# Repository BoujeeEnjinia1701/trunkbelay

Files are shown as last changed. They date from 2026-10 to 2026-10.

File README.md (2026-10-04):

# TrunkBelay

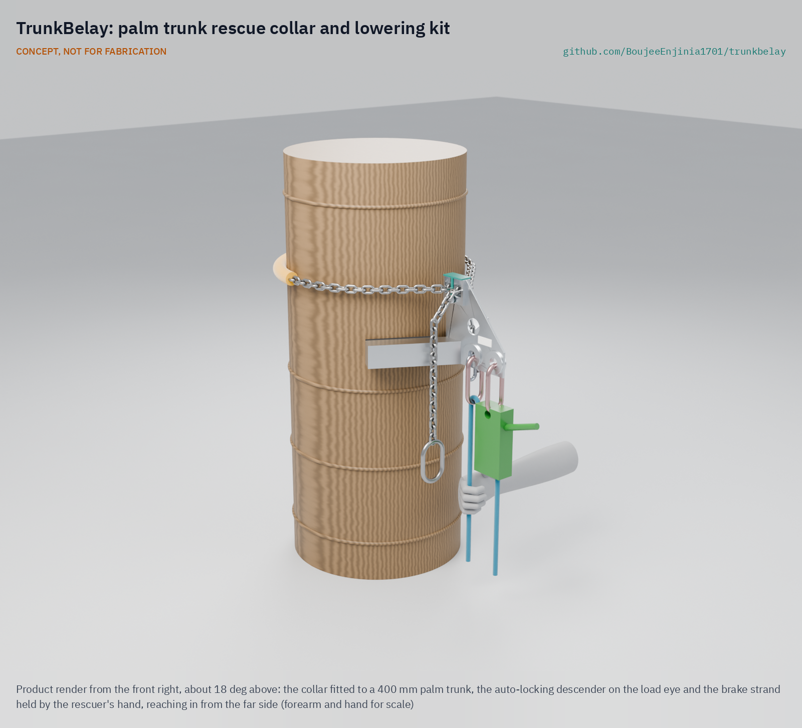
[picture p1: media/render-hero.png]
TrunkBelay: palm trunk rescue collar and lowering kit


     

**Area:** Food and water security · **TRL:** 3 of 9 (analytical proof of concept, constructable design) · **Value-engineering target:** USD 900; estimated cost of the constructable design USD 826 (USD 74 under the target) · **Difficulty:** 3 of 5

Lets a fellow climber anchor and lower a climber stranded high on a palm trunk.

## Concept rationale

TrunkBelay gives a second climber, usually a fellow plucker who is already on site, the means to act. It is a kit of a chain-and-cleat collar and a rope. The rescuer climbs the trunk, fixes the collar round the palm below the stranded climber, clips the climber to the rope, takes their weight through a friction device on the collar, frees them from their climbing device and lowers them to the ground under control.

Collars that grip a pole are familiar to utility linemen, and the industry sells dedicated pole-top rescue kits and training aids ([Buckingham](https://buckinghammfg.com/products/supersqueeze-pole-top-rescue-488p/)). Coconut climbers have neither the kit nor the training. An open, low-cost design that local workshops can build, with a simple drill that fire services and climber training programmes can teach, closes that gap. It is published as an open engineering reference, not certified rescue equipment.

## Burning platform

Climbing is dangerous work. In a study of 220 coconut tree climbers in rural Kerala and Tamil Nadu, 35.5 % had fallen at least once, the survey recorded four deaths from falls, and 18 of the 19 climbers who left the trade did so because of occupational injury ([George et al., JCDR, 2012](https://www.jcdr.net/article_fulltext.asp?id=1829)). In Tanzania, a referral hospital treated 44 men with spinal injuries after coconut tree falls over five years; 47.7 % had complete injuries at admission ([World Neurosurgery, 2023](https://www.sciencedirect.com/science/article/abs/pii/S1878875023004023)).

Falls are not the only emergency. In Kerala, climbers regularly end up suspended head down from their climbing devices. In September 2025, a plucker hung upside down for about 150 minutes on a 70 ft (21 m) palm ([Onmanorama, 2025](https://www.onmanorama.com/news/kerala/2025/10/02/coconut-plucker-hanging-upside-down-rescued-by-friend-firefighters.html)); in January 2026 another hung for about 30 minutes after his device's cables slipped on a curved palm ([Onmanorama, 2026](https://www.onmanorama.com/news/kerala/2026/01/31/coconut-tree-man-trapped-fire-rescue.html)); in February 2026 a third was caught by a fire officer when his leg came free of the device ([Onmanorama, 2026](https://www.onmanorama.com/news/kerala/2026/02/08/fire-officials-save-60-year-old-man-hanging-upside-down-coco.html)). India's Coconut Development Board runs an accident insurance scheme specifically for climbers ([PIB, 2022](https://www.pib.gov.in/PressReleasePage.aspx?PRID=1880306&reg=3&lang=2)), which shows the risk is recognised; insurance pays after the event, but it does not bring anyone down.

## Where it could be used

### By industry

| Industry | Use |
| --- | --- |
| Coconut and palm harvesting | Peer rescue of a climber stranded or unconscious on the trunk |
| Fire and rescue services | A light trunk anchor for crews reaching a stranded climber before ladders or nets arrive |
| Toddy tapping and palm sap collection | Rescue from single-stem palms climbed daily |
| Arecanut, date and other palm crops | Same collar and lowering method on other single-stem trunks |
| Climber training programmes | A standard rescue drill taught alongside machine climbing |

### By country or region

| Country or region | Why it matters there |
| --- | --- |
| India (Kerala and Tamil Nadu) | 35.5 % of 220 surveyed climbers had fallen at least once ([JCDR, 2012](https://www.jcdr.net/article_fulltext.asp?id=1829)), and suspended-climber rescues by fire crews keep recurring ([Onmanorama, 2025](https://www.onmanorama.com/news/kerala/2025/10/02/coconut-plucker-hanging-upside-down-rescued-by-friend-firefighters.html)). |
| India (southern coast) | Tree climbers made up 34.5 % of 29 coconut-related trauma cases at a southern Indian tertiary centre from 2021 to 2023 ([International Journal of Emergency Medicine, 2025](https://link.springer.com/article/10.1186/s12245-025-00816-4)). |
| Tanzania | 44 spinal injury cases after coconut tree falls at one national referral institute in five years ([World Neurosurgery, 2023](https://www.sciencedirect.com/science/article/abs/pii/S1878875023004023)). |
| Solomon Islands | Falls from trees caused 14 % of injuries at the national referral hospital from 1994 to 2011, and coconut trees were the largest share of those ([MJA, 2014](https://www.mja.com.au/journal/2014/201/11/barking-wrong-tree-injuries-due-falls-trees-solomon-islands)). |

## What sparked the idea

On 30 September 2025 in Kasaragod, Kerala, coconut plucker P Babu blacked out while cleaning a palm crown and was left hanging upside down, his feet still strapped into his metal climbing device, about 70 ft up. His friend of 30 years, M Sasi, climbed up, tied him to the trunk with towels and rope and held his head up until firefighters arrived with a ladder and rescue nets, about 150 minutes in all ([Onmanorama, 2025](https://www.onmanorama.com/news/kerala/2025/10/02/coconut-plucker-hanging-upside-down-rescued-by-friend-firefighters.html)). Sasi did everything right with what he had. TrunkBelay asks what he could have done with a collar and a rope.

## Problem

Coconut climbers who black out or slip can end up hanging upside down from their climbing device high on a palm, and the people nearby have no way to anchor and lower them. They hold on and wait, sometimes for hours, for a fire crew with ladders and nets.

Full problem statement: [docs/01-problem.md](docs/01-problem.md)

## Concept

An aluminium collar frame with two rubber-faced bars in a V is held on the palm trunk by a 6 mm grade 80 chain locked in two slots on its top. The load hangs from an eye 150 mm out from the frame, so the frame cocks on the trunk and grips harder as the load rises. A second climber fixes the collar, the helpers haul the rope bag up on a tag line, and the rescuer clips an auto-locking descender to the collar, fits the pre-rigged evacuation triangle and chest sling to the stranded climber, frees their feet and lowers them to the helpers on the ground. On paper it fits trunks from 200 to 450 mm, holds 2.5 kN with a locking factor of 1.54 or more, and needs about 80 N at the brake hand for a 100 kg person. The rescuer carries 4.55 kg up the trunk, under the 5 kg target, and the kit costs about USD 826, under the USD 850 per kit that Amish set for R9.

Full design precis: [docs/02-concept.md](docs/02-concept.md) · Requirements: [docs/03-requirements.md](docs/03-requirements.md) · Calculations: [docs/04-calcs/01-sizing.md](docs/04-calcs/01-sizing.md) · Prototype build plan: [docs/05-build-plan.md](docs/05-build-plan.md) · Design decisions: [docs/06-design-decisions.md](docs/06-design-decisions.md) · General arrangement: [cad/drawings/TKB-DWG-001.pdf](cad/drawings/TKB-DWG-001.pdf) · 3D viewer: [media/viewer.html](media/viewer.html)

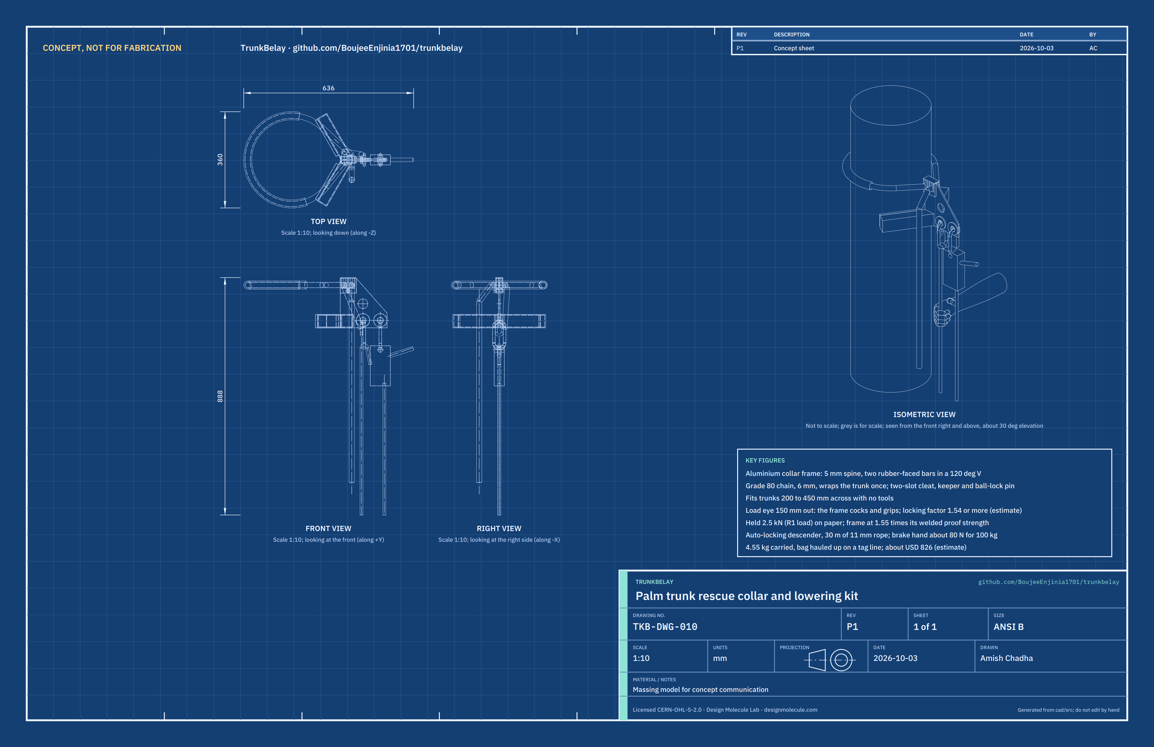
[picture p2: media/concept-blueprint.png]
Concept blueprint


## Key components

- Collar frame: 5 mm aluminium spine, two bearing bars in a 120 deg V, eye doubler rings and cleat cheeks, TIG welded 6082-T6
- Rubber bark pads
- Chain cleat keeper and ball-lock pin
- Chain, 6 mm grade 80, 110 links, with sleeve, master link and tether quick link
- Auto-locking descender with a brake carabiner
- Lowering rope, 30 m of 11 mm semi-static
- Evacuation triangle, chest sling and victim carabiner
- Rope and carry bag
- Tag line, 4 mm, with a micro pulley, so the helpers haul the bag up

## Building the prototype

The prototype is built to a plan, not yet built: [docs/05-build-plan.md](docs/05-build-plan.md) (TKB-BLD-001). The collar frame is profile cut from 5 mm aluminium plate and TIG welded to two short box-section bars, eye rings and cleat cheeks in a fabrication shop with an AC TIG welder; the pads are cut from rubber sheet and the keeper bent from sheet. The chain, rigging and rescue gear are bought to specification. Every component has a making sketch and every assembly step a picture, and nobody is lowered with the kit before a proof test on cut trunk sections and a dummy drill at low height.

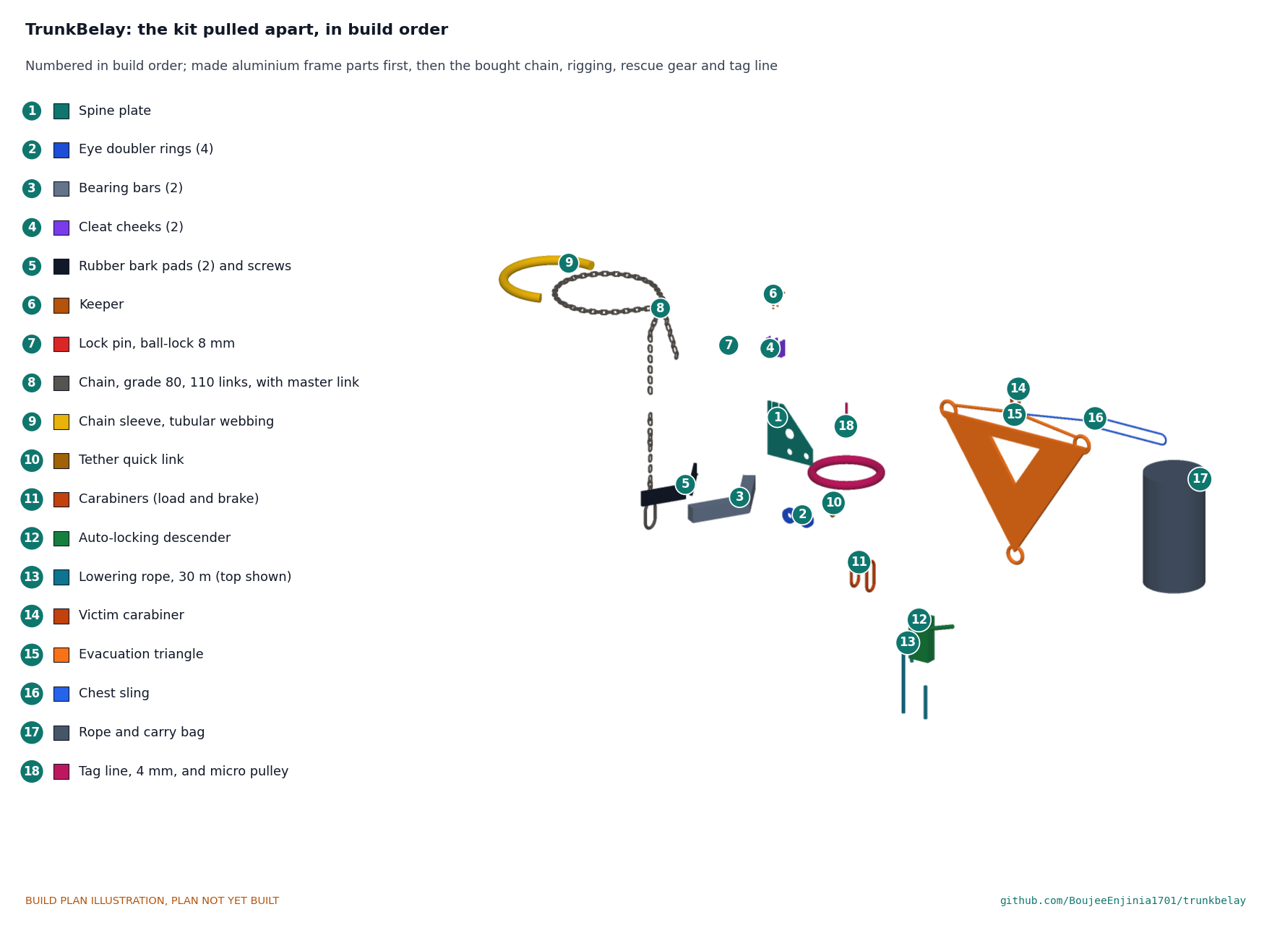
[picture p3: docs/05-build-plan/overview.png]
The kit pulled apart, in build order


## Safety

> Rope rescue and work at height: published as an open engineering reference, not certified rescue or fall-protection equipment.
>
> Only people trained in the drill should use it; practise at low height first.
>
> Always call emergency services as well; TrunkBelay is for the minutes before they arrive.
>
> The collar can slip on wet, fibrous bark under shock load; load it gently and never let the victim drop onto it.
>
> A person hanging head down for a long time needs medical assessment after rescue.
>
> The collar is not used on a person before it has been proof-tested at 2.5 kN on cut trunk sections and the drill has been run with a dummy at low height.
>
> This design is published as an open engineering reference. It is not certified equipment. CONCEPT, NOT FOR FABRICATION.

## Repository layout

| Folder | Contents |
| --- | --- |
| `docs/` | Problem, concept, requirements, calculations and design decisions |
| `cad/src/` | build123d Python source, the source of truth for all geometry |
| `cad/step/`, `cad/stl/` | Exported models for FreeCAD, other CAD tools and printing |
| `cad/drawings/` | 2D sketches and dimensioned drawings |
| `bom/` | Bill of materials |
| `electronics/` | KiCad schematics and PCB layouts |
| `firmware/` | Microcontroller code |
| `media/` | Renders, perspectives and photos |
| `build-log/` | Dated prototyping notes |

## Documentation

Controlled documents follow the portfolio [documentation standard](.kit/STANDARDS.md). Each carries a document ID (TKB-PRC-001 for the precis), a version and a revision history. Branded PDFs are built with `python .kit/render.py` and attached to GitHub Releases when a document is tagged, for example `TKB-PRC-001/v1.0`.

## Credits

Designed by Amish Chadha at Design Molecule Labs. See [CONTRIBUTORS.md](CONTRIBUTORS.md) for roles. To cite this design, use [CITATION.cff](CITATION.cff) (GitHub shows it as "Cite this repository").

AI assistance (Claude) was used to accelerate prototype documentation and first-pass research. Design direction and all decisions are Amish Chadha's, recorded in this repository's decision records (`docs/decisions/`).

## Licenses

- **Hardware** (CAD, drawings, BOM, electronics): [CERN-OHL-S v2](LICENSE)
- **Software** (firmware, scripts, notebooks): [MIT](LICENSE-SOFTWARE)

A project of the [Design Molecule](https://designmolecule.com) lab.

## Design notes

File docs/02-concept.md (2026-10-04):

---
doc_id: TKB-PRC-001
title: TrunkBelay design precis
project: TrunkBelay
doc_type: Precis
version: "0.4"
status: Draft
date: '2026-10-03'
author: Amish Chadha
license: CERN-OHL-S-2.0
revisions:
- version: "0.1"
  date: '2026-09-30'
  author: Amish Chadha
  change: Initial scaffold
- version: "0.2"
  date: '2026-10-03'
  author: Amish Chadha
  change: TRL 2 precis; how it works, components with BOM numbers, key design choices, first-order numbers, safety
- version: "0.3"
  date: '2026-10-03'
  author: Amish Chadha
  change: TRL 3; constructable design of TKB-DDR-002 and figures from TKB-CAL-001
- version: "0.4"
  date: '2026-10-03'
  author: Amish Chadha
  change: Amish's decisions carried out (TKB-DDR-003); aluminium frame, tag-line haul, pre-rigged victim set; figures from TKB-CAL-001 v0.2
---

# TrunkBelay design precis

Lets a fellow climber anchor and lower a climber stranded high on a palm trunk.

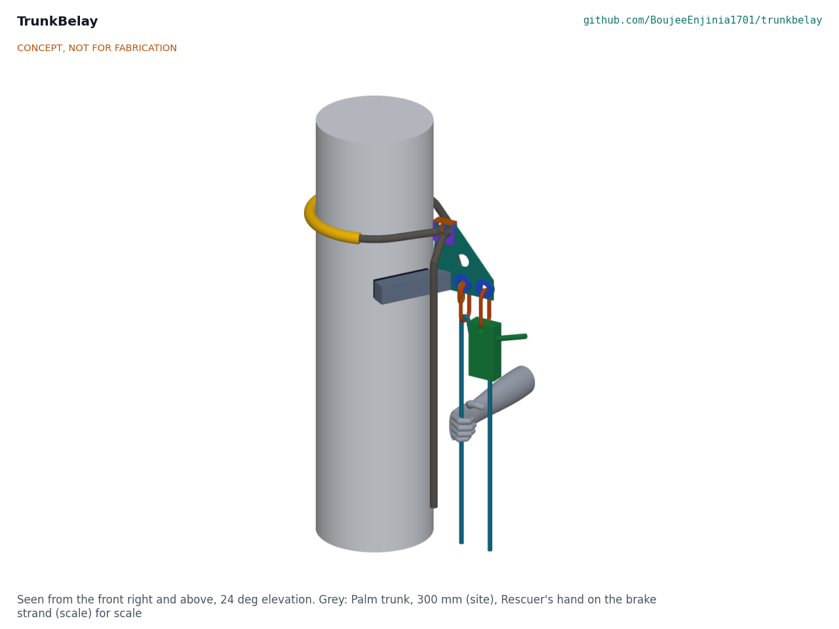
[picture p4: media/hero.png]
Figure 1. TrunkBelay collar on a 300 mm palm trunk, with the descender and rope


*Figure 1. The collar on a 300 mm trunk, seen from the front right and above. The grey hand on the brake strand gives the scale.*

## How it works

TrunkBelay is an aluminium collar that grips a palm trunk harder the more load hangs from it, with a commodity rope descender clipped to it. The rescuer climbs on their own climbing device to just below the stranded climber, carrying the collar, the chain and the descender (about 4.6 kg) and a micro pulley with a 4 mm tag line running through it to the helpers on the ground, and works in four stages.

1. **Fix the collar.** The rescuer holds the collar frame against the trunk, with its two rubber-faced bearing bars touching the bark, passes the chain round the trunk, drops a link into the open slot on top of the frame, pulls the chain snug and slips the keeper and lock pin on. The frame is set at least 300 mm above the point where the rope will meet the victim.
2. **Rig the lowering.** The helpers haul the rope bag up on the tag line. The descender is clipped to the load eye at the outer end of the frame and the rope reeved through it. The brake strand turns over a carabiner on the spare eye and runs down to the rope bag, which is lowered to the helpers on the ground.
3. **Take the weight.** The victim set comes out of the bag pre-rigged: the rope's end loop, the triangle's two waist loops and one end of the chest sling are already on the victim carabiner. The rescuer fits the triangle round the victim's hips and the sling round the chest, makes the last two clips (the crotch loop and the sling's free end) and pulls all slack through the descender, which locks.
4. **Free and lower.** The rescuer frees the victim's feet from the climbing device. The victim turns head up in the triangle and hangs from the collar. The rescuer opens the descender with its handle and lowers the victim to the helpers, holding the brake strand. The rescuer then takes the kit down and descends on their own device.

The load eye sits 150 mm out from the frame. The pull of the rope on the eye tilts the frame on the trunk: the bearing bars press the bark low on the near side and the chain presses it high on the far side. The friction at those two places rises in step with the load, so the collar is self-locking, like a drawer that jams when it is pulled from one corner (TKB-CAL-001, section B).

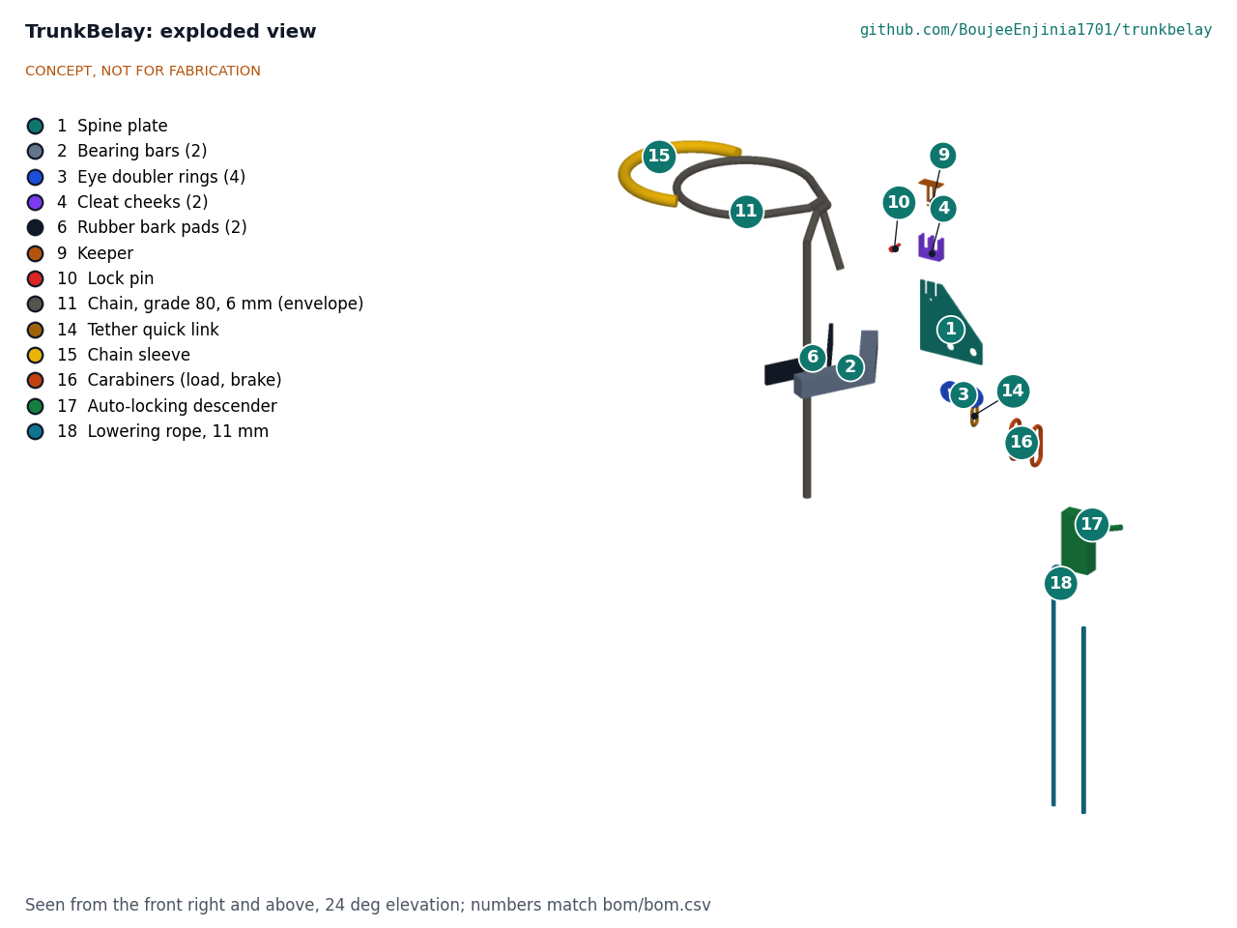
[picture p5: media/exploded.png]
Figure 2. The kit's parts pulled apart, with BOM numbers


*Figure 2. Exploded view; numbers match bom/bom.csv.*

## Components

*Table 1. Components and their BOM lines.*

| BOM | Component | Role |
| --- | --- | --- |
| 1 | Spine plate | 5 mm 6082-T6 aluminium plate in the frame's centre plane: carries the bearing bars at its foot, the chain slots at its top and the load and spare eyes at its outer end |
| 2 | Bearing bars (2) | 50 x 40 x 3 mm aluminium box section set in a 120 deg V at the foot of the spine; they bear on the bark through the pads |
| 3 | Eye doubler rings (4) | Thicken both eyes to 13 mm so a carabiner bears on a rounded, wide edge |
| 4 | Cleat cheeks (2) | 8 mm aluminium; stiffen the slotted top of the spine; notched so the chain links bear on the 5 mm web |
| 5 | TIG welding | The frame is one TIG-welded aluminium piece, left bare |
| 6, 7, 8 | Rubber bark pads (2), screws, adhesive | 10 mm rubber on each bar spreads the load on the bark and adds grip |
| 9, 10 | Keeper and lock pin | Hold both chain links down in their slots |
| 11 to 14 | Chain set | 6 mm grade 80 chain, 110 links, with a master link on the adjustable end and a quick link tethering the fixed end to the spare eye |
| 15 | Chain sleeve | 600 mm of tubular webbing on the chain where it bears on the back of the trunk |
| 16 | Carabiners (3) | Load eye to descender, brake redirect, victim connector |
| 17 | Auto-locking descender | Controls the lowering; locks if the rescuer lets go |
| 18 | Lowering rope | 30 m of 11 mm semi-static rope |
| 19, 20 | Evacuation triangle and chest sling | Hold the victim head up once the feet are freed |
| 21 | Rope and carry bag | Holds the rope and the pre-rigged victim set; hauled up on the tag line, then lowered to the ground with the spare rope |
| 22, 23 | Tag line and micro pulley | 55 m of 4 mm cord doubled through a micro pulley on the rescuer's harness; the helpers haul the bag up on it |

## Key design choices

All were made under Amish's pre-approval of 2026-10-03 and are recorded in TKB-DDR-001 and TKB-DDR-002. Amish decided the four requirement questions on 2026-10-03 (TKB-DDR-003): "i agree with all the 46 recommendations you provided. please proceed."

- **Self-locking frame, not a tightened band.** The grip comes from the load's lever on the frame, so it does not depend on how hard the rescuer pulled the chain. The chain only has to be snug.
- **A V of two bars, not a curved saddle.** A 120 deg V touches any trunk from 200 to 450 mm on two lines and centres itself; a curved saddle fits only one size.
- **A generic slotted cleat, no ratchet.** Chain links drop into two plain slots in the spine top and are held by a keeper and pin. This keeps clear of the ratcheting cinch geometry of the 3M DBI-SALA Cynch-Lok (the patent design-around) and has no moving parts to clog with bark.
- **Auto-locking descender.** The conservative choice: if the rescuer is hit, faints or lets go, the descender holds the victim.
- **Brake strand to the ground.** The spare rope goes down to the helpers, so the rescuer does not manage a rope bag at height.
- **Aluminium, TIG welded (decision 18C).** 6082-T6 plate and box section, sized on the weaker metal beside the welds; it takes about 1.9 kg off the climb compared with the same parts in steel. It needs an AC TIG welder rather than a stick welder, and nothing is galvanised.
- **The bag comes up on a tag line (decision 18C).** The rescuer carries only what fixes the collar and controls the lowering; the helpers haul the rope and the victim set.
- **Victim set packed pre-rigged (decision 17B).** Saves about 45 s at height, which offsets the time the haul takes.
- **The collar always goes above the victim's attachment (decision 16A).** The collar holds only a downward pull, so the drill keeps it at least 300 mm above the point where the rope meets the victim; a double-acting collar is the recorded fallback.
- **The safe rescue gear stays (decision 19A).** The auto-locking descender and the evacuation triangle are kept; cost is to come down through group purchase, not by cheaper gear.

## First-order numbers

From TKB-CAL-001; assumptions are stated there.

*Table 2. Key figures (estimates).*

| Quantity | Value |
| --- | --- |
| Trunk range | 200 to 450 mm across, no tools |
| Working load on the collar, 100 kg person | 0.99 kN |
| Static load the collar is sized for (R1) | 2.5 kN |
| Friction needed to lock, 200 mm trunk (worst) | 0.58, against about 0.9 assumed on wet bark; locking factor 1.54 |
| Frame settles under 2.5 kN | About 10 mm |
| Strength at 2.5 kN | Frame 1.55 times its welded proof strength or better; chain 8.1 times its breaking force; rope 5.7 times at the knot |
| Hand force on the brake strand, 100 kg | About 80 N |
| Rope | 30 m; 28 m needed for a 25 m lowering |
| Rigging time once in position | About 4.5 minutes (estimate), the haul included |
| Mass | 4.55 kg carried up the trunk; 3.7 kg bag hauled up; 8.3 kg in all |
| Cost | Value-engineering target: USD 900. Estimated cost of the constructable design: USD 826 (USD 74 under the target); R9 as restated, USD 850 |

## Patent design-arounds

From the preliminary patent, trademark and prior-art screen (not legal advice):

- Generic chain-and-cleat collar; avoid the 3M Cynch-Lok ratcheting cinch geometry and cleated-plate arrangement. The constructable design has no ratchet, no cam and no cleated gripping plate: plain slots, rubber-faced bars and a lever.
- CA2681870C (Bashlin) lapsed in 2015; WO2012131439A1 ceased; neither blocks the concept.

## Shared blocks

- CalRig proof-load (collar slip and proof tests on trunk sections)
- PalmSpan collar data (shelved sibling), for grip across palm sizes

## Safety

> **Safety:** TrunkBelay is rope rescue and work-at-height equipment. A slip of the collar, a wrongly fitted triangle or a lost brake hand can drop a person from 6 to 25 m. It is published as an open engineering reference, not certified rescue or fall-protection equipment.
>
> - Only people trained in the drill use it, and they practise at low height first.
> - Always call emergency services as well; TrunkBelay is for the minutes before they arrive.
> - The collar is not used on a person before it has been proof-tested at 2.5 kN on cut trunk sections and the drill has been run with a dummy at low height (TRL 4). The build plan's safety stops gate both.
> - The collar is loaded gently. All slack is taken in before the victim's feet are freed, so the victim never drops onto the collar (TKB-CAL-001, A2).
> - The collar is set above the point where the rope meets the victim, so it is never pulled upward.
> - A person hanging head down for a long time needs medical assessment after rescue.

This design is published as an open engineering reference. It is not certified equipment.

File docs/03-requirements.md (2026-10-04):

---
doc_id: TKB-REQ-001
title: TrunkBelay requirements
project: TrunkBelay
doc_type: Requirements
version: "0.3"
status: Draft
date: '2026-10-03'
author: Amish Chadha
license: CERN-OHL-S-2.0
revisions:
- version: "0.1"
  date: '2026-09-30'
  author: Amish Chadha
  change: Initial scaffold
- version: "0.2"
  date: '2026-10-03'
  author: Amish Chadha
  change: Status of every requirement on paper at TRL 3 (TKB-CAL-001); targets unchanged
- version: "0.3"
  date: '2026-10-03'
  author: Amish Chadha
  change: Amish's decisions 16A, 17B, 18C and 19A carried out (TKB-DDR-003); R9 target restated by Amish; status of R2, R4, R7 and R9 updated
---

# TrunkBelay requirements

Requirements with their status on paper at TRL 3. The targets are unchanged from version 0.1 except R9, which Amish restated on 2026-10-03; they are to be confirmed with the co-design partner. The status column comes from the calculation note TKB-CAL-001 v0.2.

Amish Chadha, 2026-10-03, on the recommendations put to him: "i agree with all the 46 recommendations you provided. please proceed." For TrunkBelay that is decisions 16A (R2: keep the drill rule, double-acting collar as the recorded fallback), 17B (R4: pack the victim set pre-rigged), 18C (R7: the helpers haul the rope bag on a tag line and the collar frame goes to aluminium) and 19A (R9: keep the auto-locking descender and evacuation triangle, seek group purchase, restate the cost target). The design decisions register (TKB-DEC-001) and decision record TKB-DDR-003 hold the detail.

Table 1. Requirements

| ID | Requirement | Target | Verification (TRL 3 or later) | Status on paper (TRL 3) |
| --- | --- | --- | --- | --- |
| R1 | Collar holds on a palm trunk | No slip greater than 20 mm under a 2.5 kN (562 lbf) static downward load on wet trunk sections | Proof test on CalRig with cut trunk sections at TRL 3 | Met on paper; the friction on wet bark is to be confirmed (locking factor 1.54, settles about 10 mm) |
| R2 | Collar holds when load direction changes | No slip greater than 50 mm when a 100 kg (220 lb) test mass passes the collar during lowering | Drop and transition tests on trunk sections; the upward case as a misuse test only | At risk for an upward pull: the single top chain cannot hold it. Decided by Amish (16A): the drill rule stays (collar at least 300 mm above the victim's attachment); the double-acting collar is the recorded fallback if the TRL 4 drill shows a rescuer cannot reach above the attachment |
| R3 | Fits common palms | Trunk diameters 200 to 450 mm (8 to 18 in) without tools | Fit trials on surveyed palms | Met: the V and the 110-link chain fit the whole range |
| R4 | Quick to rig | Collar fixed and victim clipped in under 5 minutes by a trained climber | Timed drills at 3 m height | At risk: about 4.5 minutes estimated, a thin margin; the pre-rigged victim set (17B) saves 45 s and the tag-line haul (18C) adds 45 s |
| R5 | Controlled lowering | Descent speed held under 0.5 m/s with hand force under 150 N (34 lbf) for a 100 kg (220 lb) load | Lowering tests with test mass | Met on paper: about 80 N at the hand with the brake carabiner |
| R6 | Rope length | Lowers from 25 m (82 ft) | Measured | Met: 30 m of rope, 28 m needed |
| R7 | Portable | Kit mass under 5 kg (11 lb); carried hands-free while climbing | Weighing and climbing trial | Met on paper: 4.55 kg carried with the aluminium frame and the rope bag hauled up on the tag line (18C); whole kit 8.3 kg |
| R8 | No damage to the palm | No bark cuts deeper than 5 mm after a full test lowering | Inspection after trials | Met on paper; to confirm by test (pads 1.9 MPa, sleeve 0.6 MPa at 2.5 kN) |
| R9 | Cost | Parts under USD 850 per kit at single-kit prices, keeping the auto-locking descender and the evacuation triangle; group purchase by the training partner sought to lower it, one kit per climber group. Restated by Amish (19A); was USD 100 | Costed bill of materials | Met on paper: USD 826 per kit (USD 24 under) |
| R10 | Teachable | Climbers new to the kit complete a supervised rescue drill after a half-day session | Training trial with partner programme | Cannot be shown on paper; training trial at TRL 4 |

## Assumptions

- A second climber is often on site or nearby when a climber is stranded, as in the reported cases.
- The rescuer can reach and work just below the victim using their own climbing device.
- Coconut bark and fibre can carry a collar load without crushing, if the load is spread.
- Victims can be fitted with a sling while hanging head down.

## Safety

> **Safety:** These requirements describe rope rescue equipment that holds a person at height. Meeting them on paper does not make the kit safe to use. Each is verified by test at TRL 4, and the kit is not used on a person until R1 has been proof-tested on cut trunk sections and the drill has been run with a dummy at low height.

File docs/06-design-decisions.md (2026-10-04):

---
doc_id: TKB-DEC-001
title: TrunkBelay design decisions register
project: TrunkBelay
doc_type: Design decisions register
version: "0.2"
status: Draft
date: '2026-10-03'
author: Amish Chadha
license: CERN-OHL-S-2.0
revisions:
- version: "0.1"
  date: '2026-10-03'
  author: Amish Chadha
  change: Register opened; design decisions made under Amish's 2026-10-03 pre-approvals; requirements not met or at risk posed for Amish
- version: "0.2"
  date: '2026-10-03'
  author: Amish Chadha
  change: Open decisions O1 to O4 decided by Amish (16A, 17B, 18C, 19A) and moved to Decisions made; items to confirm and value engineering updated
---

# TrunkBelay design decisions register

Every design decision still to be made, and every decision made, in one place. Each decision is argued in full in its decision record under `docs/decisions/` or in the review note; this register is the index Amish works from. The build plan (`docs/05-build-plan.md`) describes the design as it stands and does not list decisions.

> **Safety:** Several entries below set safety limits (the one-person rating, the proof test, the auto-locking descender, where the collar is placed). Each takes the conservative option and names the evidence that would relax it. Nobody is lowered with this kit before the collar has been proof-tested at 2.5 kN on cut trunk sections and the drill has been run with a dummy at low height.

## Open decisions

None. Amish decided the four open decisions (O1 to O4) on 2026-10-03: "i agree with all the 46 recommendations you provided. please proceed." They are recorded under Decisions made and in TKB-DDR-003. R2 and R4 remain at risk on paper and are settled by the TRL 4 drill and timed trial (items 9 and 10 below); nothing in carrying out the decisions needs a new decision from Amish.

## To confirm when parts are bought

These are facts that can only be settled with real parts, real trunks or the training partner. None changes a decision; each may change a size or a limit.

*Table 2. Items to confirm.*

| # | What to confirm | Why it matters | Source |
| --- | --- | --- | --- |
| 1 | Friction of the rubber pad and of the webbing-sleeved chain on wet coconut bark (0.5 and 0.4 assumed) | The lock needs 0.58 combined on a 200 mm trunk; this is the first test | TKB-CAL-001, B4; TKB-DDR-002, A1 |
| 2 | The chain bought: inner length at least 18 mm and wire 6.0 to 6.3 mm, so a link spans the 5 mm web and fits the 7.5 mm slot; certificate | Cleat geometry | TKB-DWG-101 and 108 |
| 3 | The descender bought: rope range, one-person rating, friction or hand force at 100 kg, and how its brake strand leaves the body | Hand force about 80 N; the brake carabiner's position | TKB-CAL-001, D1; TKB-DDR-002, A3 |
| 4 | The rope bought: breaking strength, stretch and mass per metre | Rope factor, slack-drop load and kit mass | TKB-CAL-001, A2, C6 and F1 |
| 5 | Rubber hardness and the bond of contact adhesive to bare 6082 aluminium | Pad squash and pad security | TKB-CAL-001, B5 |
| 6 | Trunk diameters and shapes in the first partner's area | The 200 to 450 mm range and the 110-link chain | TKB-REQ-001, R3; TKB-DDR-002, A6 |
| 7 | Whether the triangle can be fitted to a head-down dummy in the time estimated | Rigging time | TKB-CAL-001, E3 |
| 8 | That the brake carabiner and the 8 mm quick link sit side by side in the 22 mm spare eye | Spare eye layout | Build plan, Figure 16 |
| 9 | In the timed drill, that a rescuer can reach to set the collar at least 300 mm above the victim's attachment | If not, the recorded fallback for R2 (the double-acting collar) is built | TKB-DDR-003, 16A |
| 10 | The timed drill with the bag hauled on the doubled tag line and the victim set pre-rigged | R4 estimate of 4.5 minutes; whether the doubled line tangles while the rescuer climbs | TKB-DDR-003, 17B and 18C |
| 11 | Wear of the aluminium cleat web where the steel links bear (about 92 MPa at 2.5 kN), and no permanent set of the frame after the 2.5 kN proof test | The aluminium frame's smaller strength margins (1.55 on the welded proof strength) | TKB-CAL-001, C1 and C4 |
| 12 | Quotes for 6082-T6 plate and tube and AC TIG welding near the first partner | Cost of the aluminium frame (about USD 69 with welding) | bom/bom.csv, lines 1 to 5 |

## Value engineering

Value-engineering target: USD 900 (a hypothetical control target, not a limit). Estimated cost of the constructable design: USD 826 (USD 74 under the target). Against R9 as restated by Amish (USD 850 per kit at single-kit prices) the kit is USD 24 under. Main cost drivers and savings worth trying:

- The bought rescue gear is most of the cost: the auto-locking descender (USD 280), the evacuation triangle (USD 140), the rope (USD 105), the bag (USD 45) and three carabiners (USD 45). Amish kept the descender and triangle for safety (19A). The aluminium frame, including TIG welding, is about USD 69; the tag line and micro pulley about USD 39.
- Savings worth trying: group purchase of descenders, triangles and rope by the training partner for many kits; rope and cord bought by the reel; a plain stuff sack in place of a rope bag (about USD 30); welding frames in batches.
- One kit per climber group, rather than per climber, spreads the cost of the descender and triangle.

## Decisions made

*Table 3. Decisions made.*

| Date | Decision | Decided by | Record |
| --- | --- | --- | --- |
| 2026-10-03 | TRL 2 review items D1 to D10: self-locking frame with the load eye on a lever; two rubber-faced bars in a 120 deg V; the drill places the collar above the victim's attachment (the R2 question, O1, later decided as 16A); auto-locking descender with anti-panic and a brake carabiner; evacuation triangle with chest sling; spare rope lowered to the ground; one-person 100 kg rating sized for 2.5 kN; first co-design candidates (a climber training programme under the Coconut Development Board's Friends of Coconut Tree scheme in Kerala, a Kerala Fire and Rescue Services station in Kasaragod or Kannur, a climbers' collective in the same district; none approached yet); steel, welded and galvanised (superseded for the frame by aluminium, TKB-DDR-003); pitch, problem, design-arounds and budget unchanged | Amish, pre-approval of 2026-10-03: "start with the first 14 repos from the list of 29 projects. I pre-approve the batch runs along with any recommendations you come up with. I also accept any cost overruns or variations from the assumed scope cost." and, for this batch, "Proceed with the remaining 15 scaffolds" | TKB-DDR-001 |
| 2026-10-03 | Design for construction, changes C1 to C11: V of box bars with bonded and screwed pads, 5 mm spine plate, slotted cleat with notched cheeks, keeper and ball-lock pin, fixed end in a slot tethered to the spare eye, eyes with doubler rings, lever geometry, 110-link grade 80 chain with master link, chain sleeve, brake carabiner, galvanising (superseded by the bare aluminium frame, TKB-DDR-003) and marking | Amish, same pre-approvals | TKB-DDR-002 |
| 2026-10-03 | Assumptions A1 to A6: friction on wet bark, pad rubber, descender friction, rope stretch, bark limits, trunk range; each to be confirmed (Table 2) | Amish, same pre-approvals | TKB-DDR-002 |
| 2026-10-03 | No use on a person before a proof test of the collar at 2.5 kN on cut trunk sections and a dummy drill at low height (conservative; this is a gate, not relaxed) | Amish, same pre-approvals | TKB-BLD-001, section 6 |
| 2026-10-03 | O1 to O4 on the requirements not met or at risk. 16A (R2): keep the drill rule, collar at least 300 mm above the victim's attachment; double-acting collar recorded as the fallback. 17B (R4): pack the triangle and chest sling pre-rigged on the victim carabiner (45 s saved). 18C (R7): the helpers haul the rope bag up on a tag line and the collar frame goes to aluminium (4.55 kg carried, met). 19A (R9): keep the auto-locking descender and evacuation triangle, seek group purchase, R9 restated to USD 850 per kit (USD 826, met) | Amish, 2026-10-03: "i agree with all the 46 recommendations you provided. please proceed." | TKB-DDR-003 |
| 2026-10-03 | Appearance model departures for the renders only: a safe working load label on the spine, a 400 mm trunk with leaf-scar rings, the rope cut below the frame, and a clay forearm and hand on the brake strand | Amish, same pre-approvals | docs/REVIEW.md, TRL 3 section |

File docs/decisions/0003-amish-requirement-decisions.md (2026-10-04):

---
doc_id: TKB-DDR-003
title: TrunkBelay requirement decisions R2, R4, R7 and R9
project: TrunkBelay
doc_type: Design decision record
version: "0.1"
status: Draft
date: '2026-10-03'
author: Amish Chadha
license: CERN-OHL-S-2.0
revisions:
- version: "0.1"
  date: '2026-10-03'
  author: Amish Chadha
  change: Amish's decisions 16A, 17B, 18C and 19A on open decisions O1 to O4 recorded and carried out
---

# 0003: Requirement decisions R2, R4, R7 and R9

- **Date:** 2026-10-03
- **Status:** decided by Amish Chadha on 2026-10-03: "i agree with all the 46 recommendations you provided. please proceed." For TrunkBelay these are decisions 16A (O1, R2), 17B (O2, R4), 18C (O3, R7) and 19A (O4, R9), each the recommended option.

## Context

At TRL 3 the calculation note (TKB-CAL-001 v0.1) left four requirements not met or at risk on paper: R2 (the single top chain holds only a downward pull), R4 (about 4.5 minutes to rig, a thin margin), R7 (8.9 kg carried against 5 kg) and R9 (USD 758 a kit against USD 100). They were posed to Amish as open decisions O1 to O4 in the register (TKB-DEC-001) with options and a recommendation.

## Decisions

*Table 1. Decisions and how they were carried out.*

| # | Requirement | Decision | Carried out as | New result (TKB-CAL-001 v0.2) |
| --- | --- | --- | --- | --- |
| 16A | R2, load passing the collar | Keep the drill rule: the collar at least 300 mm above the victim's attachment. The double-acting collar (a second chain through a cheeked block at the frame foot, about 1.7 kg in steel and USD 45) is the recorded fallback | No hardware change. The rule is in the build plan's safety stop S6 and Step 10; the TRL 4 first checks test the upward case only as a misuse test and check in the timed drill that a rescuer can reach above the attachment | At risk for an upward pull, as before; avoided by the drill. If the TRL 4 drill shows a rescuer cannot reach above the attachment, the fallback is built |
| 17B | R4, rigging time | Pack the evacuation triangle and chest sling pre-rigged on the victim carabiner | The rope's figure-eight loop, the triangle's two waist loops and one end of the chest sling are packed on the victim carabiner; at height only the crotch loop and the sling's free end are clipped. Model: `victim_kit()` and three new checks that the straps, sling and rope loop meet the carabiner | Fitting 90 s (was 120 s), clipping in 15 s (was 30 s): 45 s saved, no cost, no mass |
| 18C | R7, kit mass | The helpers haul the rope bag up on a tag line, and the collar frame goes to aluminium | Frame weldment in 6082-T6, TIG welded with ER5356, not galvanised, sized on the heat-affected-zone strength (125 MPa): bars RHS 50 x 40 x 3 (were 50 x 25 x 2.5 steel); cheeks 8 mm (were 6); spine kept 5 mm (a link must span the cleat web) with its top raised 10 mm to 185 mm so the web beside each slot is 35 mm deep; doubler rings kept 4 mm (the quick link must pass round the spare eye); spare eye moved from 70 to 85 mm back, clear of the deeper bars; the adjustable chain tail runs out 75 mm before it hangs, clear of the bar; ball-lock pin grip 27 mm (was 23); pad screws into countersunk stainless rivet nuts. Tag line: 55 m of 4 mm cord doubled through a micro pulley on the rescuer's harness, both ends on the ground, so the helpers haul. Five new frame checks in the model | The rescuer carries 4.55 kg (target under 5 kg): met on paper. The helpers haul 3.7 kg. The haul adds about 45 s to rigging, offset by 17B, so R4 stays at about 4.5 minutes. Frame factors at the R1 load on the welded proof strength: bars 1.60, cleat web 1.55, cleat twist 2.0, welds 5.3 on the weld metal |
| 19A | R9, cost per kit | Keep the auto-locking descender and the evacuation triangle; seek savings by group purchase; restate the cost target | R9 restated in TKB-REQ-001 v0.3 as "parts under USD 850 per kit at single-kit prices, keeping the auto-locking descender and the evacuation triangle; group purchase by the training partner sought to lower it, one kit per climber group" (was USD 100) | USD 826 a kit, USD 24 under the restated target. Value-engineering target: USD 900. Estimated cost of the constructable design: USD 826 (USD 74 under the target) |

## Differences from the estimates put to Amish

- **Mass, 4.55 kg against about 4.4 kg.** The option assumed a 30 m tag line of 0.3 kg. To let the helpers haul from the ground (rather than the rescuer hauling at height), the line runs doubled through a micro pulley, so 55 m (0.60 kg) hangs from the rescuer at the top, plus a 0.05 kg pulley. The aluminium frame also came out lighter than the option's rough "40 % thicker" estimate, because only the parts that needed it were thickened.
- **Cost, USD 68 more against about USD 50.** The aluminium frame adds about USD 29 (6082 plate and tube, AC TIG welding and rivet nuts, less the galvanising) and the tag line and micro pulley about USD 39.
- **Frame strength.** The steel frame had factors of 2.1 to 3.8 on yield at the R1 load; the aluminium frame has 1.55 to 2.0 on the welded proof strength (2.3 or more on the welded ultimate strength). That is adequate for the 2.5 kN proof load, which is 2.5 times the working load, but the margins are smaller, and the proof test at TRL 4 must check for permanent set in the frame.

## Consequences

- The steel build plan is replaced by an aluminium one: a fabricator with an AC TIG welder is needed rather than a stick or MIG welder and a galvaniser. No weld may be added or repaired beyond the plan.
- The steel chain bears on the aluminium cleat web at about 92 MPa; wear of the slot faces is a new item to confirm at TRL 4. Stainless fixings sit in rivet nuts with barrier paste against galvanic corrosion.
- The kit gains a tag line and micro pulley (BOM lines 22 and 23); the victim carabiner travels in the bag.
- R2 and R4 remain at risk on paper and are settled by the TRL 4 drill and timed trial.

## Evidence

- `cad/src/model.py` (218 of 218 constructability checks pass), `docs/04-calcs/sizing.py` and `01-sizing.md` (TKB-CAL-001 v0.2), `bom/bom.csv`, `docs/03-requirements.md` (TKB-REQ-001 v0.3), `docs/05-build-plan.md` (TKB-BLD-001 v0.2), general arrangement TKB-DWG-001 Rev P2.

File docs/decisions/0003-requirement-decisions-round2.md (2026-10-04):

---
doc_id: TKB-DDR-003
title: TrunkBelay requirement decisions, round 2
project: TrunkBelay
doc_type: Design decision record
version: "0.1"
status: Draft
date: '2026-10-03'
author: Amish Chadha
license: CERN-OHL-S-2.0
revisions:
- version: "0.1"
  date: '2026-10-03'
  author: Amish Chadha
  change: Amish's decisions on open items O1 to O4 (portfolio decisions 41 to 44) carried into the design
---

# 0003: Requirement decisions, round 2

- **Date:** 2026-10-03
- **Status:** decided by Amish Chadha, 2026-10-03: "i approve all of the 47 recommendations provided by you. Execute them." For TrunkBelay these are portfolio decisions 41 to 44, the recommendations on open items O1 to O4 of TKB-DEC-001 v0.1, each taken exactly as recommended.

## Context

At TRL 3 (TKB-CAL-001 v0.1) four requirements were not met or at risk on paper: R2 (the collar holds only a downward pull), R4 (rigging about 4.5 minutes against 5), R7 (8.9 kg carried against 5 kg) and R9 (USD 758 a kit against USD 100). Each was posed to Amish with options and a recommendation in TKB-DEC-001. Three of the four (O1, O2 and O4) concern holding a person, so the safety notes below stay conservative.

## Options considered

*Table 1. Options.*

| # | Requirement | Options |
| --- | --- | --- |
| 41 (O1) | R2, load passing the collar | **A.** Keep the drill rule (collar 300 mm or more above the victim's attachment) and test the upward case only as a misuse test: no cost or mass, upward case stays unproven. **B.** Double-acting collar, a second chain through a slot block at the frame foot: R2 expected met on paper, about USD 45 and 1.7 kg more |
| 42 (O2) | R4, rigging time | **A.** Keep the drill and time it at TRL 4. **B.** Pack the victim set pre-rigged on the victim carabiner: about 45 s saved, no cost or mass. **C.** A quick-fit hip loop in place of the triangle: about 60 s saved and USD 100 less, but holds an unconscious person less securely |
| 43 (O3) | R7, kit mass | **A.** Helpers haul the rope bag up on a 4 mm tag line. **B.** Aluminium frame (6082-T6, 40 % thicker, TIG welded). **C.** Both A and B |
| 44 (O4) | R9, cost per kit | **A.** Keep the auto-locking descender and triangle. **B.** Two-sling hasty seat in place of the triangle. **C.** Workshop bar rack with a friction-hitch backup in place of the descender |

## Decision

*Table 2. Decisions and what changed.*

| # | Decision | What changed in the design |
| --- | --- | --- |
| 41 | **A**, with **B** as the fallback if the TRL 4 drill shows a rescuer cannot reach above the attachment | No hardware change. The drill rule stays: the collar is set 300 mm or more above the point where the rope meets the victim, so it is only ever pulled downward. The TRL 4 upward-pull test is a misuse test whose result is recorded but does not relax the rule. The timed drill at TRL 4 records whether the rescuer could reach above the attachment; if not, the double-acting collar (about USD 45 and 1.7 kg, estimate) is brought back to Amish. R2 stays at risk on paper, controlled by procedure |
| 42 | **B** | No new parts. The victim set is packed pre-rigged: the rope's figure-eight loop, the triangle's two side loops and one end of the chest sling are on the victim carabiner, and the triangle's crotch loop is the one clip made at height. Build plan step 10 and figure 28 changed. Fitting falls from about 120 s to about 75 s (estimate) |
| 43 | **C** | The frame is aluminium 6082-T6, TIG welded with ER5356 and left bare (no galvanising). The helpers keep the rope bag on the ground; the rescuer carries the collar, descender, load and brake carabiners and a 30 m, 4 mm tag line in a 10 l shoulder pouch (new BOM lines 22 and 23), and hauls the rope's loop end with the pre-rigged victim set up on the tag line. Sizes, see below |
| 44 | **A**, with savings sought through group purchase and one kit per climber group | No change to the parts. The auto-locking descender with anti-panic and the evacuation triangle stay. R9 stays not met by Amish's choice; the savings route is recorded in TKB-DEC-001 |

### How the aluminium frame was sized (decision 43)

The option was costed as each steel part 40 % thicker in aluminium. Checking that against strength showed two limits, and the parts were sized to the decision's intent (an aluminium frame that holds the R1 load) rather than to the 40 % figure:

- **Welding softens 6082-T6.** Beside a TIG weld the 0.2 % proof strength falls from 260 MPa to about 125 MPa, over about 30 mm (EN 1999-1-1). Every highly loaded section of this small frame is that close to a weld. A 40 % thicker bar (RHS 50 x 25 x 3.5) would carry 135 MPa at its weld at the R1 load of 2.5 kN, a factor of 0.92: it would yield below R1. The bars are therefore aluminium RHS **70 x 30 x 5**, 61 MPa, factor 2.0 at the R1 load (the steel bar had 2.1). The section is held to 30 mm deep to clear the spare eye's doubler ring and to 70 mm high to clear the chain's fixed-end tail; both clearances are new constructability checks.
- **The spine cannot be thickened.** The spine top is the web of the chain cleat, and a 6 mm grade 80 link (inner length 18 mm, wire up to 6.3 mm) must span it, which leaves 5.4 mm at most. The spine stays **5 mm**. The doubler rings go from 4 to **6 mm** and the cleat cheeks from 6 to **8 mm** (stock plate thicknesses at or above 40 % thicker). The keeper's bridge widens from 23 to 28 mm and the lock pin's grip from 23 to 28 mm.

*Table 3. Results (TKB-CAL-001 v0.2).*

| Item | Before | After |
| --- | --- | --- |
| R1 | Met on paper, friction to confirm | Met on paper, friction to confirm; the 5 mm aluminium cleat web has a factor of 1.1 on its heat-affected proof strength at the R1 load (2.3 on the parent metal, 2.8 at the working load), against 3.1 in steel. New open question O5 |
| R2 | At risk | At risk on paper, controlled by the drill rule (decision 41 A) |
| R4 | At risk, about 4.5 min | Met on paper (estimate), about 4.2 min: haul 45 s added, fitting 45 s saved, lowering the bag (20 s) no longer needed |
| R7 | Not met, 8.9 kg carried | Met on paper, 4.74 kg carried (257 g margin); whole kit 8.5 kg |
| R9 | Not met, USD 758 | Not met, USD 802 (accepted, decision 44 A) |
| Frame weldment | 2.22 kg steel, galvanised | 1.37 kg aluminium, bare (bars 0.92 kg) |
| Collar | 4.4 kg | 3.6 kg |
| Cost | USD 758 | USD 802: aluminium parts and TIG welding about USD 29 more than the steel parts, welding and galvanising; tag line and pouch about USD 16 (estimates) |
| Model | 210 constructability checks pass | 213 checks pass (bars to doubler rings added; chain tail to bars now the binding clearance at 6.7 mm) |
| Drawings | TKB-DWG-001 Rev P1 | TKB-DWG-001 Rev P2; making sketches TKB-DWG-101 to 107 and the build plan pictures regenerated |

## Consequences

- The frame now needs a fabricator with an AC TIG welder and a welder qualified on aluminium; "any village fabrication shop" no longer applies (TKB-DDR-001, D9, is superseded on material by this record).
- Galvanising is gone. Stainless screws in the aluminium bars are fitted with anti-seize; the zinc-plated keeper and quick link are compatible with aluminium.
- The grade 80 steel chain bears on and slides over aluminium slot edges, which will wear faster than steel. This is part of O5.
- The rescuer's carried mass meets R7 by only 257 g; any heavier descender or pouch would use it up.
- The rescuer depends on the helpers to send the rope up. If no helper is on the ground, the rescuer must carry the rope bag as well (8.5 kg, R7 not met for that case).

> **Safety:** TrunkBelay holds a person at height. These decisions keep the conservative choices: the auto-locking descender and the evacuation triangle stay (44 A), and the collar is used only with the drill rule that sets it 300 mm or more above the victim's attachment (41 A), because on paper it does not hold an upward pull. If a rescuer cannot reach above the attachment, the collar is not used that way; the double-acting collar is the fallback. The pre-rigged victim set must be checked before every use: carabiner gate screwed shut, loops not twisted, crotch loop free. The aluminium frame has less margin at the cleat than the steel one (O5). Nobody is lowered with the kit before the collar has been proof-tested at 2.5 kN on cut trunk sections and the drill has been run with a dummy at low height. It is not certified equipment.

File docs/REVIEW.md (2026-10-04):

# Review note: TrunkBelay

## Session 2026-09-30: scaffolded

### What was done

- Repository created from kit 1.6.0 at TRL 1, target TRL 2.
- `docs/01-problem.md` (TKB-PRB-001 v0.1): problem with cited evidence, users, environment, constraints, prior work, open questions.
- `docs/02-concept.md` (TKB-PRC-001 v0.1): how it works, components, patent design-arounds, shared blocks, safety.
- `docs/03-requirements.md` (TKB-REQ-001 v0.1): 10 proposed requirements.
- `README.md` with concept rationale, burning platform, where it could be used, and what sparked the idea.

### Next

- Run `/populate` to bring the repo to a strong TRL 2 with concept media.

## Session 2026-10-03: TRL 2 (populate)

Run as the first half of `/to-trl3` in Batch 2, under Amish's pre-approval of 2026-10-03: "start with the first 14 repos from the list of 29 projects. I pre-approve the batch runs along with any recommendations you come up with. I also accept any cost overruns or variations from the assumed scope cost." and his instruction of the same day: "Proceed with the remaining 15 scaffolds". Kit 1.7.0 installed.

### What was done

- `docs/01-problem.md` (TKB-PRB-001 v0.2): constraints restated with the value-engineering target, open questions answered on paper, first co-design candidates, safety section.
- `docs/02-concept.md` (TKB-PRC-001 v0.2, then v0.3 at TRL 3): how it works in four stages, components with BOM numbers, key design choices, first-order numbers, design-arounds kept, safety.
- `docs/03-requirements.md` (TKB-REQ-001 v0.2): targets unchanged; status on paper for all ten requirements.
- Concept media from `cad/src/concept_media.py`: `media/hero.png` (300 mm trunk and the rescuer's hand for scale), `media/concept-blueprint.png`, `.pdf` and `.svg` (TKB-DWG-010), `media/model.glb` (4.2 MB) and `media/viewer.html`, `media/exploded.png` with BOM callouts, `media/flow.png` (energy of a 25 m lowering, estimates). No cutaway: nothing inside matters to the concept. The chain is drawn as its envelope in the concept media.
- `bom/bom.csv`: 21 priced lines.

### Results

- The collar works on paper as a self-locking frame: the load on a lever makes the grip rise with the load.
- The open question of the load turning direction is avoided by the drill, not by the hardware; this is posed to Amish (R2, O1).

### Decisions made under the pre-approvals

TKB-DDR-001, D1 to D10: self-locking frame; V of rubber-faced bars; collar above the victim's attachment in the drill as modelled; auto-locking descender with a brake carabiner; evacuation triangle and chest sling; spare rope to the ground; one-person 100 kg rating at 2.5 kN; first co-design candidates (not approached); steel, welded and galvanised; pitch, problem, design-arounds and budget unchanged.

### Safety concerns

- A failure drops a person from up to 25 m. The kit is not certified equipment, and no one is lowered with it before a proof test and a dummy drill (TRL 4).

## Session 2026-10-03: TRL 3 (advance and build plan)

Run as the second half of `/to-trl3` under the same pre-approvals, which count as the TRL 2 approval.

### What was done

- `cad/src/model.py`: parametric build123d model of the constructable kit on 200, 300 and 450 mm trunks; 210 of 210 constructability checks pass (contacts, clearances to the trunk and between parts, chain links in the slots, pad contact point, chain length). Exports `cad/step/trunkbelay-assembly.step`, `cad/step/trunkbelay-frame-weldment.step` and two STL files in `cad/stl/`.
- `docs/04-calcs/01-sizing.md` (TKB-CAL-001 v0.1) with `docs/04-calcs/sizing.py` and `results.csv`: loads, grip and locking factor, strength, lowering, fit and rigging, mass, bark pressure, cost, and a results table against every requirement.
- `cad/src/sheets.py`: general arrangement `cad/drawings/TKB-DWG-001` (SVG, PDF, PNG) at Rev P1.
- `cad/src/build_plan_media.py`: `docs/05-build-plan/overview.png`, 9 making sketches `cad/drawings/TKB-DWG-101` to `109`, 8 joint close-ups and 10 step pictures.
- `docs/05-build-plan.md` (TKB-BLD-001 v0.1), `docs/06-design-decisions.md` (TKB-DEC-001 v0.1), `docs/decisions/0001-trl2-review-decisions.md` (TKB-DDR-001) and `docs/decisions/0002-design-for-construction.md` (TKB-DDR-002).
- `cad/src/product_model.py` (appearance model) and render scenes exported with `.kit/export_views.py` to `/home/claude/renders/trunkbelay` for hero, exploded and detail views; photoreal renders and cards are made on Amish's Mac.
- `project.yaml`: trl 3, trl_target 3, `design_state: constructable`, evidence listed; `budget_usd` unchanged. README leads with `media/render-hero.png` and has a "Building the prototype" section.

### Results

- Locking factor 1.54 on a 200 mm trunk, 1.86 on 300 mm and 2.35 on 450 mm, against an assumed combined friction of 0.9 on wet bark (0.58 needed at worst). The frame settles about 10 mm at 2.5 kN.
- At 2.5 kN: bearing bars 2.1 times yield, welds 3.5, cleat web 3.1, chain 8.1 on breaking force, rope 5.7 at the knot, carabiners 10.
- Brake hand force about 80 N for 100 kg with the brake carabiner (about 150 N without it).
- A slack drop of 30 mm when the feet are freed gives about 2.6 kN; the drill takes in all slack first.
- Rope 28 m needed of 30 m; rigging about 4.5 minutes once in position (estimate).
- Mass: collar 4.4 kg, kit 8.9 kg.
- Value-engineering target: USD 900. Estimated cost of the constructable design: USD 758 (USD 142 under the target).

### Requirements not met

- R7: 8.9 kg carried (not met).
- R9: USD 758 a kit, over the value-engineering target of R9 by USD 658 (not met).
- R2: at risk; the single top chain holds only a downward pull.
- R4: at risk; about 4.5 minutes on a rough estimate.
- R10 cannot be shown on paper (training trial at TRL 4). R1, R5 and R8 are met on paper subject to the items to confirm.

### Decisions for Amish

Proposed, awaiting Amish (also in TKB-DEC-001, Open decisions).

**O1, R2 (load passing the collar).** State: on paper the collar holds only a downward pull; with one chain at its top, an upward pull on the load eye has no second contact below to hold against. The drill as modelled avoids the case by setting the collar 300 mm or more above the victim's attachment.
- A. Keep the drill rule; test the upward case only as a misuse test and check in the timed drill that a rescuer can reach above the attachment. No cost or mass; the upward case stays unproven.
- B. Double-acting collar: a second chain through a cheeked slot block at the frame foot, so it locks either way. R2 expected met on paper; about USD 45 and 1.7 kg more (worsens R7).
- **Recommendation: A**, with B as the fallback if the TRL 4 drill shows a rescuer cannot reach above the attachment.

**O2, R4 (rigging time).** State: about 4.5 minutes once in position, a thin margin on a rough estimate; fitting the triangle and chest sling (about 2 minutes) is the largest part.
- A. Keep the drill and time it at TRL 4. No cost or mass.
- B. Pack the victim set pre-rigged (triangle loops and chest sling already on the victim carabiner with the rope's loop): about 45 s saved, about 3.8 minutes; no cost or mass.
- C. A quick-fit hip loop in place of the triangle: about 60 s saved, about USD 100 less; holds an unconscious person less securely.
- **Recommendation: B**; it also absorbs the 45 s that O3's tag line adds.

**O3, R7 (kit mass).** State: 8.9 kg carried; steel frame 2.6 kg, chain set 1.9 kg and rope 2.3 kg are the bulk.
- A. Helpers haul the rope bag (rope, triangle, sling) up on a 4 mm tag line: 5.5 kg carried, about USD 10, about 45 s more rigging.
- B. Aluminium frame (6082-T6, 40 % thicker, TIG welded): 7.7 kg carried, about USD 40 more.
- C. Both: 4.4 kg carried, about USD 50 more, about 45 s more rigging.
- **Recommendation: C**, the only option that meets the target.

**O4, R9 (cost per kit).** State: USD 758 a kit, over the value-engineering target of R9 by USD 658; descender USD 280, triangle USD 140 and rope USD 105 dominate.
- A. Keep the auto-locking descender and triangle: USD 758; the conservative safety choice.
- B. Two-sling hasty seat in place of the triangle: about USD 642 and 0.5 kg lighter; less secure for an unconscious person.
- C. Workshop bar rack with a friction-hitch backup in place of the descender: about USD 520; loses the hands-free lock.
- **Recommendation: A**, with savings sought through group purchase and one kit per climber group.

### Decisions made under the pre-approvals

- TKB-DDR-002: design for construction, changes C1 to C11 and assumptions A1 to A6.
- No use on a person before a proof test of the collar at 2.5 kN on cut trunk sections and a dummy drill at low height.
- Appearance model departures (renders only): a safe working load label on the spine, a 400 mm trunk with leaf-scar rings (inside the 200 to 450 mm range), the rope cut 450 mm below the frame, and a clay forearm and hand holding the brake strand from the far side for scale.

### Build plan findings

- Design changes for construction (2026-10-03), all in TKB-DDR-002: V of box-section bearing bars with bonded and screwed rubber pads; one 5 mm spine plate; the cleat as two slots in the spine top with notched 6 mm cheeks (the web must be 6 mm or thinner for a 6 mm link to span it, and the cheeks carry the twist); a bent sheet keeper and ball-lock pin; the fixed chain end in a slot and tethered to the spare eye with a quick link; eyes thickened with doubler rings; the lever geometry; a 110-link chain with a master link and painted slot links; the chain sleeve; the brake carabiner; galvanising and marking.
- The pad screws' nuts sit inside the box bars; the plan offers rivet nuts if they cannot be reached.
- The concept media draw the chain as its envelope to keep the hidden-line views quick; the build plan pictures and the product model show the links.
- Items to confirm with real parts (friction on wet bark, chain dimensions, descender data, rope, rubber bond, trunk survey, triangle fitting time, spare eye layout) are in TKB-DEC-001.

### Safety concerns

- Rope rescue at height: a slipping collar, a lost brake hand or a badly fitted triangle can drop a person up to 25 m. The kit is not certified equipment. Safety stops S1 to S6 in TKB-BLD-001 gate galvanising, first load, the proof test, work at height and every use.
- The lock rests on an assumed friction on wet bark; measuring it on cut trunk sections is the first TRL 4 task.
- The victim must never drop onto the collar: all slack is taken in before the feet are freed.
- A person who has hung head down needs medical assessment after the rescue; emergency services are always called.

### Recommended next step

Amish decides O1 to O4. The design then looks ready for TRL 4 once Amish chooses to start it: build one collar, measure friction and run the 2.5 kN hold on wet cut trunk sections with CalRig, then a timed dummy drill at 3 m with the first co-design candidate.

## 2026-10-03: photoreal renders

Rendered with Blender Cycles on Amish's Mac from `cad/src/product_model.py`; captioned with `.kit/photo_caption.py`; `media/card.png` and `media/social-preview.png` made with `.kit/cards.py`. Views: hero, exploded, detail. image_qc passes and `render.py --check` has no FAIL.

## 2026-10-03: Amish's requirement decisions carried out

Amish Chadha, 2026-10-03: "i agree with all the 46 recommendations you provided. please proceed." For TrunkBelay these are decisions 16A (R2), 17B (R4), 18C (R7) and 19A (R9), each the recommended option, recorded in TKB-DDR-003. Not committed or pushed (batch run).

### Changes

- 16A, R2: no hardware change. The drill rule (collar at least 300 mm above the victim's attachment) stays in safety stop S6 and Step 10 of the build plan; the double-acting collar is recorded as the fallback. The TRL 4 first check now treats the upward pull as a misuse test and checks that a rescuer can reach above the attachment.
- 17B, R4: the victim set is packed pre-rigged: the rope's figure-eight loop, the triangle's two waist loops and one end of the chest sling on the victim carabiner, so two clips are left at height. `victim_kit()` in `cad/src/model.py` draws it, with three new checks.
- 18C, R7: the collar frame is 6082-T6 aluminium, TIG welded with ER5356, not galvanised, sized on the welded (heat-affected) strength: bars RHS 50 x 40 x 3; cheeks 8 mm; spine 5 mm with its top raised to 185 mm so the cleat web is 35 mm deep; doubler rings kept 4 mm so the quick link still passes; spare eye moved to 85 mm back, clear of the deeper bars; the adjustable chain tail runs out 75 mm before it hangs, clear of the bar; ball-lock pin grip 27 mm; pad screws into countersunk stainless rivet nuts. The helpers haul the rope bag up on 55 m of 4 mm tag line doubled through a micro pulley on the rescuer's harness. Five new frame checks; 218 of 218 constructability checks pass. STEP and STL regenerated.
- 19A, R9: the auto-locking descender and evacuation triangle stay; R9 restated in `docs/03-requirements.md` (TKB-REQ-001 v0.3, Amish quoted) as parts under USD 850 per kit at single-kit prices, with group purchase sought.
- `bom/bom.csv`: lines 1 to 5, 7 and 10 changed for aluminium, rivet nuts and the 27 mm pin; lines 22 (tag line) and 23 (micro pulley) added; each with a price basis.
- `docs/04-calcs/sizing.py`, `01-sizing.md` (TKB-CAL-001 v0.2) and `results.csv` re-run; `docs/01-problem.md` v0.3 (cost and carry constraints), `docs/02-concept.md` v0.4, README, `project.yaml` (evidence; `budget_usd` unchanged).
- `docs/05-build-plan.md` v0.2: aluminium making and welding text, new section 3.14 (tag line and micro pulley), Step 10 (pre-rigged set and the order at height), first checks, safety stops S1 and S6, tools and skills.
- Pictures: general arrangement TKB-DWG-001 Rev P2; making sketches TKB-DWG-101 to 109; overview (now 18 groups, with the tag line); joints 1 to 8; steps 1 to 10; concept media (hero, exploded, blueprint key figures, `model.glb`, viewer).
- Register `docs/06-design-decisions.md` v0.2: O1 to O4 moved to Decisions made; Open decisions now "None"; four items added to confirm. Decision record `docs/decisions/0003-amish-requirement-decisions.md` (TKB-DDR-003).
- Appearance model `cad/src/product_model.py`: bare aluminium frame colour and names, label moved clear of the moved spare eye; scenes re-exported to `/home/claude/renders/trunkbelay`.

### New results

- R2: at risk for an upward pull, as before; avoided by the drill rule (16A).
- R4: about 4.5 minutes once in position (target under 5): the pre-rigged set saves 45 s and the tag-line haul adds 45 s. Still at risk on a rough estimate; timed at TRL 4.
- R7: 4.55 kg carried up the trunk (target under 5 kg): met on paper. The helpers haul 3.7 kg; the whole kit is 8.3 kg. The decision estimate was about 4.4 kg; the difference is the doubled tag line (0.60 kg) that lets the helpers haul from the ground.
- R9: USD 826 a kit against the restated USD 850 (USD 24 under). Value-engineering target: USD 900. Estimated cost of the constructable design: USD 826 (USD 74 under the target). The changes cost USD 68 against the decision estimate of about USD 50 (aluminium frame about USD 29 net of galvanising, tag line and pulley USD 39).
- Frame strength at the R1 load of 2.5 kN, on the welded proof strength of 6082-T6 (125 MPa): bars 1.60, cleat web 1.55, cleat twist 2.0; welds 5.3 on the weld metal; the steel frame had 2.1 to 3.8 on yield. R1 (locking factor 1.54), R3, R5, R6 and R8 are unchanged.

### For Amish

- Nothing new to decide. Open decisions are "None"; R2 and R4 are settled by the TRL 4 drill and timed trial.
- The photoreal renders (`media/render-*.png`), card and social preview still show the galvanised steel frame; re-render on the Mac from the re-exported scenes.

### Safety

- The aluminium frame has smaller strength margins than the steel one, and aluminium beside a weld is about half as strong as the plate: no added or repair welds, every weld inspected (S1), and the TRL 4 proof test must look for permanent set in the frame.
- The collar holds only a downward pull: the 300 mm drill rule is a safety rule, not a preference (S6). Nobody stands under the bag while it is hauled up.
- The kit is not certified equipment, and nobody is lowered with it before the proof test and a dummy drill at low height.

## 2026-10-04: photoreal renders redone after the round-2 and round-3 decisions

Views: hero, exploded, detail; cards regenerated; image_qc passes and `render.py --check` has no FAIL.

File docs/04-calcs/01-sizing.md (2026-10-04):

---
doc_id: TKB-CAL-001
title: TrunkBelay sizing calculations
project: TrunkBelay
doc_type: Calculation note
version: "0.2"
status: Draft
date: '2026-10-03'
author: Amish Chadha
license: CERN-OHL-S-2.0
revisions:
- version: "0.1"
  date: '2026-10-03'
  author: Amish Chadha
  change: First issue at TRL 3, on the constructable design of TKB-DDR-002
- version: "0.2"
  date: '2026-10-03'
  author: Amish Chadha
  change: Re-run for Amish's decisions 16A, 17B, 18C and 19A (TKB-DDR-003); aluminium frame, tag-line haul, pre-rigged victim set, restated R9
---

# TrunkBelay sizing calculations

On paper, the constructable TrunkBelay collar locks on every trunk from 200 to 450 mm with a locking factor of 1.54 or more, holds the 2.5 kN load of R1 with every aluminium frame part at 1.55 times its welded (heat-affected) proof strength or better, and lets one rescuer lower a 100 kg person 25 m with about 80 N at the brake hand. Version 0.2 carries out Amish's decisions of 2026-10-03 (TKB-DDR-003): the frame is TIG-welded 6082-T6 aluminium, the helpers haul the rope bag up on a tag line, and the victim set is packed pre-rigged, so the rescuer carries 4.55 kg against the 5 kg target; the kit costs USD 826 against the restated R9 target of USD 850. Its weak points are friction and the drill: the lock rests on an assumed friction on wet bark that must be measured first, and the upward pull of R2 is avoided by the drill rule, not by the hardware. Every figure below comes from `docs/04-calcs/sizing.py`, which imports the parametric model (`cad/src/model.py`), so the sizes here are the sizes in the STEP file, the drawings and the build plan. Tags in square brackets ([A1], [B4] ...) match the script output and `results.csv`.

These are first-principles screening estimates for a paper proof of concept. They do not replace a proof test of the collar on cut palm trunk sections or a timed drill, which are TRL 4 work.

> **Safety:** TrunkBelay holds and lowers a person at height. These numbers are for a design review only. The kit is not certified rescue or fall-protection equipment, and nobody is lowered with it before the collar has been proof-tested at 2.5 kN on cut trunk sections and the drill has been run with a dummy at low height.

## 1. Assumptions

*Table 1. Assumptions.*

| # | Assumption | Value | Basis |
| --- | --- | --- | --- |
| 1 | Design person | 100 kg, plus 0.96 kg of triangle, sling and carabiner | TKB-REQ-001, R2 and R5 |
| 2 | Static load the collar is sized for | 2.5 kN (R1) | TKB-REQ-001, R1 |
| 3 | Friction on wet coconut bark | Rubber pad 0.5; webbing-sleeved chain 0.4 | Judgement for rubber and nylon on wet fibrous wood; first item to measure (TKB-DDR-002, A1) |
| 4 | Lever height | The chain line above the bottom edge of the bars, 160 mm (conservative: the bars bear at their bottom edge as the frame cocks) | Model |
| 5 | Pad rubber | 60 to 70 Shore A, compression modulus 6 MPa, contact patch 40 mm wide on a round trunk | Rubber class |
| 6 | Frame metal | 6082-T6 aluminium, TIG welded with ER5356 filler. Every frame check uses the heat-affected-zone strength (0.2 % proof 125 MPa, ultimate 185 MPa); weld metal 210 MPa. Keeper and fixings stay steel | EN 1999-1-1 values; BOM lines 1 to 5 (TKB-DDR-003) |
| 7 | Chain | 6 mm grade 80: working load limit 11.2 kN, minimum breaking force 45 kN, 0.80 kg/m | Catalogue class |
| 8 | Rope | 11 mm EN 1891 type A: at least 22 kN, 65 % at a figure-eight loop, 4 % stretch from 50 to 150 kg, 78 g/m | Standard minimum and catalogue class |
| 9 | Descender | Rope friction 0.2 over 540 deg of contact (ratio 6.6) | Conservative; confirm with the maker's data |
| 10 | Carabiners | Aluminium, class B, 25 kN on the long axis, 85 g | EN 362 class |
| 11 | Bark | No cut below 2 MPa under rubber; the outer coconut stem is far stronger in crushing | Judgement; inspected at TRL 4 (R8) |

## 2. Loads [A]

- [A1] Holding a 100 kg person, the collar carries 0.99 kN. The R1 load of 2.5 kN is 2.5 times that.
- [A2] If slack is left when the feet are freed, the person drops onto the rope. On 1 m of rope a 30 mm drop gives about 2.6 kN, 50 mm 2.9 kN and 100 mm 3.4 kN. The drill takes all slack through the descender first, so the drop stays under 30 mm; the strength factors in section 4 cover the small excess over 2.5 kN.

## 3. Grip on the trunk [B]

The collar is self-locking. The load hangs from the load eye at a distance e from the trunk axis; the chain holds the frame at a height h above the bottom of the bars. Taking moments, the bars press the bark with a force N = W e / h and the chain presses the far side with the same force. Friction at both places holds the frame if (friction at the pads + friction at the chain) x N is at least W, that is if the combined friction is at least h / e. The ratio of the friction available to the friction needed is the locking factor. It does not depend on the load: the grip rises in step with it.

*Table 2. Grip at the R1 load of 2.5 kN.*

| Trunk | Load line from the axis | Friction needed | Locking factor | Bars press (each pad) | Chain tension |
| --- | --- | --- | --- | --- | --- |
| 200 mm [B1] | 273 mm | 0.58 | 1.54 | 4.3 kN (2.5 kN) | 3.3 kN |
| 300 mm [B2] | 331 mm | 0.48 | 1.86 | 5.2 kN (3.0 kN) | 4.2 kN |
| 450 mm [B3] | 418 mm | 0.38 | 2.35 | 6.5 kN (3.8 kN) | 5.5 kN |

- [B4] The smallest locking factor is 1.54, on the smallest trunk. The friction of the chain's full wrap round the trunk is extra and is not counted.
- [B5] Under 2.5 kN the pads squash about 3.1 mm (1.9 MPa) and the chain seats up to 2.9 mm; the frame drops about 10 mm as it cocks, inside the 20 mm of R1.

The lock depends on assumption 3. If the combined friction on a wet 200 mm trunk were below 0.58, the collar would slide. Measuring it is the first TRL 4 task.

## 4. Strength at the R1 load [C]

- [C1] Bearing bars, aluminium RHS 50 x 40 x 3: 0.48 kN m at the spine on the 450 mm trunk, 78 MPa, factor 1.60 on the welded proof strength (4.0 at the working load) and 2.4 on the welded ultimate strength. The bars are 15 mm deeper than the steel ones; that is why the spare eye moved 15 mm back (to 85 mm) and the adjustable chain tail now runs out 75 mm before it hangs.
- [C2] Bar-to-spine fillet welds, 5 mm all round: 40 MPa, factor 5.3 on the weld metal.
- [C3] Spine arm: 7 MPa beside the lightening hole. The load eye is 13 mm thick with its doubler rings (kept at 4 mm so the 8 mm quick link still passes round the spare eye); bearing under the carabiner bar is 19 MPa and the tear-out strength 39 kN, 16 times the R1 load.
- [C4] Chain cleat at 5.5 kN of chain tension: the 5 mm web beside a slot, loaded by the next link, now 35 mm deep (the spine top was raised 10 mm to 185 mm), 81 MPa, factor 1.55 on the welded proof strength; the twist between the two slots, 0.16 kN m, gives 35 MPa in the top with 8 mm cheeks (factor 2.0 in shear). The web stays 5 mm because a chain link must span it. The steel links bear on the aluminium web at about 92 MPa; wear of the slot faces is to be confirmed.
- [C5] Chain: 5.5 kN at most, factor 8.1 on its breaking force and under half its working load limit; 2.2 kN at the working load.
- [C6] Rope: about 14 kN at the figure-eight loop, factor 5.7 at the R1 load and 14 at the working load. Carabiners: factor 10 and 25.

## 5. Lowering [D]

- [D1] The descender's friction ratio of 6.6 and the 180 deg turn over the brake carabiner (1.87) leave about 80 N at the brake hand for a 100 kg person, inside the 150 N of R5. Without the brake carabiner the hand would hold about 150 N, at the limit, which is why the brake carabiner is part of the design.
- [D2] A 25 m lowering at 0.3 m/s takes 83 s and turns 24.8 kJ into heat: 85 % in the descender, 7 % in the brake carabiner and 8 % at the hand. If the descender kept it all it would warm by at most 44 K.

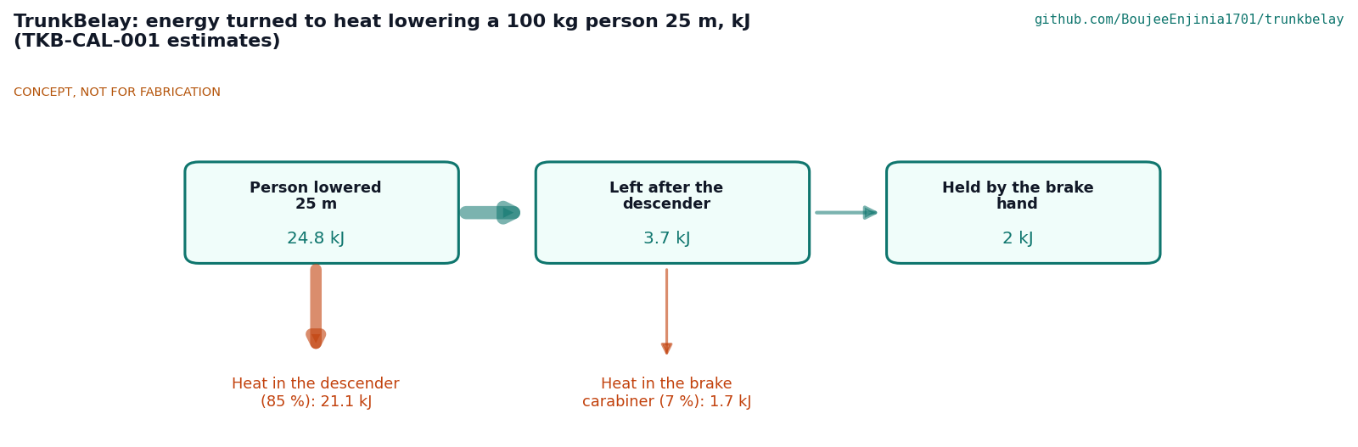
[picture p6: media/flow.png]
Figure 1. Where the energy of a 25 m lowering goes


*Figure 1. Energy turned to heat lowering a 100 kg person 25 m (estimates).*

## 6. Fit, reach and rigging [E]

- [E1] Rope: 25 m of lowering, 1 m from the descender to the person at the start, 1.5 m for the knots and 0.5 m round the brake carabiner: 28 m of the 30 m.
- [E2] Fit: on a 200 mm trunk the chain loop is 769 mm, the pads touch 58 mm along their faces and the spine is 23 mm clear of the bark; on 300 mm, 1,086 mm, 87 mm and 31 mm; on 450 mm, 1,563 mm, 130 mm and 43 mm. The 110-link chain leaves at least 10 links of tail on a 450 mm trunk.
- [E3] Rigging time once the rescuer is in position (estimate): collar 60 s; the helpers haul the bag up on the tag line 45 s; descender and rope 40 s; bag to the ground 20 s; the pre-rigged triangle and chest sling 90 s (was 120 s); clip the crotch loop and the sling's free end and take in slack 15 s (was 30 s): 4.5 minutes. The pre-rigged set saves the 45 s the haul adds, so the estimate is unchanged.

## 7. Mass [F]

- [F1] Collar frame 1.31 kg (the aluminium weldment 0.97 kg), chain set 1.88 kg, descender 0.53 kg, carabiners 0.26 kg, rope 2.34 kg, triangle and sling 0.87 kg, bag 0.45 kg, tag line 0.60 kg (55 m of 4 mm cord) and micro pulley 0.05 kg: 8.3 kg in all.
- [F2] The helpers haul 3.7 kg up in the bag (the rope, the pre-rigged victim set with its carabiner, and the bag). The rescuer carries 4.55 kg: the collar, chain set, descender, load and brake carabiners, the micro pulley and the tag line hanging from it. R7 asks for under 5 kg: met on paper with 0.45 kg to spare. The decision estimate was about 4.4 kg; the difference is the tag line, which runs doubled from the ground (both legs hang from the rescuer at the top) so the helpers can haul.
- [F3] The aluminium weldment saves about 1.9 kg against the same parts in steel.

## 8. Bark [G]

- [G1] At 2.5 kN the pads press 1.9 MPa (0.7 MPa at the working load) and the sleeved chain 0.6 MPa: no cut is expected. Bare links outside the sleeve press about 8 MPa on a 3 mm line and may mark the bark; R8 is confirmed by inspection after the TRL 4 tests.

## 9. Cost [H]

- [H1] Value-engineering target: USD 900. Estimated cost of the constructable design: USD 826 (USD 74 under the target). The aluminium frame adds about USD 29 (material, TIG welding and rivet nuts, less the galvanising) and the tag line and micro pulley USD 39, USD 68 in all against the decision estimate of about USD 50.
- [H2] Against R9 as restated by Amish's decision 19A (USD 850 per kit at single-kit prices), the kit is USD 24 under. The largest lines are the auto-locking descender (USD 280), the evacuation triangle (USD 140), the rope (USD 105) and the TIG welding (USD 45). Group purchase by the training partner and one kit per climber group are savings to seek and are not counted.

## 10. Results against the requirements

*Table 3. Requirements on paper.*

| ID | Status on paper | Basis |
| --- | --- | --- |
| R1 | Met on paper; friction to confirm | Locking factor 1.54 at the smallest trunk; settles about 10 mm [B4, B5] |
| R2 | **At risk** for an upward pull; drill rule kept (decision 16A) | The single top chain cannot hold an upward pull on paper; the drill keeps the collar at least 300 mm above the person's attachment so the case does not arise; the double-acting collar is the recorded fallback |
| R3 | Met | 200 to 450 mm, no tools [E2] |
| R4 | **At risk** (estimate) | About 4.5 minutes: the pre-rigged set saves 45 s and the tag-line haul adds 45 s [E3]; timed at TRL 4 |
| R5 | Met on paper (estimate) | About 80 N at the hand [D1] |
| R6 | Met | 28 m needed of 30 m [E1] |
| R7 | Met on paper | 4.55 kg carried, 0.45 kg under the target; the 3.7 kg bag is hauled up [F2] |
| R8 | Met on paper; to confirm | Pads 1.9 MPa, sleeve 0.6 MPa [G1] |
| R9 | Met on paper (restated target) | USD 826 a kit against USD 850 [H2] |
| R10 | Cannot be shown on paper | Needs the training trial at TRL 4 |

Amish decided R2, R4, R7 and R9 on 2026-10-03: "i agree with all the 46 recommendations you provided. please proceed." (decisions 16A, 17B, 18C and 19A, TKB-DDR-003). R2 and R4 stay at risk on paper and are settled by the TRL 4 drill and timed trial.

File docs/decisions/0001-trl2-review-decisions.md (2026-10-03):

---
doc_id: TKB-DDR-001
title: TrunkBelay TRL 2 review decisions
project: TrunkBelay
doc_type: Design decision record
version: "0.1"
status: Draft
date: '2026-10-03'
author: Amish Chadha
license: CERN-OHL-S-2.0
revisions:
- version: "0.1"
  date: '2026-10-03'
  author: Amish Chadha
  change: TRL 2 review items decided under Amish's 2026-10-03 pre-approvals
---

# 0001: TRL 2 review decisions

- **Date:** 2026-10-03
- **Status:** decided, except where noted. Decided by Amish under his pre-approval of 2026-10-03: "start with the first 14 repos from the list of 29 projects. I pre-approve the batch runs along with any recommendations you come up with. I also accept any cost overruns or variations from the assumed scope cost." and his instruction of the same day for this batch: "Proceed with the remaining 15 scaffolds". Requirements that are not met or at risk are not decided here; they are open in the design decisions register (TKB-DEC-001), as Amish asked on 2026-10-03: "A simple statement doesn't add value - ensure you are identifying a state and posing it as a clear recommendation for me to decide on."

## Context

The scaffold (TKB-PRB-001, TKB-PRC-001 and TKB-REQ-001, all v0.1) described a chain collar with a slotted cleat, a padded bearing plate, a commodity friction device, a rope, a victim sling and a bag. It left five open questions: the load turning from upward to downward as the victim passes the collar, grip on wet and curved trunks, which friction device to use, how to fit a sling to an unconscious person hanging head down, and whether fire services would adopt the kit. Populating the concept to TRL 2 meant settling these on paper. Items that touch safety take the conservative option and say what evidence would relax it. Partners are the first candidates to approach, not agreements.

## Options considered

*Table 1. Options.*

| # | Item | Options |
| --- | --- | --- |
| D1 | How the collar grips | (a) a band tightened hard round the trunk (grip set by the rescuer's pull); (b) a self-locking frame, the load hung on a lever so the grip rises with the load |
| D2 | Bearing on the bark | (a) a curved padded plate; (b) two rubber-faced bars in a V |
| D3 | Where the collar goes | (a) level with the rescuer, below the victim, and loaded upward at first; (b) at least 300 mm above the point where the rope meets the victim, always loaded downward |
| D4 | Friction device | (a) a figure-eight descender; (b) a bar rack; (c) a Munter hitch on a carabiner; (d) an auto-locking descender with anti-panic, plus a brake carabiner |
| D5 | Victim attachment | (a) one sewn sling as a hasty seat; (b) an evacuation triangle with a chest sling |
| D6 | Rope and spare rope | (a) all rope in a bag hung on the collar; (b) the bag lowered to the helpers and the brake strand run to the ground |
| D7 | Rating | (a) a two-person load for fire crews; (b) one person, 100 kg design mass, sized for a 2.5 kN static load (R1) |
| D8 | First co-design candidates | Climber training programme, fire station, climbers' collective |
| D9 | Material | (a) steel, welded and hot-dip galvanised; (b) aluminium |

## Decision

*Table 2. Decisions.*

| # | Decision | Why |
| --- | --- | --- |
| D1 | (b) Self-locking frame. The load eye sits 150 mm out from the frame and the chain line 160 mm above its foot, so the frame cocks on the trunk | Grip does not depend on how hard a tired rescuer pulls; it rises with the load (TKB-CAL-001, B1 to B4) |
| D2 | (b) Two rubber-faced bearing bars in a 120 deg V | Touches every trunk from 200 to 450 mm on two lines and centres the frame; a curved plate fits one size |
| D3 | (b) for the drill as modelled. Whether this answers R2 or the collar is made to hold both ways is open: TKB-DEC-001, O1 | The single top chain cannot hold an upward pull on paper |
| D4 | (d) Auto-locking descender with anti-panic, brake strand over a carabiner on the spare eye | Conservative: it holds the victim if the rescuer lets go or pulls too hard. Relaxed only by a training trial showing that rescuers control a manual device reliably |
| D5 | (b) Evacuation triangle round the hips and a chest sling on the same victim carabiner | Turns the victim head up once the feet are freed and holds an unconscious person |
| D6 | (b) Bag lowered, brake strand to the ground | The rescuer handles one strand at height; the helpers manage the spare rope |
| D7 | (b) One person, 100 kg, 2.5 kN static. No use on a person before a proof test at 2.5 kN on cut trunk sections and a dummy drill at low height | Conservative gate; the rating is raised only by a test programme with a fire service partner |
| D8 | First candidates to approach (none approached yet): a coconut climber training programme under the Coconut Development Board's Friends of Coconut Tree scheme in Kerala; a Kerala Fire and Rescue Services station in Kasaragod or Kannur; a climbers' collective or labour bank in the same district | They teach, rescue and climb |
| D9 | (a) Steel, welded and galvanised, for the prototype. An aluminium frame is one of the options for R7 in TKB-DEC-001, O3 | Any village fabrication shop can make it |
| D10 | Pitch, problem, patent design-arounds and `budget_usd` unchanged | Scope rule |

## Consequences

- The cleat is a pair of plain slots with a keeper and pin, not a ratchet, which keeps the design-around of the 3M Cynch-Lok.
- The kit carries more than its 5 kg target and costs more than its USD 100 target; both are open decisions for Amish (TKB-DEC-001, O3 and O4).
- The drill's placement rule (D3) and rigging time are open decisions for Amish (TKB-DEC-001, O1 and O2).

> **Safety:** D3, D4 and D7 set safety limits. Each takes the conservative option and names the evidence that would relax it. Nobody is lowered with this kit until the collar has been proof-tested at 2.5 kN on cut trunk sections and the drill has been run with a dummy at low height.

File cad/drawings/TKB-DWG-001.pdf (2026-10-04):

CONCEPT, NOT FOR FABRICATION | TrunkBelay · github.com/BoujeeEnjinia1701/trunkbelay

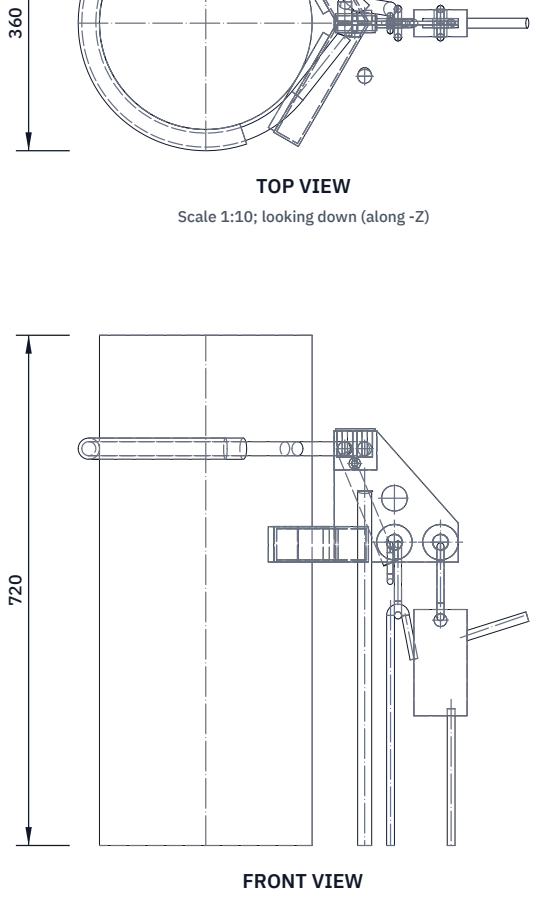
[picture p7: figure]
FRONT VIEW; TOP VIEW; Scale 1:10; looking down (along -Z)

Scale 1:10; looking at the front (along +Y)

RIGHT VIEW
Scale 1:10; looking at the right side (along -X)

636

ISOMETRIC VIEW
Seen from the front right, above; 300 mm trunk section for reference

KEY DIMENSIONS (MM) AND DATA
Fits trunks 200 to 450 across; drawn on a 300 trunk Spine 5 aluminium plate, 175 long x 185 high Bearing bars RHS 50 x 40 x 3 in a 120 deg V
Rubber pads 155 x 50 x 10
Load eye 150 out from the spine front edge, 28 up
Chain line 160 above the frame foot; slots 7.5 wide
Chain 6 mm grade 80, 110 links; sleeve 600 tubular webbing Cheeks 8; keeper 3 steel; ball-lock pin 8, grip 27
Locking factor 1.54 or more (TKB-CAL-001, B4)
Sized for 2.5 kN static (R1); one person, 100 kg
Carried 4.55 kg; bag hauled on the tag line PRELIMINARY, NOT FOR FABRICATION
REV | DESCRIPTION | DATE | BY
P1 | Preliminary GA from the constructable TRL 3 model (TKB-DDR-002) | 2026-10-03 | AC
P2 | Aluminium frame and tag line (TKB-DDR-003) | 2026-10-03 | AC
TRUNKBELAY | github.com/BoujeeEnjinia1701/trunkbelay

## Palm trunk rescue collar and lowering kit: general arrangement

DRAWING NO.
TKB-DWG-001

REV
P2

SHEET
1 of 1

SIZE

## ANSI B

SCALE
1:10

UNITS
mm
PROJECTION | DATE
2026-10-03

DRAWN
Amish Chadha

MATERIAL / NOTES
6082-T6 aluminium plate and RHS, TIG welded; rubber pads; grade 80 chain. See bom/bom.csv
Licensed CERN-OHL-S-2.0 · Design Molecule Lab · designmolecule.com | Generated from cad/src; do not edit by hand

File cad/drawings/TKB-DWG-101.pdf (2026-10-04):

BUILD PLAN SKETCH, PLAN NOT YET BUILT TrunkBelay · github.com/BoujeeEnjinia1701/trunkbelay

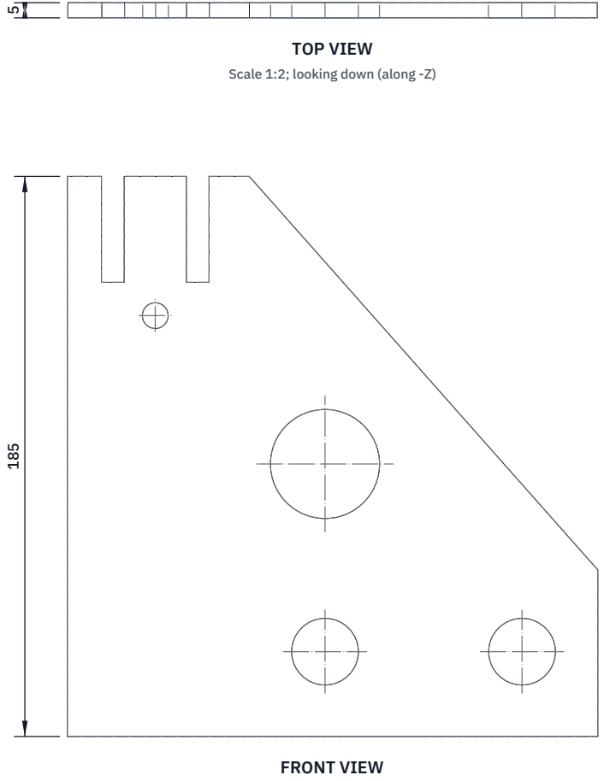
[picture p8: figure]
FRONT VIEW; TOP VIEW; Scale 1:2; looking down (along -Z)

Scale 1:2; looking at the front (along +Y)

RIGHT VIEW
Scale 1:2; looking at the right side (along -X)

175

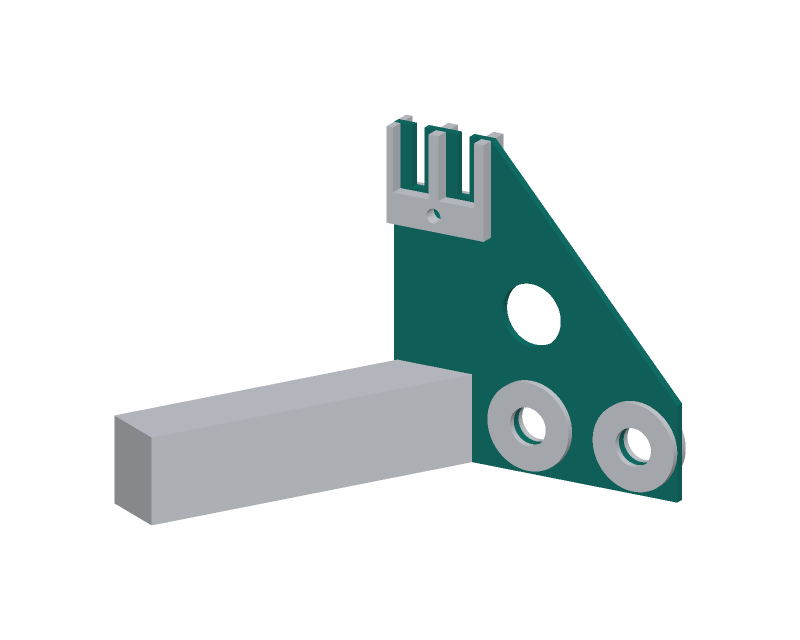
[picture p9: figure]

WHERE IT GOES
This part in colour, its neighbours in grey

HOW TO MAKE IT AND HOW IT FITS
One piece of 5 mm 6082-T6 aluminium plate, profile cut. Outline from the front edge (the edge toward the trunk): 175 long at the bottom, 185 high at the front; 55 high at the back end; the top runs 60 back, then slopes down.
Holes: load eye 22 at 150 back, 28 up; spare eye 22 at 85
back, 28 up; lightening hole 36 at 85 back, 90 up.
Chain slots: two, 7.5 wide, 35 deep from the top edge, centred 15 and 43 back from the front edge. Cut them square and file every edge smooth; no burr may touch chain.
Lock pin hole 8.5 at 29 back, 139 up (drill after the cheeks
are welded on, through all three plates).
Do not thicken the plate: a link must span it (6 mm at most). Round the eye edges to 2 mm radius after the rings go on.
REV | DESCRIPTION | DATE | BY
P1 | Making sketch for the prototype build plan | 2026-10-03 | AC
TRUNKBELAY | github.com/BoujeeEnjinia1701/trunkbelay

## TrunkBelay: spine plate (make 1)

DRAWING NO.
TKB-DWG-101

REV
P1

SHEET
1 of 1

SIZE

## ANSI B

SCALE
1:2

UNITS
mm
PROJECTION | DATE
2026-10-03

DRAWN
Amish Chadha

MATERIAL / NOTES
6082-T6 aluminium plate 5 mm
Licensed CERN-OHL-S-2.0 · Design Molecule Lab · designmolecule.com | Generated from cad/src; do not edit by hand

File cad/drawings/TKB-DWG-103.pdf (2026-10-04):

BUILD PLAN SKETCH, PLAN NOT YET BUILT TrunkBelay · github.com/BoujeeEnjinia1701/trunkbelay

FRONT VIEW
Scale 1:2; looking at the front (along +Y)

TOP VIEW
Scale 1:2; looking down (along -Z)

RIGHT VIEW
Scale 1:2; looking at the right side (along -X)

198

40 50

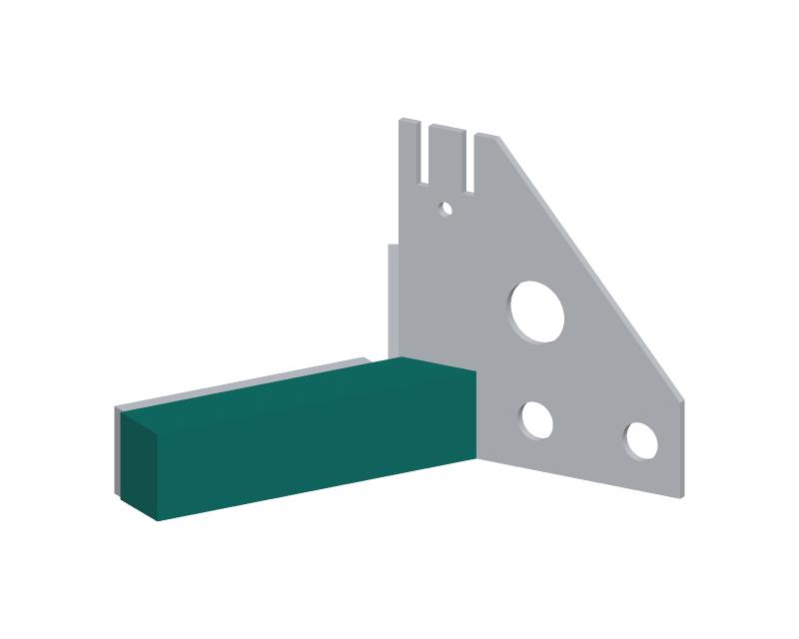
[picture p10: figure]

WHERE IT GOES
This part in colour, its neighbours in grey

HOW TO MAKE IT AND HOW IT FITS
Make two, one a mirror image of the other. Aluminium RHS 50 x 40 x 3, the 50 face vertical; the 40 depth runs away from the trunk. Length 175 along the trunk-side face; the inner end is cut at 30 deg so it lies flat on the spine.
TIG weld a 3 mm aluminium cap on the outer end (ER5356). No vent hole: the frame is not galvanised.
Drill two 9.0 holes through the trunk-side face only, 53 and 138 from the inner end on the centre line; after welding set M6 countersunk-head stainless rivet nuts in them, flush. The two bars meet the spine at its foot and form a V with 120 deg between their trunk-side faces.
REV | DESCRIPTION | DATE | BY
P1 | Making sketch for the prototype build plan | 2026-10-03 | AC
TRUNKBELAY | github.com/BoujeeEnjinia1701/trunkbelay

## TrunkBelay: bearing bar (make 2, opposite hands)

DRAWING NO.
TKB-DWG-103

REV
P1

SHEET
1 of 1

SIZE

## ANSI B

SCALE
1:2

UNITS
mm
PROJECTION | DATE
2026-10-03

DRAWN
Amish Chadha

MATERIAL / NOTES
6082-T6 aluminium rectangular hollow section 50 x 40 x 3 mm
Licensed CERN-OHL-S-2.0 · Design Molecule Lab · designmolecule.com | Generated from cad/src; do not edit by hand

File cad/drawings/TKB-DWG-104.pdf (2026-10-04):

BUILD PLAN SKETCH, PLAN NOT YET BUILT TrunkBelay · github.com/BoujeeEnjinia1701/trunkbelay

FRONT VIEW
Scale 2:1; looking at the front (along +Y)

TOP VIEW
Scale 2:1; looking down (along -Z)

RIGHT VIEW
Scale 2:1; looking at the right side (along -X)

60

8 55

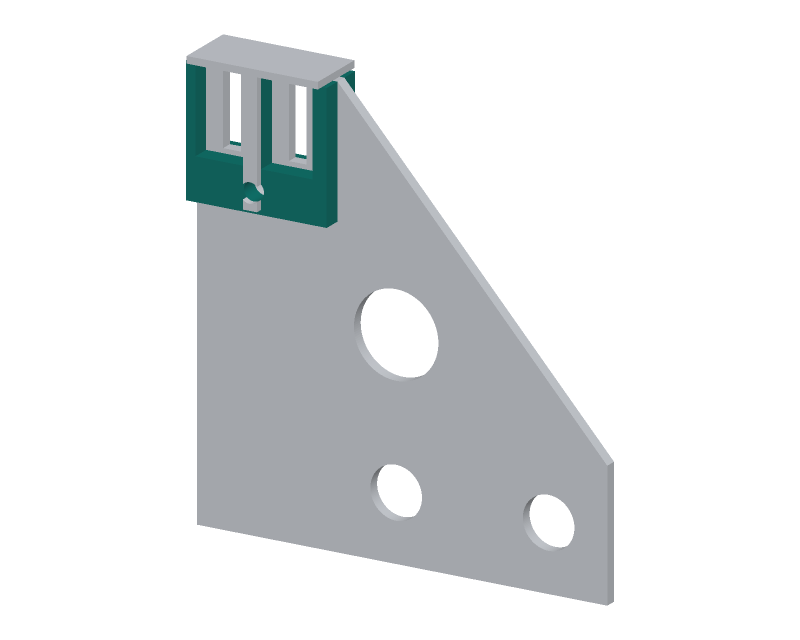
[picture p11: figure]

WHERE IT GOES
This part in colour, its neighbours in grey

HOW TO MAKE IT AND HOW IT FITS
Make two. 8 mm 6082-T6 aluminium plate, 60 long x 55 high. Two notches from the top edge, 22 wide and 37 deep, centred 15 and 43 from the front end, so they sit round the two
chain slots in the spine with 7.25 of web showing each side. Weld one on each face of the spine, top edges flush with the spine top, front ends flush with its front edge: 5 mm TIG fillets along the bottom and back end only (keep the notches and the top clean).
Then drill the 8.5 lock pin hole through cheek, spine and cheek together, 29 from the front, 139 up from the frame foot.
REV | DESCRIPTION | DATE | BY
P1 | Making sketch for the prototype build plan | 2026-10-03 | AC
TRUNKBELAY | github.com/BoujeeEnjinia1701/trunkbelay

## TrunkBelay: cleat cheek (make 2)

DRAWING NO.
TKB-DWG-104

REV
P1

SHEET
1 of 1

SIZE

## ANSI B

SCALE
2:1

UNITS
mm
PROJECTION | DATE
2026-10-03

DRAWN
Amish Chadha

MATERIAL / NOTES
6082-T6 aluminium plate 8 mm
Licensed CERN-OHL-S-2.0 · Design Molecule Lab · designmolecule.com | Generated from cad/src; do not edit by hand

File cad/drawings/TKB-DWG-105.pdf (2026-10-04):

BUILD PLAN SKETCH, PLAN NOT YET BUILT TrunkBelay · github.com/BoujeeEnjinia1701/trunkbelay

FRONT VIEW
Scale 1:5; looking at the front (along +Y)

TOP VIEW
Scale 1:5; looking down (along -Z)

RIGHT VIEW
Scale 1:5; looking at the right side (along -X)

260

348 185

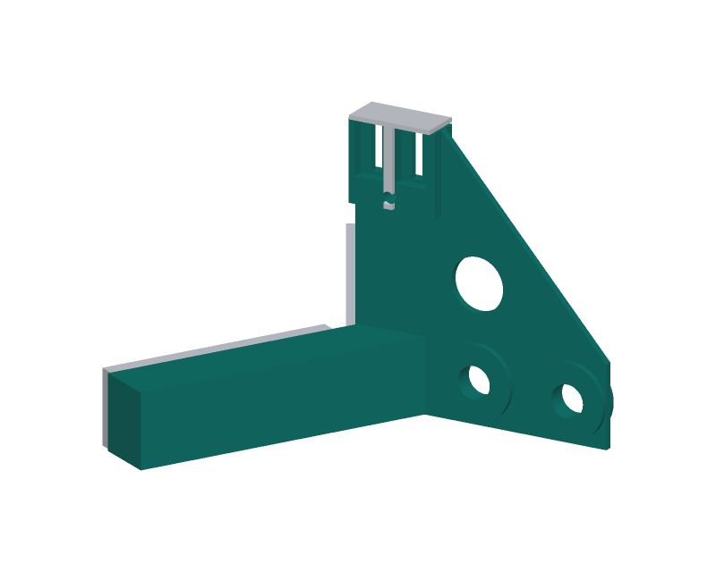
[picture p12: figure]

WHERE IT GOES
This part in colour, its neighbours in grey

HOW TO MAKE IT AND HOW IT FITS
TIG weld the bars to the spine foot first (AC, ER5356), in a
jig that holds their trunk-side faces at 120 deg, bottoms
level. 5 mm fillets all round each bar end; the bar ends must not stand proud of the spine's front edge.
Then the four eye rings, then the two cheeks.
Check: the V faces meet (if extended) 8 in front of the spine front edge; both bar faces flat within 1 mm.
Clean the bar faces, slots and eyes with a stainless brush;
run a 7 mm bar through both slots and the 8 pin through
its hole. Inspect every weld; no repair welding of a crack.
Stamp SWL 100 kg ONE PERSON and the frame number on the spine.
REV | DESCRIPTION | DATE | BY
P1 | Making sketch for the prototype build plan | 2026-10-03 | AC
TRUNKBELAY | github.com/BoujeeEnjinia1701/trunkbelay

## TrunkBelay: collar frame weldment (make 1)

DRAWING NO.
TKB-DWG-105

REV
P1

SHEET
1 of 1

SIZE

## ANSI B

SCALE
1:5

UNITS
mm
PROJECTION | DATE
2026-10-03

DRAWN
Amish Chadha

MATERIAL / NOTES
6082-T6 aluminium parts above, TIG welded (ER5356), not galvanised
Licensed CERN-OHL-S-2.0 · Design Molecule Lab · designmolecule.com | Generated from cad/src; do not edit by hand

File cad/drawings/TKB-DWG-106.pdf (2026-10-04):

BUILD PLAN SKETCH, PLAN NOT YET BUILT TrunkBelay · github.com/BoujeeEnjinia1701/trunkbelay

FRONT VIEW
Scale 1:1; looking at the front (along +Y)

TOP VIEW
Scale 1:1; looking down (along -Z)

RIGHT VIEW
Scale 1:1; looking at the right side (along -X)

155

10 50

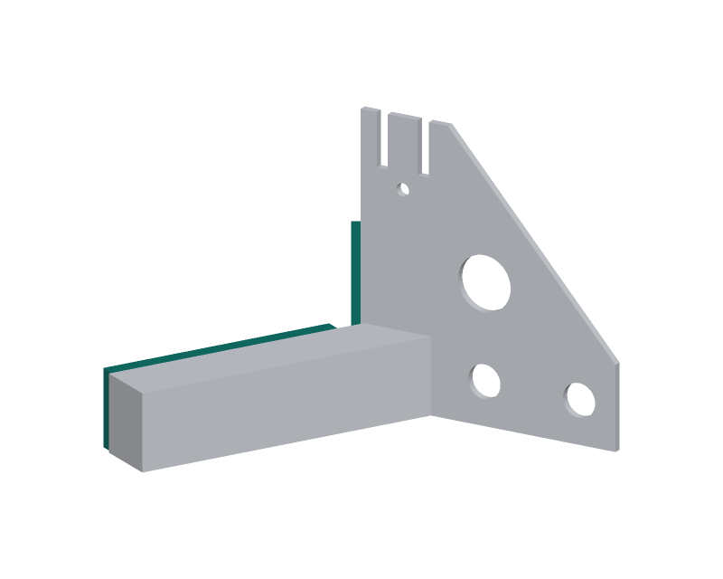
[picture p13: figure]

WHERE IT GOES
This part in colour, its neighbours in grey

HOW TO MAKE IT AND HOW IT FITS
Make two. Cut 155 x 50 from 10 mm fabric-ply rubber sheet. Drill two 6.5 holes on the centre line, 35 from each end, and counterbore them 13 diameter, 4 deep from the trunk side, so the screw heads sit 3 below the rubber face.
Bond to the bar's trunk-side face with contact adhesive, the inner end 15 from where the two pad faces would meet.
Fit M6 x 30 countersunk stainless screws through the pad into the rivet nuts in the bar face, with threadlocker. Replace a pad that is torn, glazed or soaked in oil.
REV | DESCRIPTION | DATE | BY
P1 | Making sketch for the prototype build plan | 2026-10-03 | AC
TRUNKBELAY | github.com/BoujeeEnjinia1701/trunkbelay

## TrunkBelay: rubber bark pad (make 2)

DRAWING NO.
TKB-DWG-106

REV
P1

SHEET
1 of 1

SIZE

## ANSI B

SCALE
1:1

UNITS
mm
PROJECTION | DATE
2026-10-03

DRAWN
Amish Chadha

MATERIAL / NOTES
Natural rubber sheet with one fabric ply, 10 mm, 60 to 70 Shore A
Licensed CERN-OHL-S-2.0 · Design Molecule Lab · designmolecule.com | Generated from cad/src; do not edit by hand

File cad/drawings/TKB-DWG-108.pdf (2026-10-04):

BUILD PLAN SKETCH, PLAN NOT YET BUILT TrunkBelay · github.com/BoujeeEnjinia1701/trunkbelay

FRONT VIEW
Scale 1:2; looking at the front (along +Y)

TOP VIEW
Scale 1:2; looking down (along -Z)

RIGHT VIEW
Scale 1:2; looking at the right side (along -X)

249

23 65

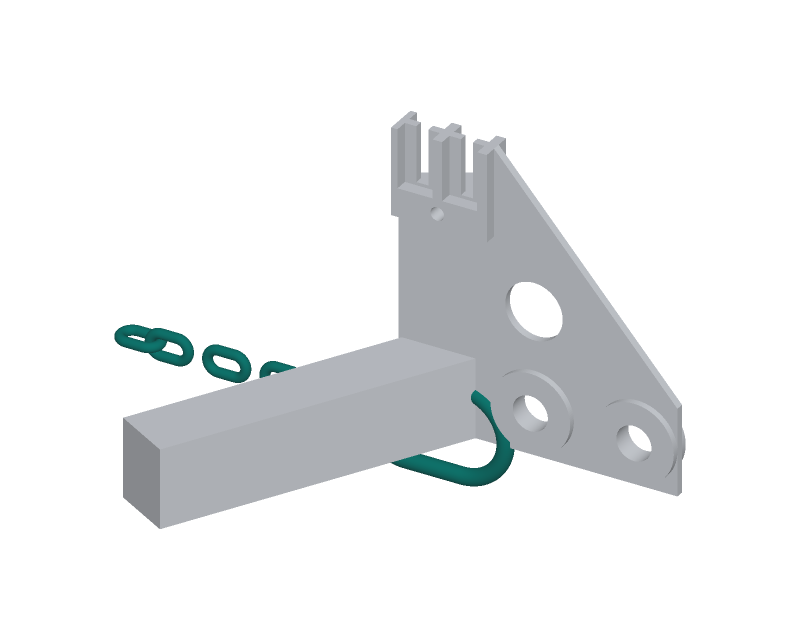
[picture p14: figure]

WHERE IT GOES
This part in colour, its neighbours in grey

HOW TO MAKE IT AND HOW IT FITS
Buy 110 links of 6 mm grade 80 chain (about 1.98 m) with its certificate, cut to length by the supplier. Count the links. Never weld, heat, grind or bend the chain.
One end (the adjustable end): fit the master link with a
6 mm grade 80 connecting link and peen its pin.
Other end (the fixed end): leave plain; it goes into the front slot and a quick link ties its tail to the spare eye.
Paint the 56th, 72nd and 100th links from the fixed end: the link that drops into the rear slot on 200, 300 and 450 trunks. Drawn: eight links, the connecting link and the master link.
REV | DESCRIPTION | DATE | BY
P1 | Making sketch for the prototype build plan | 2026-10-03 | AC
TRUNKBELAY | github.com/BoujeeEnjinia1701/trunkbelay

## TrunkBelay: chain set (assemble 1)

DRAWING NO.
TKB-DWG-108

REV
P1

SHEET
1 of 1

SIZE

## ANSI B

SCALE
1:2

UNITS
mm
PROJECTION | DATE
2026-10-03

DRAWN
Amish Chadha

MATERIAL / NOTES
Bought: grade 80 alloy chain 6 mm, master link, connecting link
Licensed CERN-OHL-S-2.0 · Design Molecule Lab · designmolecule.com | Generated from cad/src; do not edit by hand

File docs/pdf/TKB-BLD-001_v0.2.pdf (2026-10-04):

T R U N K B E L AY · B U I L D P L A N

# TrunkBelay prototype build plan

Design Molecule Lab · designmolecule.com

D O C U M E N T CO N T RO L

Document ID | TKB-BLD-001 | Version | 0.2
Status | Draft | Date | 2026-10-03
Author | Amish Chadha | License | CERN-OHL-S-2.0
Project TRL | TRL 3 | Proof of concept
Repository | github.com/BoujeeEnjinia1701/trunkbelay
Source | docs/05-build-plan.md @ uncommitted

R EV I S I O N H I STO RY

Version | Date | Author | Change
0.2 | 2026-10-03 | Amish Chadha | Amish's decisions carried out (TKB- DDR-003); aluminium frame, tag line and micro pulley, pre-rigged victim set, drill rule
0.1 | 2026-10-03 | Amish Chadha | First build plan; design made constructable (TKB-DDR-002)

D R A F T · N O T F O R F A B R I C A T I O N

## TrunkBelay prototype build plan

Plan, not yet built. How to build the first proof-of-concept prototype, component by component. Building and testing to it is TRL 4 work. Decisions and items to confirm are kept in the design decisions register (docs/06-design-decisions.md), not here.

### 1. What you are building

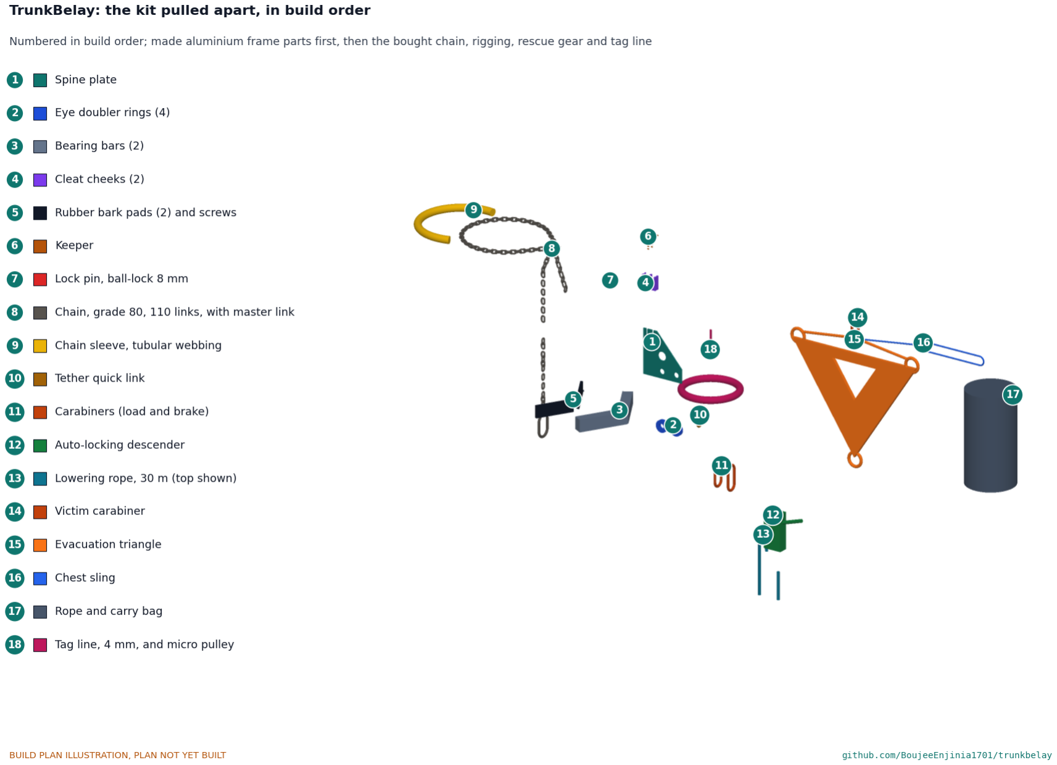
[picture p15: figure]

Figure 1. Every component pulled apart and numbered in build order.
The prototype is a rescue kit that lets one climber anchor and lower another who is stranded on a coconut palm. Figure 1 shows its 18 groups of parts in the order you make or fit them. The collar frame is one TIG-welded aluminium piece (6082-T6): a 5 mm spine plate with two rubber-faced bearing bars in a V at its foot, two chain slots in its top stiffened by a cheek plate on each face, and a load eye and a spare eye at its outer end. A 6 mm grade 80 chain wraps the trunk once and is held in the slots by a sheet-steel keeper and a ball-lock pin. An auto-locking descender, three carabiners, 30 m of rope, an evacuation triangle, a chest sling, a rope bag and a 4 mm tag line with a micro pulley complete the kit. The rescuer climbs with the collar, the chain, the descender and two carabiners, about 4.6 kg; the helpers on the ground haul the bag with the rope and the pre-rigged victim set up on the tag line.

The frame parts are profile cut, drilled and TIG welded from aluminium plate and box section and are not galvanised; the pads are cut from rubber sheet; the keeper is cut and bent from steel sheet; everything else is bought. The parts cost about USD 826 from the bill of materials.

Safety: TrunkBelay holds a person at height. The build involves profile cutting, drilling, TIG welding of aluminium (strong ultraviolet light and fumes; the weld zone is weaker than the parent metal) and grinding. Nothing in this plan puts a person on the kit. The first assembly is done on a 300 mm wooden test post at the bench. Nobody is lowered with it, and it is not taken up a palm, until the collar has been proof-tested at 2.5 kN on cut trunk sections and the drill has been run with a dummy at low height (the safety stops in section 6); that is TRL 4 work.

### 2. What changed to make it buildable

The concept showed what the kit does; its parts had no thicknesses, joints or fixings. Each change keeps what the kit does and is recorded in decision record TKB-DDR-002, decided by Amish under his pre-approvals of 2026-10-03. The last four rows carry out Amish's decisions on the requirements (TKB-DDR-003).
Table 1. Changes from the concept.

Component | The concept had | The buildable design has | Why
Bark bearing | A padded curved plate | Two aluminium box bars, 50 x 40 x 3 mm, in a 120 deg V, each with a 10 mm rubber pad (Figures 6 and 10) | Fits every trunk from 200 to 450 mm on two lines
Frame | Not defined | One 5 mm spine plate carrying the bars, the chain slots and both eyes (Figure 2) | One plate ties every load together
Cleat | A slotted cleat | Two 7.5 mm slots, 35 mm deep, in the spine top with a notched 8 mm cheek on each face (Figure 12) | The chain pulls across the plate; the cheeks stop it twisting
Lock | Not defined | A bent sheet keeper over both slots, held by a ball- lock pin (Figure 12) | A link cannot lift out of its slot
Fixed chain end | Not defined | In the front slot, its tail tied to the spare eye with a quick link (Figure 16) | The chain cannot be dropped at height
Eyes | "On the collar" | 22 mm holes with a 4 mm ring welded each side, edges rounded (Figure 4) | A carabiner never bears on a thin plate edge
Lever | Not defined | Load eye 150 mm out from the frame's front edge; chain 160 mm above its foot | Makes the collar grip harder as the load rises
Chain padding | The plate | 600 mm of tubular webbing on the chain at the back of the trunk (Figure 15) | Spreads the chain's pressure on the bark
Brake | A friction device | Auto-locking descender, brake strand turned over a second carabiner (Figure 17) | Halves the hand force; holds if the rescuer lets go
Frame metal | Welded steel, galvanised | 6082-T6 aluminium, TIG welded, not galvanised; bars 50 x 40 x 3, cheeks 8 mm, spine top 10 mm higher, spare eye 15 mm further back | The rescuer carries under 5 kg (R7); sized on the weaker metal beside the welds
Getting the kit up | Everything carried up the trunk | The helpers haul the rope bag up on a 4 mm tag line through a micro pulley on the rescuer's harness (Figure 28) | Takes 3.7 kg off the climb (R7)
Victim set | Packed loose | Packed pre-rigged: rope loop, triangle waist loops and one end of the chest sling already on the victim carabiner (Figure 28)

Saves about 45 s at height (R4)

Collar
position

Drill as modelled Drill rule kept: the collar at least 300 mm above the point where the rope meets the victim (S6)

The collar holds only a downward pull (R2)

### 3. Making the components

Make and check each component before the assembly step that needs it. Sizes are in millimetres. "Front" means toward the trunk; "back" means away from it, toward the load eye. Workshop tolerance is 0.5 mm unless a step says otherwise. TIG weld (AC) with ER5356 filler; fillets are 5 mm unless stated. Clean every joint with a stainless brush and solvent just before welding. Aluminium beside a weld is about half as strong as the plate, and the sizes allow for that: never add a weld the plan does not show, and never repair a cracked weld; make a new part. Grind every weld that a chain link, rope or carabiner could touch smooth and round. Mark every piece with paint marker.

### 3.1 Spine plate

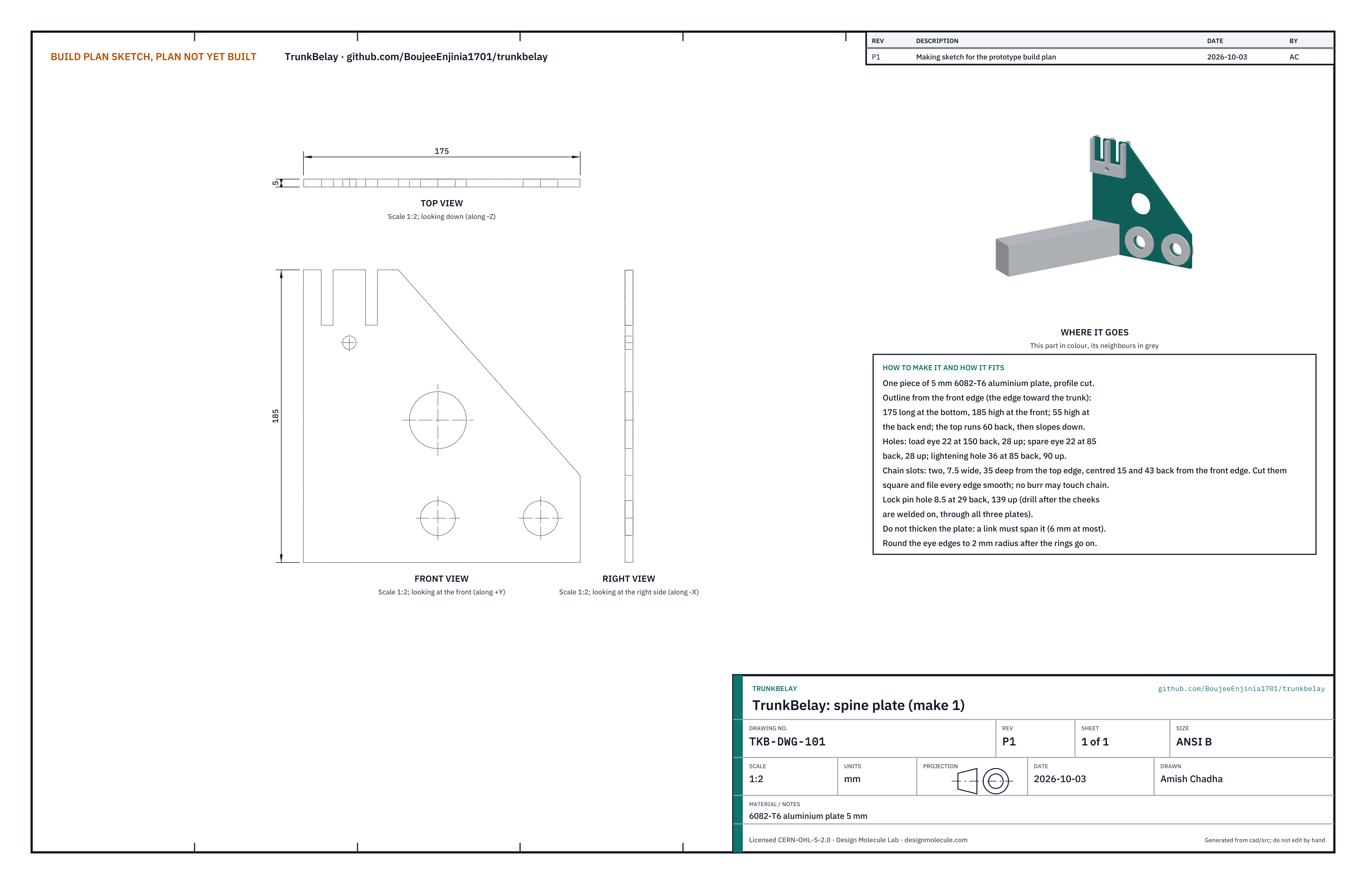
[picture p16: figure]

Figure 2. Spine plate making sketch (TKB-DWG-101).
What it is and what it is made from. The backbone of the collar frame. One piece of 5 mm 6082-T6 aluminium plate.
How to make it.
Have the outline profile cut (waterjet, or plasma with the edges filed back 1 mm): 175 long along the bottom, 185 high at the front edge, 55 high at the back end, the top level for 60 back from the front edge and then sloping down to the back end.
Have these holes cut with it: the load eye, 22, centred 150 back from the front edge and 28 up from the bottom; the spare eye, 22, at 85 back and 28 up; a 36 lightening hole at 85 back and 90 up.
Have the two chain slots cut down from the top edge: each 7.5 wide and 35 deep, centred 15 and 43 back from the front edge. They must be square and clean; file off every burr.
Do not drill the pin hole yet; it is drilled through the cheeks and the plate together (section 3.4).

How it fits the parts next to it. The bearing bars are welded to both faces of its foot, the eye rings round its eyes and the cheeks on both faces of its top (Figure 8). The plate must stay 5 mm: a chain link has to reach right through a slot so that the next link bears on the far face.
Check. A 7 mm bar slides down each slot to the bottom; a 22 mm bar passes each eye.

1.

2.

3.

4.

### 3.2 Eye doubler rings

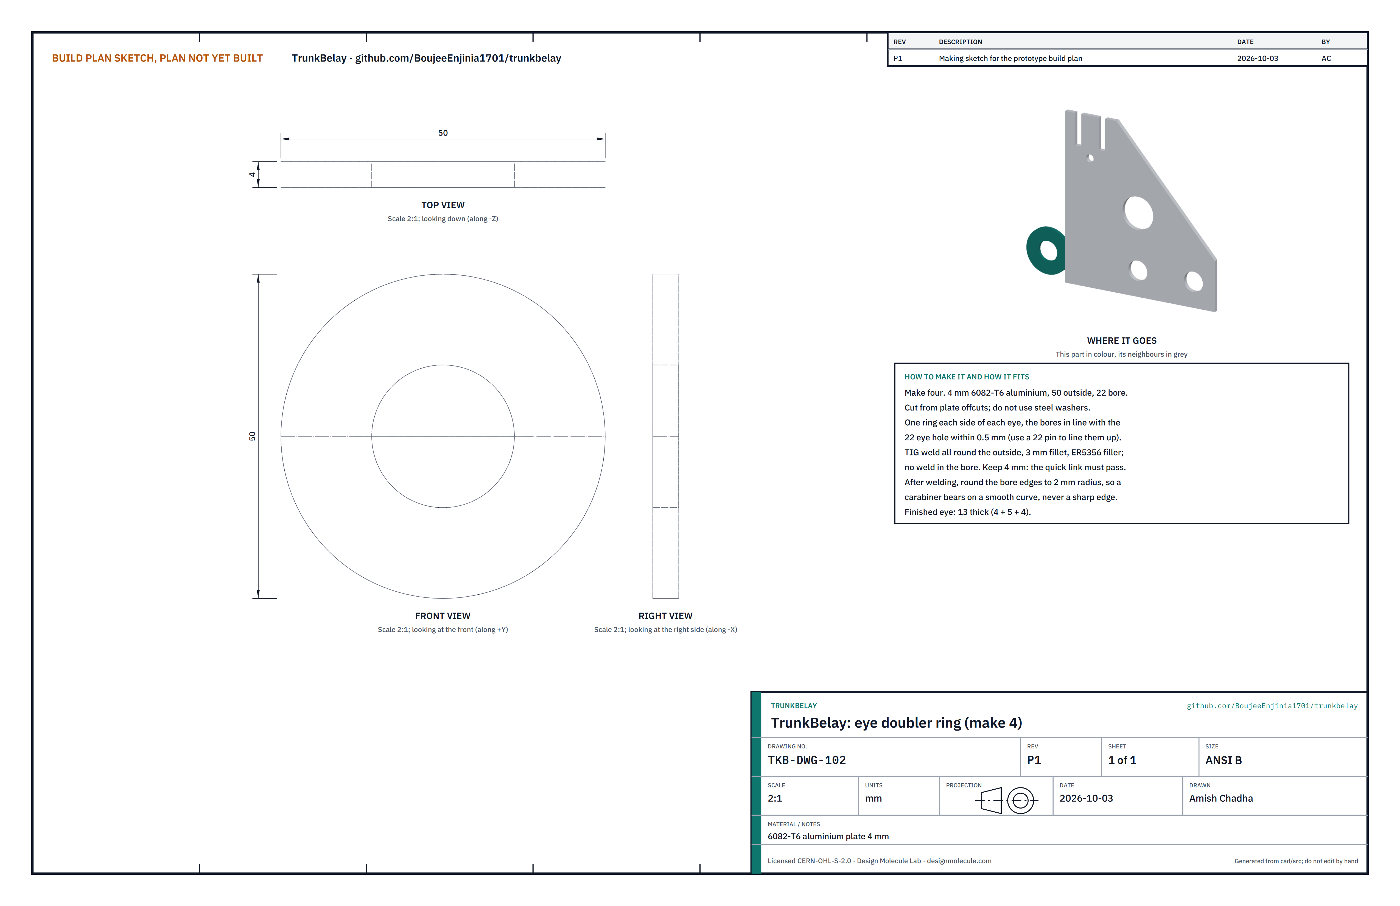
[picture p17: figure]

Figure 3. Eye doubler ring making sketch (TKB-DWG-102).
What it is and what it is made from. Four rings that thicken both eyes so a carabiner bears on a wide, rounded edge. 4 mm 6082-T6 aluminium, 50 outside, 22 bore. Keep them 4 mm: the 8 mm quick link has to pass round the spare eye.
How to make it.
Cut four rings from 4 mm aluminium plate. Do not use steel washers.
Push a 22 mm pin through an eye, slide a ring on each side and clamp them flat to the plate.
TIG weld round the outside of each ring with a 3 mm fillet. Keep weld out of the bore.
After welding, round both bore edges of each eye to a 2 mm radius with a file or rotary burr.

How it fits the parts next to it. Ring, plate and ring make an eye 13 thick with one smooth bore. The load carabiner (Figure 4) and the brake carabiner and quick link (Figure 16) bear on the bottom of these bores.

1.
2.
3.
4.

Figure 4. The load eye cut open: ring, spine and ring under the carabiner bar.
Check. The 22 mm pin turns freely in both eyes; no sharp edge can be felt in either bore.

### 3.3 Bearing bars

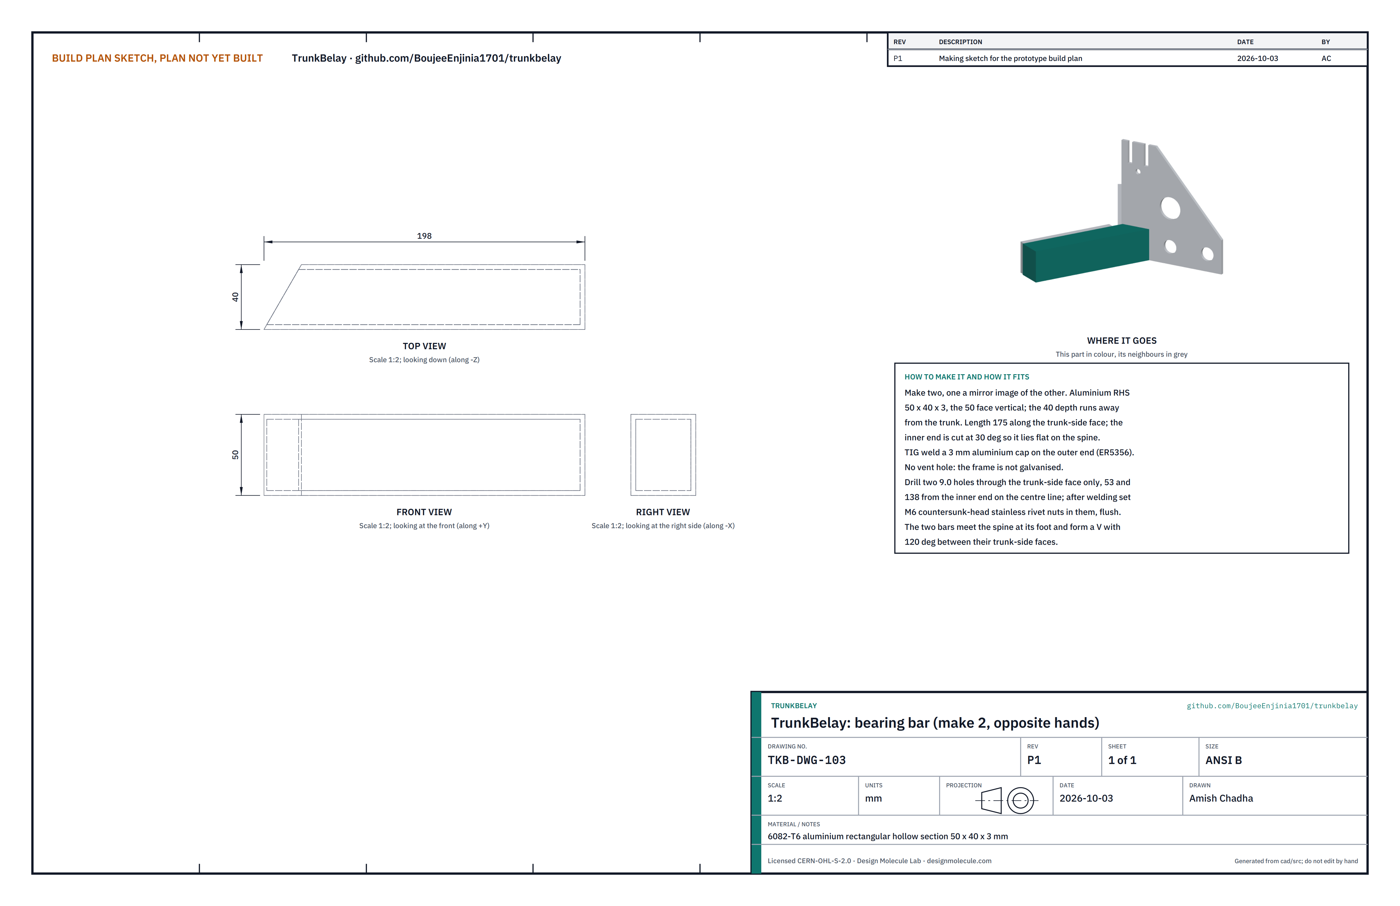
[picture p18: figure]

Figure 5. Bearing bar making sketch (TKB-DWG-103).
What it is and what it is made from. The two short bars that press on the bark, one a mirror image of the other. Aluminium box section, 6082-T6, 50 x 40 x 3 mm.
How to make it.
Cut two lengths so that the 50 mm face that will carry the pad (the front face) is 175 long. Cut the inner end at 30 deg from square, so it lies flat against the spine when the bar points 60 deg away from it; make the second bar the mirror image.
Drill two 9.0 holes through the front face only, on its centre line, 53 and 138 from the inner end, and countersink them lightly for the rivet nuts' heads.
TIG weld a 3 mm aluminium cap plate on the outer end, all round. No vent hole is needed: the frame is not galvanised.
After the frame is welded (section 3.5), set an M6 countersunk-head stainless rivet nut in each hole, flush with the face, with barrier paste on its body.

How it fits the parts next to it. The bars stand with their 50 mm faces upright and their bottoms level with the bottom of the spine. Their inner ends lie flat on the two faces of the spine at its foot, front faces toward the trunk, so the two front faces make a 120 deg V; if extended, they would meet 8 in front of the spine's front edge. A 5 mm fillet runs all round each bar end on the spine face (Figure 6). The back of each bar ends about 12 short of the spare eye's rings, which leaves room for both welds.

1.

2.

3.

4.

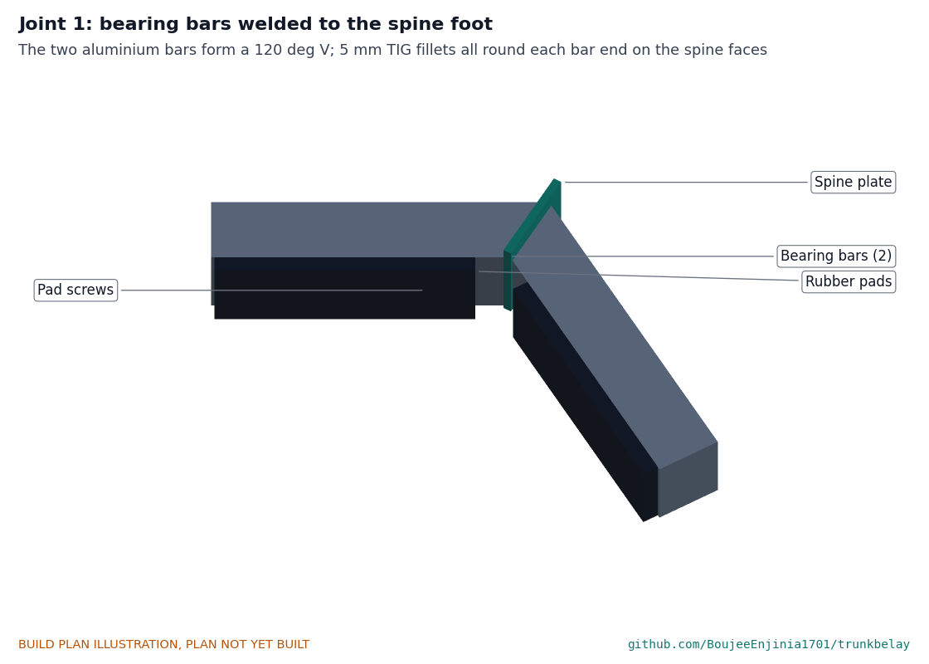
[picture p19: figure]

Figure 6. Joint 1: the two bearing bars welded to the spine foot, seen from above and behind.
Check. The front faces are flat within 1 mm and make 120 deg within 1 deg (use a cut card template).

### 3.4 Cleat cheeks

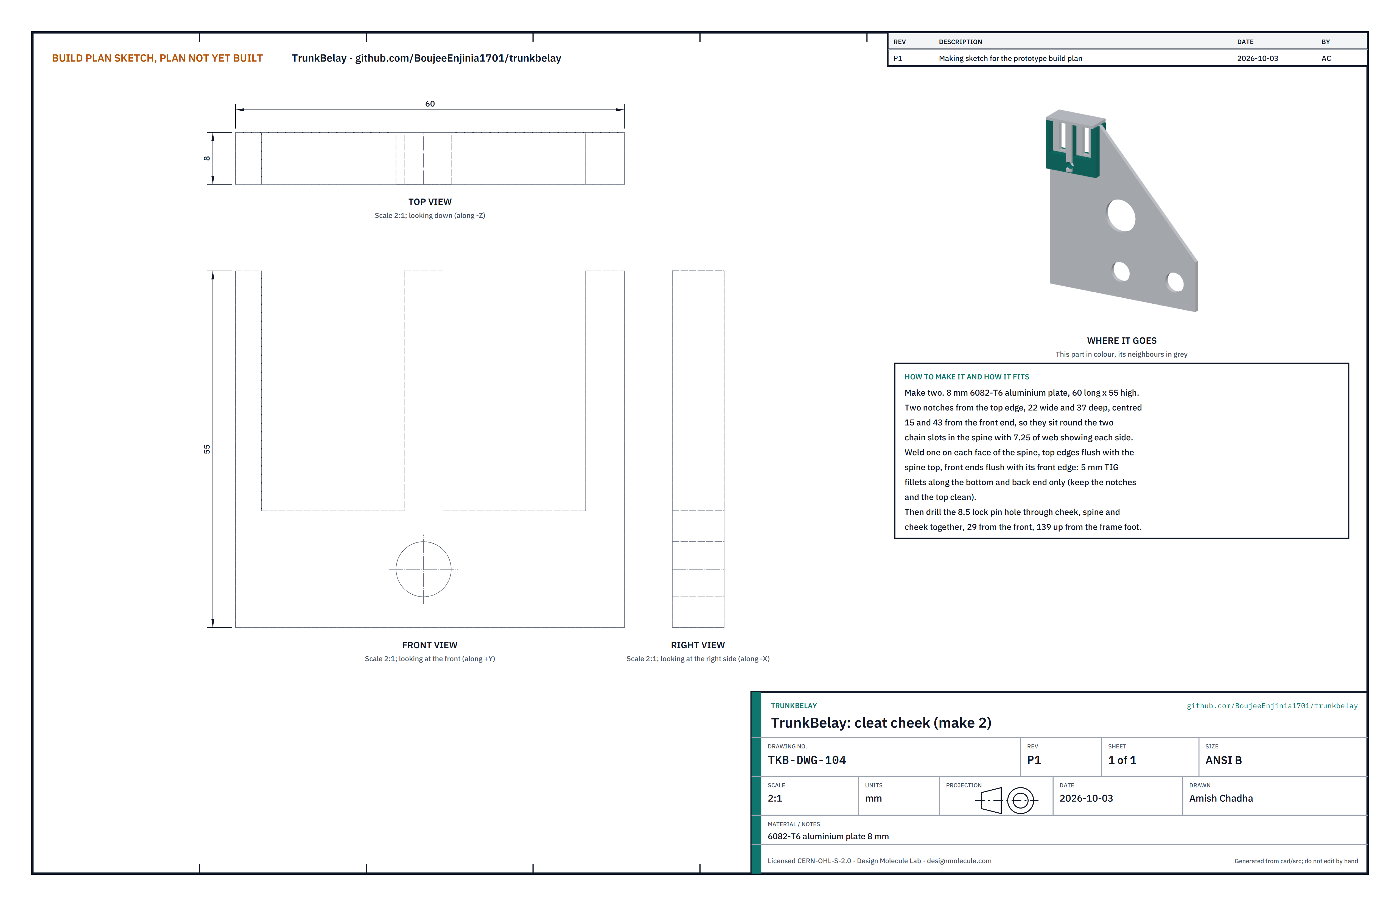
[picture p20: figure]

Figure 7. Cleat cheek making sketch (TKB-DWG-104).
What it is and what it is made from. Two small plates that stiffen the slotted top of the spine. 8 mm 6082-T6 aluminium plate, 60 long and 55 high.
How to make it.
Cut two plates 60 x 55.
Cut two notches in each from the top edge, 22 wide and 37 deep, centred 15 and 43 from the front end. Clamp one on each face of the spine top, top edges flush with the spine top and front ends flush with its front edge, notches round the slots.
Weld along the bottom edge and the back end of each cheek only. Keep the notches and the top edge clean. Drill an 8.5 hole through cheek, spine and cheek together, 29 back from the front edge and 139 up from the bottom of the frame.

How it fits the parts next to it. Inside each notch, 7.25 of the 5 mm spine shows on each side of the slot. That is where the chain links bear (Figure 12). The keeper's legs slide over the cheeks between the notches and the lock pin goes through the hole.
Check. The 8 mm pin slides through all three plates; a chain link laid flat sits inside each notch against the spine.

1.
2.
3.

4.
5.

### 3.5 Frame weldment

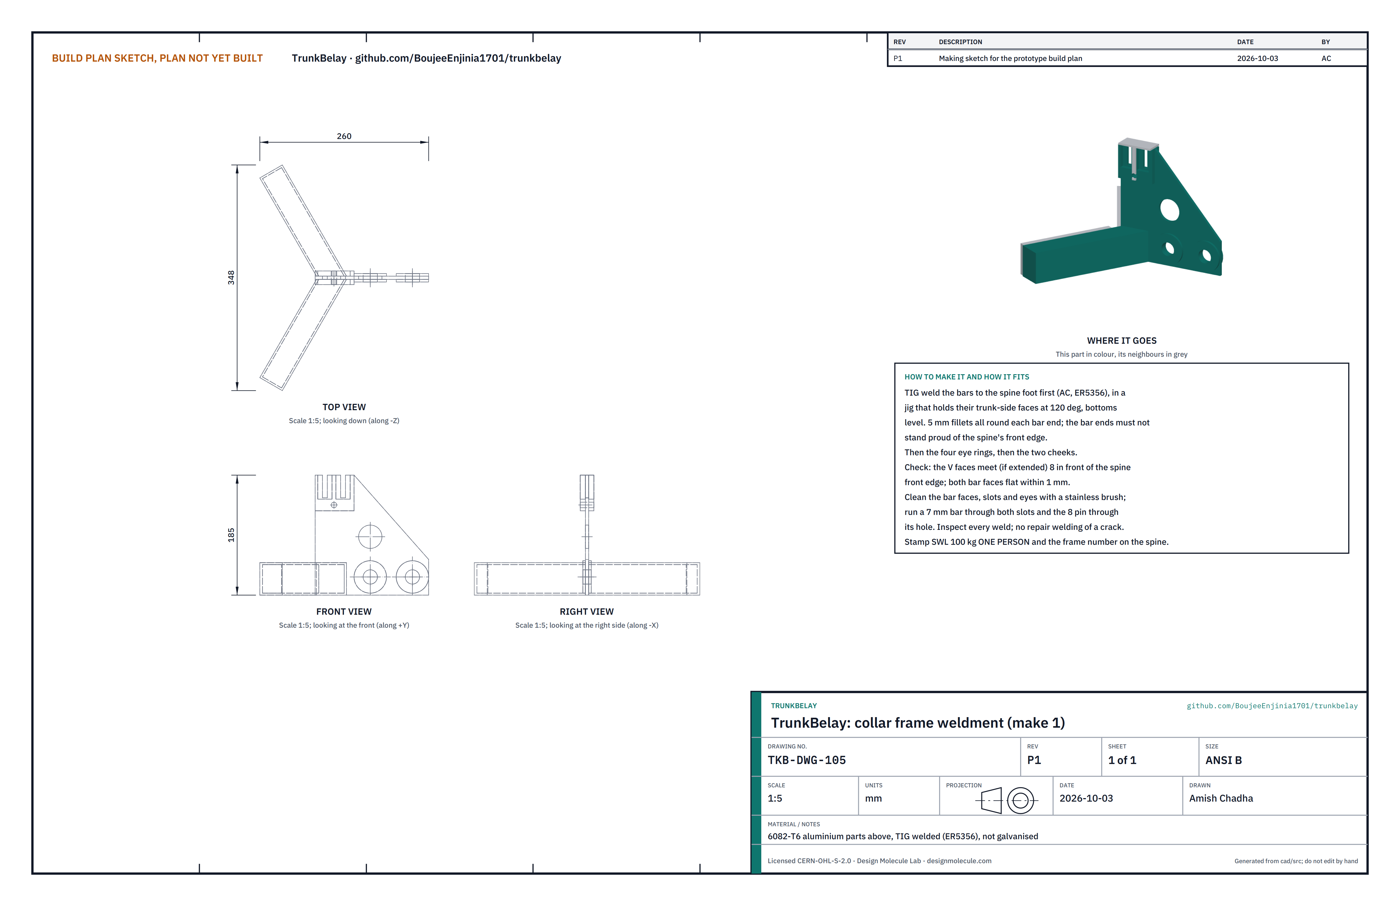
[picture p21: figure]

Figure 8. Collar frame weldment making sketch (TKB-DWG-105).
What it is and what it is made from. The spine, bars, eye rings and cheeks TIG welded into one aluminium piece. It is left bare: 6082 does not rust.
How to make it.
TIG weld the bars to the spine foot in a jig that holds their front faces at 120 deg and their bottoms level with the spine's bottom edge (section 3.3).
Weld the eye rings (section 3.2), then the cheeks, and drill the pin hole (section 3.4).
Clean the bar faces, the slots and the eyes with a stainless wire brush; file any weld bead that a chain link, rope or carabiner could touch smooth and round.
Run a 7 mm bar down both slots and an 8 mm pin through the pin hole by hand.
Stamp "SWL 100 kg ONE PERSON", the frame number and the year on the spine.

How it fits the parts next to it. It carries everything else: the pads on its bars, the chain in its slots, the keeper and pin on its top, the quick link and brake carabiner in its spare eye and the load carabiner in its load eye.
Check. No crack, undercut, porosity or missing weld (a dye penetrant check on the bar welds is worth the small cost); slots and pin hole clear; the frame weighs about 1.0 kg.

1.

2.
3.

4.
5.

### 3.6 Rubber bark pads

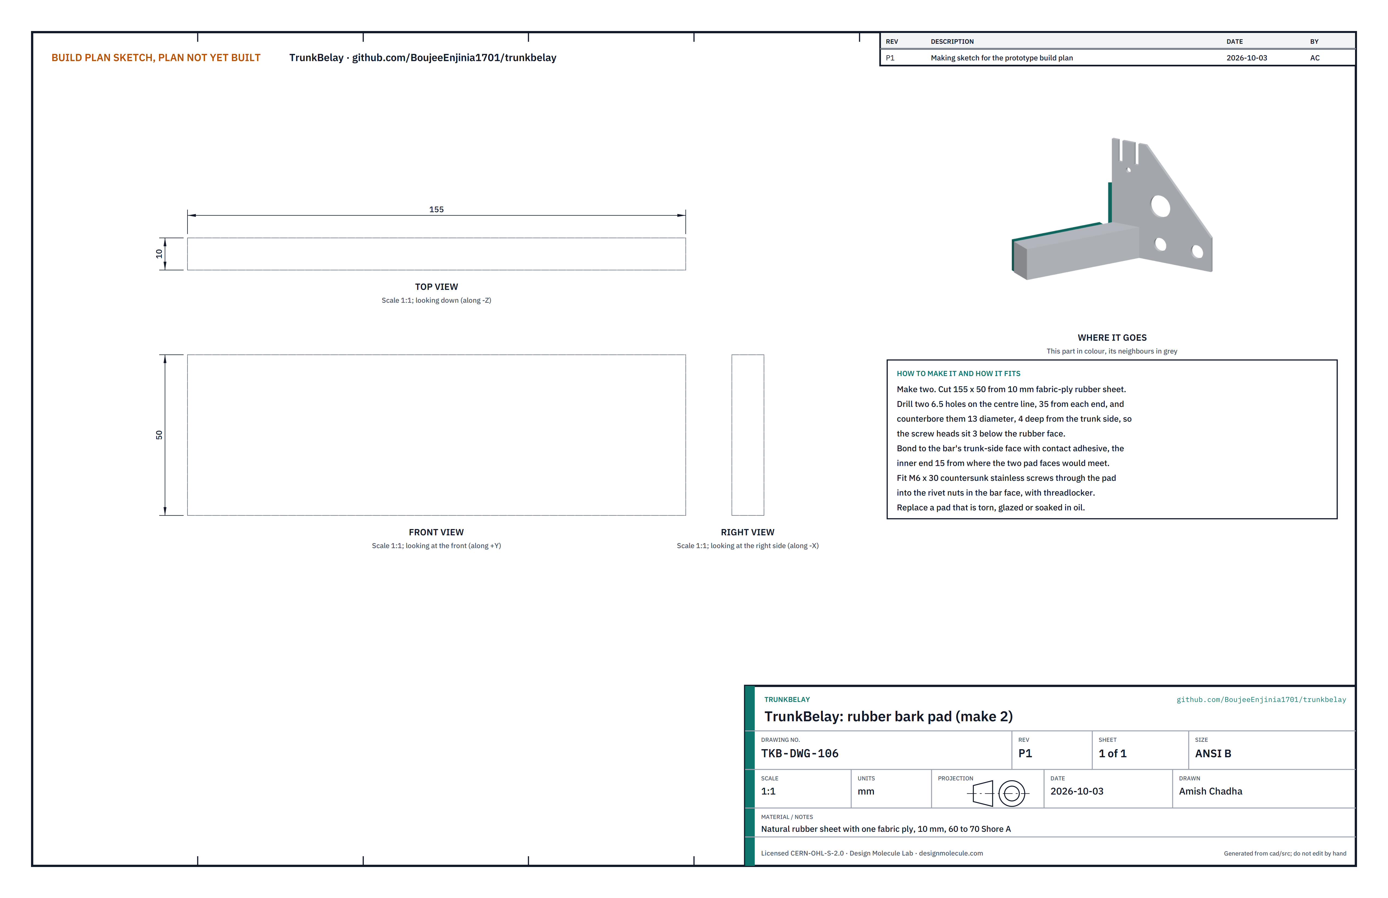
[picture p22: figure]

Figure 9. Rubber bark pad making sketch (TKB-DWG-106).
What it is and what it is made from. The rubber that touches the bark, one on each bar. Natural rubber sheet with one fabric ply, 10 mm thick, 60 to 70 Shore A.
How to make it.
Cut two pads 155 x 50.
Drill two 6.5 holes on each pad's centre line, 35 from each end, and counterbore them 13 across and 4 deep from the face that will touch the bark.
Spread contact adhesive on the pad and on the bar's front face, let it go tacky and press the pad on, its inner end 15 from where the two front faces would meet, its holes over the bar's holes.
Fit an M6 x 30 countersunk stainless screw through each hole into the rivet nut in the bar face, with threadlocker on the thread.

How it fits the parts next to it. The screw heads sit 3 below the rubber face, so only rubber touches the bark (Figure 10).

1.
2.

3.

4.

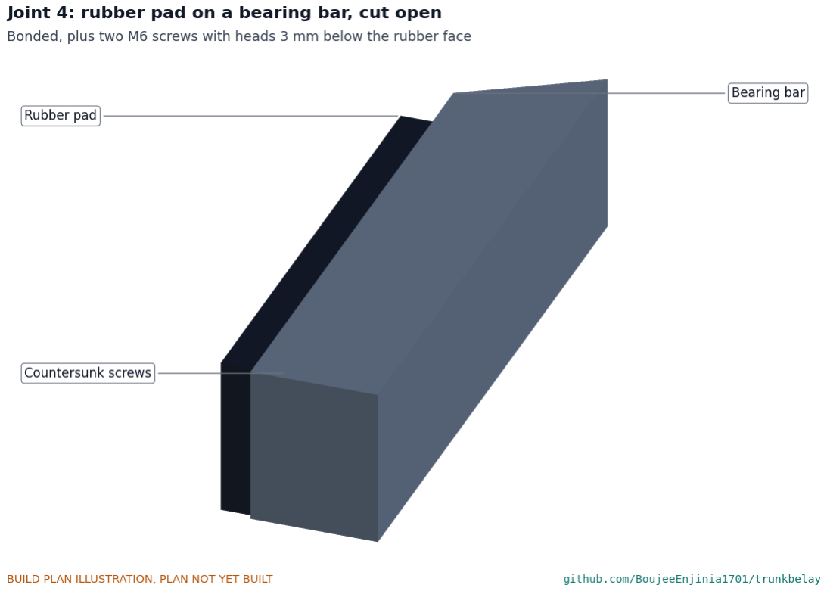
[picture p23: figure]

Figure 10. Joint 4: pad bonded and screwed to the bar's front face, cut open through a screw.
Check. The pad cannot be peeled at any corner; no screw head stands above the bottom of its counterbore.

### 3.7 Keeper

Figure 11. Keeper making sketch (TKB-DWG-107).
What it is and what it is made from. The bent sheet cover that stops a chain link lifting out of its slot. 3 mm steel sheet, zinc plated.
How to make it.
Cut a cross from 3 mm steel sheet: a bridge 56 long and 27 wide, with a leg 6 wide and 53 long from the middle of each long side.
Bend both legs down 90 deg in a vice so they stand 21 apart inside.
Drill an 8.5 hole through both legs, 49 below the top face of the bridge.
Have it zinc plated. Tie the lock pin's lanyard to one leg.

How it fits the parts next to it. The legs slide down over the two cheeks between the notches; the bridge lies on the cleat top across both slot mouths; the lock pin passes through the legs, the cheeks and the spine (Figure 12).

1.

2.
3.
4.

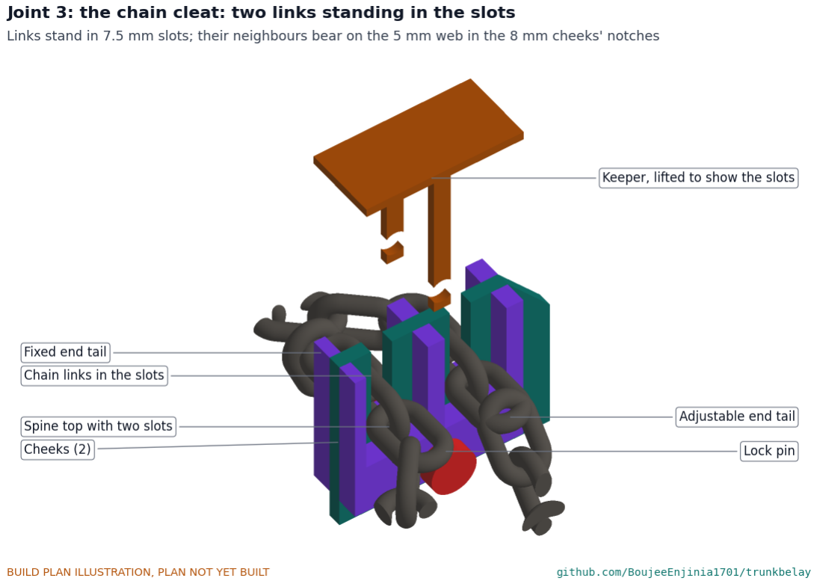
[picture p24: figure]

Figure 12. Joint 3: the chain cleat. Each standing link fills a 7.5 mm slot; the flat links on either side bear on the 5 mm spine inside the notches of the 8 mm cheeks; the keeper and pin hold both links down.
Check. The keeper drops on and off by hand; with it on, the pin goes through and clicks.

### 3.8 Lock pin (bought)

Buy an 8 mm stainless ball-lock pin with a 27 mm grip, a button head and a 300 mm stainless lanyard. Check that it locks through the keeper, cheeks and spine and cannot be pulled out without pressing the button. Tie the lanyard to the keeper.

### 3.9 Chain set

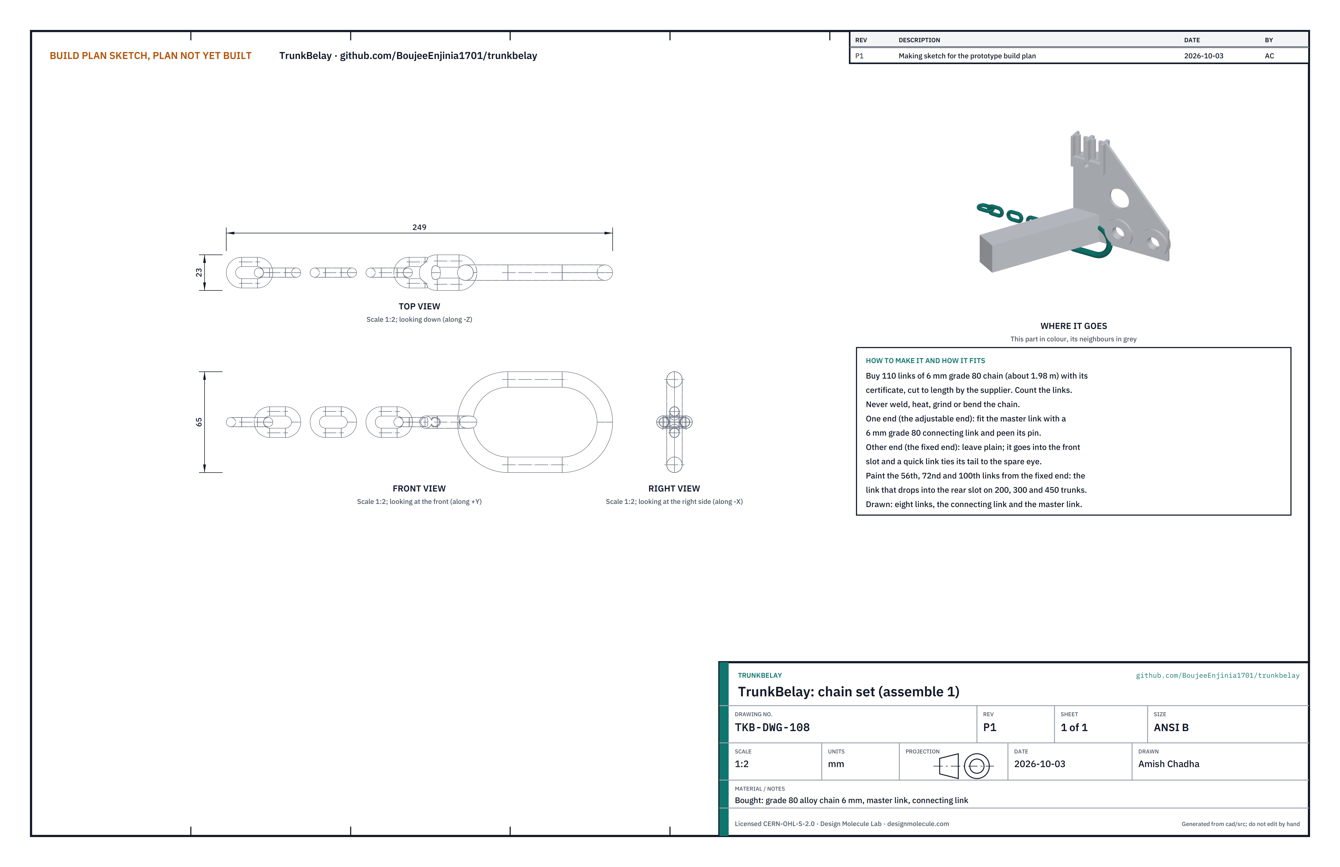
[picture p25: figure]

Figure 13. Chain set making sketch (TKB-DWG-108). Eight of the 110 links are drawn.
What it is and what it is made from. The chain that wraps the trunk. 6 mm grade 80 alloy chain, 110 links (about 1.98 m), with its certificate; a grade 80 master link and a 6 mm grade 80 connecting link.
How to make it.
Have the supplier cut 110 links. Count them. Never weld, heat, grind or bend grade 80 chain.
Feed the chain sleeve on (section 3.10) before you fit the master link.
Fit the master link to one end (the adjustable end) with the connecting link, and close the connecting link as its maker says.
Paint the 56th, 72nd and 100th links counted from the plain end (the fixed end): these are the links that drop into the rear slot on trunks of about 200, 300 and 450 mm.

How it fits the parts next to it. The fixed end goes into the front slot; its tail runs down to the spare eye and is tied there with the quick link (Figure 16). The chain wraps the trunk once and the adjustable end goes into the rear slot (Figure 12).
Check. 110 links, no damaged link, certificate kept with the kit.

1.
2.
3.

4.
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

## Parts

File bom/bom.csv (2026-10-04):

item | qty | spec | supplier | unit_cost_usd | make_buy | notes
1 | 1 | Spine plate: 6082-T6 aluminium plate 5 mm, profile cut 175 x 185 mm with two chain slots, two eyes, pin hole and lightening hole | Local fabricator (waterjet or plasma cutting) | 8.00 | make | Drawing TKB-DWG-101; also the web of the chain cleat. Price basis: 0.3 kg of 6082 plate at about USD 8/kg plus a cutting charge (TKB-DDR-003)
2 | 2 | Bearing bars: 6082-T6 aluminium rectangular hollow section 50 x 40 x 3 mm, 175 long, mitred at one end, 3 mm end cap at the other | Aluminium stockist | 4.00 | make | Drawing TKB-DWG-103; no vent hole needed (not galvanised). Price basis: 0.27 kg of 6082 tube at about USD 9/kg plus cutting (TKB-DDR-003)
3 | 4 | Eye doubler rings: 6082-T6 aluminium, 50 mm outside, 22 mm bore, 4 mm thick | Local steel fabricator | 1.00 | make | Drawing TKB-DWG-102; two each side of each eye. Price basis: cut from 4 mm plate offcut, mostly cutting (TKB-DDR-003)
4 | 2 | Cleat cheeks: 6082-T6 aluminium plate 8 mm, 60 x 55 mm, two 22 mm notches and an 8.5 mm pin hole | Local steel fabricator | 2.00 | make | Drawing TKB-DWG-104. Price basis: 8 mm plate offcut plus cutting (TKB-DDR-003)
5 | 1 | TIG welding (AC, ER5356 filler) and abrasive cleaning of the aluminium frame weldment, about 1.0 kg; no galvanising | Local fabricator with an AC TIG welder | 45.00 | make | Drawing TKB-DWG-105; service cost. Price basis: about 1.5 h of skilled TIG welding at local shop rates, filler and gas (TKB-DDR-003)
6 | 2 | Rubber bark pads: natural rubber sheet with one fabric ply, 10 mm, 60 to 70 Shore A, cut 155 x 50 mm | Industrial rubber dealer | 3.00 | make | Drawing TKB-DWG-106
7 | 4 | Pad screws: M6 x 30 countersunk stainless A2, each in an M6 countersunk-head stainless rivet nut set in the bar face | Fastener dealer | 0.90 | buy | Heads sunk 3 mm below the rubber face; rivet nuts set with barrier paste against galvanic corrosion. Price basis: screw about USD 0.40 plus rivet nut about USD 0.50 (TKB-DDR-003)
8 | 1 | Contact adhesive for rubber to aluminium (polychloroprene), 250 ml | Hardware store | 4.00 | buy | For the pads
9 | 1 | Keeper: S275 steel sheet 3 mm, cut cross-shaped and bent, zinc plated | Local steel fabricator | 3.00 | make | Drawing TKB-DWG-107; legs 21 mm apart inside
10 | 1 | Lock pin: ball-lock pin 8 mm, stainless, 27 mm grip, button head, with a 300 mm stainless lanyard | Industrial fastener supplier | 18.00 | buy | Lanyard to the keeper; grip matches the 27 mm stack of keeper, cheeks and web (TKB-DDR-003)
11 | 1 | Chain: grade 80 alloy chain 6 mm, 110 links (about 1.98 m), working load limit 1.12 t, minimum breaking force 45 kN, with certificate | Lifting and rigging supplier | 36.00 | buy | Drawing TKB-DWG-108 (cut to length by the supplier; never weld or heat it)
12 | 1 | Master link, grade 80, for 6 mm chain | Lifting and rigging supplier | 8.00 | buy | On the end of the adjustable tail (handle)
13 | 1 | Connecting link, grade 80, 6 mm | Lifting and rigging supplier | 5.00 | buy | Joins the master link to the chain
14 | 1 | Tether quick link: 8 mm steel screw-gate quick link (maillon), zinc plated | Lifting and rigging supplier | 3.00 | buy | Fixed chain end to the spare eye
15 | 1 | Chain sleeve: 50 mm (2 in) tubular nylon webbing, 600 mm, ends heat-sealed | Climbing or rescue supplier | 4.00 | make | Drawing TKB-DWG-109
16 | 3 | Carabiners: aluminium alloy, screw-gate locking, EN 362 class B or equal, 25 kN major axis | Rope rescue equipment supplier | 15.00 | buy | Load eye, brake redirect, victim connector (packed pre-rigged with the victim set)
17 | 1 | Auto-locking rope descender with anti-panic function, for 10.5 to 11.5 mm rope, rated for a one-person rescue load (EN 341 class A or EN 12841 type C, or equal) | Rope rescue equipment supplier | 280.00 | buy | Specification not brand; follow the maker's instructions
18 | 30 | Lowering rope: 11 mm semi-static kernmantle, EN 1891 type A or equal, sold per metre | Rope rescue equipment supplier | 3.50 | buy | 30 m; figure-eight loop at the victim end and a stopper knot at the other
19 | 1 | Evacuation triangle, EN 1498 class B or equal | Rope rescue equipment supplier | 140.00 | buy | Fitted round the victim's hips; packed pre-rigged with its two waist loops on the victim carabiner (TKB-DDR-003)
20 | 1 | Chest sling: 120 cm sewn sling, 22 kN | Climbing or rescue supplier | 12.00 | buy | Keeps the victim's head up once the feet are freed; packed with one end on the victim carabiner
21 | 1 | Rope and carry bag: 35 l rope bag with shoulder straps and a clip loop | Climbing or rescue supplier | 45.00 | buy | Holds the rope and the pre-rigged victim set; hauled up on the tag line, then lowered to the ground before the lowering
22 | 55 | Tag line: 4 mm polyester accessory cord, about 11 g/m, sold per metre | Climbing or rescue supplier | 0.35 | buy | 55 m runs doubled from the ground through the micro pulley (2 x 25 m plus 5 m); ends heat-sealed. Price basis: retail 4 mm cord at about USD 0.35/m (TKB-DDR-003)
23 | 1 | Micro pulley for 4 to 8 mm cord, with a small screw-gate carabiner | Climbing or rescue supplier | 20.00 | buy | On the rescuer's harness; the helpers haul the bag through it. Price basis: retail micro pulley class about USD 15 plus a light carabiner (TKB-DDR-003)

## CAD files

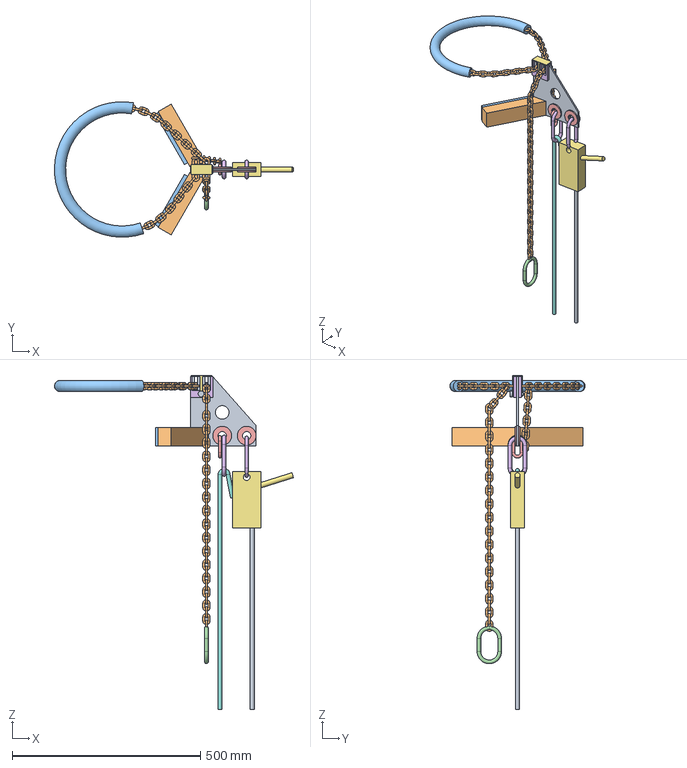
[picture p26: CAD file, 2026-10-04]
cad/step/trunkbelay-assembly.step
635.6 x 359.7 x 888.0 mm

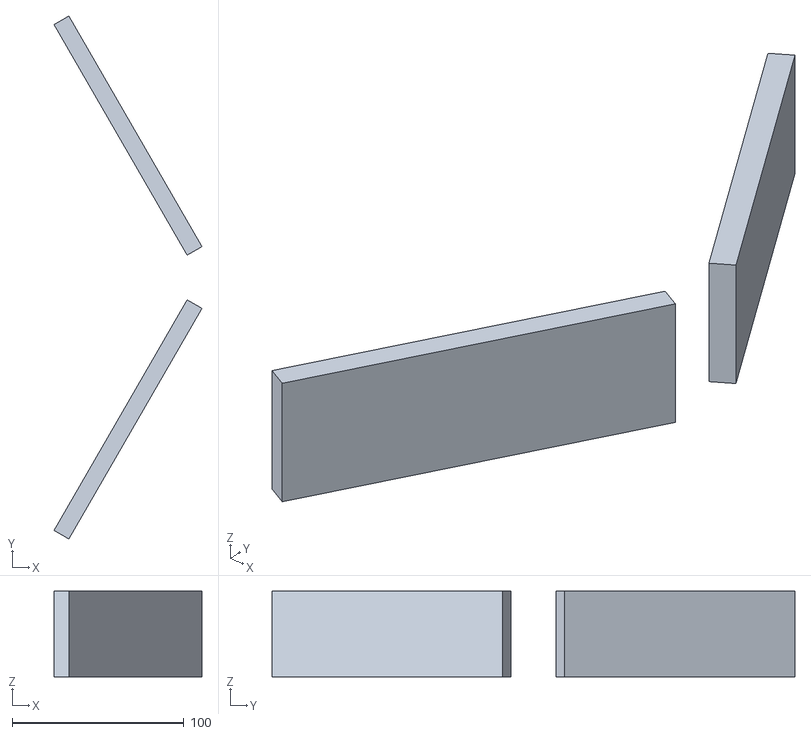
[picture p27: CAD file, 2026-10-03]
cad/stl/trunkbelay-pads.stl
86.2 x 304.4 x 50.0

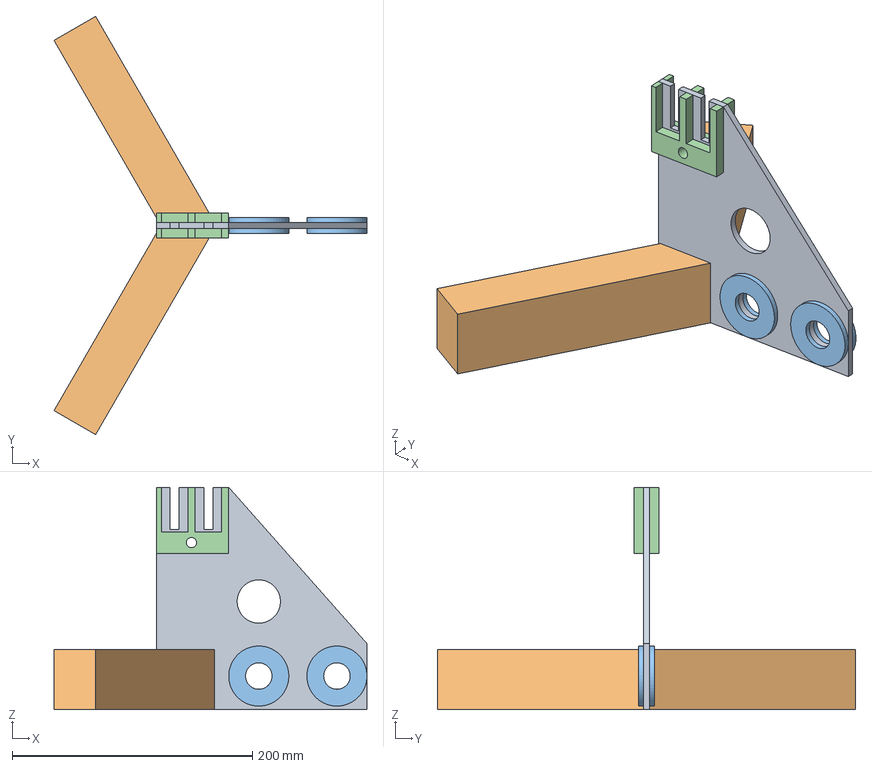
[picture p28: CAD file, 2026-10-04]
cad/step/trunkbelay-frame-weldment.step
260.3 x 347.9 x 185.0 mm

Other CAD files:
cad/stl/trunkbelay-frame-weldment.stl

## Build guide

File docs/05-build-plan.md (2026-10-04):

---
doc_id: TKB-BLD-001
title: TrunkBelay prototype build plan
project: TrunkBelay
doc_type: Build plan
version: "0.2"
status: Draft
date: '2026-10-03'
author: Amish Chadha
license: CERN-OHL-S-2.0
revisions:
- version: "0.1"
  date: '2026-10-03'
  author: Amish Chadha
  change: First build plan; design made constructable (TKB-DDR-002)
- version: "0.2"
  date: '2026-10-03'
  author: Amish Chadha
  change: Amish's decisions carried out (TKB-DDR-003); aluminium frame, tag line and micro pulley, pre-rigged victim set, drill rule
---

# TrunkBelay prototype build plan

**Plan, not yet built.** How to build the first proof-of-concept prototype, component by component. Building and testing to it is TRL 4 work. Decisions and items to confirm are kept in the design decisions register ([docs/06-design-decisions.md](06-design-decisions.md)), not here.

## 1. What you are building

Figure 1. Every component, pulled apart and numbered in build order

*Figure 1. Every component pulled apart and numbered in build order.*

The prototype is a rescue kit that lets one climber anchor and lower another who is stranded on a coconut palm. Figure 1 shows its 18 groups of parts in the order you make or fit them. The collar frame is one TIG-welded aluminium piece (6082-T6): a 5 mm spine plate with two rubber-faced bearing bars in a V at its foot, two chain slots in its top stiffened by a cheek plate on each face, and a load eye and a spare eye at its outer end. A 6 mm grade 80 chain wraps the trunk once and is held in the slots by a sheet-steel keeper and a ball-lock pin. An auto-locking descender, three carabiners, 30 m of rope, an evacuation triangle, a chest sling, a rope bag and a 4 mm tag line with a micro pulley complete the kit. The rescuer climbs with the collar, the chain, the descender and two carabiners, about 4.6 kg; the helpers on the ground haul the bag with the rope and the pre-rigged victim set up on the tag line. The frame parts are profile cut, drilled and TIG welded from aluminium plate and box section and are not galvanised; the pads are cut from rubber sheet; the keeper is cut and bent from steel sheet; everything else is bought. The parts cost about USD 826 from the bill of materials.

> **Safety:** TrunkBelay holds a person at height. The build involves profile cutting, drilling, TIG welding of aluminium (strong ultraviolet light and fumes; the weld zone is weaker than the parent metal) and grinding. Nothing in this plan puts a person on the kit. The first assembly is done on a 300 mm wooden test post at the bench. Nobody is lowered with it, and it is not taken up a palm, until the collar has been proof-tested at 2.5 kN on cut trunk sections and the drill has been run with a dummy at low height (the safety stops in section 6); that is TRL 4 work.

## 2. What changed to make it buildable

The concept showed what the kit does; its parts had no thicknesses, joints or fixings. Each change keeps what the kit does and is recorded in decision record TKB-DDR-002, decided by Amish under his pre-approvals of 2026-10-03. The last four rows carry out Amish's decisions on the requirements (TKB-DDR-003).

*Table 1. Changes from the concept.*

| Component | The concept had | The buildable design has | Why |
| --- | --- | --- | --- |
| Bark bearing | A padded curved plate | Two aluminium box bars, 50 x 40 x 3 mm, in a 120 deg V, each with a 10 mm rubber pad (Figures 6 and 10) | Fits every trunk from 200 to 450 mm on two lines |
| Frame | Not defined | One 5 mm spine plate carrying the bars, the chain slots and both eyes (Figure 2) | One plate ties every load together |
| Cleat | A slotted cleat | Two 7.5 mm slots, 35 mm deep, in the spine top with a notched 8 mm cheek on each face (Figure 12) | The chain pulls across the plate; the cheeks stop it twisting |
| Lock | Not defined | A bent sheet keeper over both slots, held by a ball-lock pin (Figure 12) | A link cannot lift out of its slot |
| Fixed chain end | Not defined | In the front slot, its tail tied to the spare eye with a quick link (Figure 16) | The chain cannot be dropped at height |
| Eyes | "On the collar" | 22 mm holes with a 4 mm ring welded each side, edges rounded (Figure 4) | A carabiner never bears on a thin plate edge |
| Lever | Not defined | Load eye 150 mm out from the frame's front edge; chain 160 mm above its foot | Makes the collar grip harder as the load rises |
| Chain padding | The plate | 600 mm of tubular webbing on the chain at the back of the trunk (Figure 15) | Spreads the chain's pressure on the bark |
| Brake | A friction device | Auto-locking descender, brake strand turned over a second carabiner (Figure 17) | Halves the hand force; holds if the rescuer lets go |
| Frame metal | Welded steel, galvanised | 6082-T6 aluminium, TIG welded, not galvanised; bars 50 x 40 x 3, cheeks 8 mm, spine top 10 mm higher, spare eye 15 mm further back | The rescuer carries under 5 kg (R7); sized on the weaker metal beside the welds |
| Getting the kit up | Everything carried up the trunk | The helpers haul the rope bag up on a 4 mm tag line through a micro pulley on the rescuer's harness (Figure 28) | Takes 3.7 kg off the climb (R7) |
| Victim set | Packed loose | Packed pre-rigged: rope loop, triangle waist loops and one end of the chest sling already on the victim carabiner (Figure 28) | Saves about 45 s at height (R4) |
| Collar position | Drill as modelled | Drill rule kept: the collar at least 300 mm above the point where the rope meets the victim (S6) | The collar holds only a downward pull (R2) |

## 3. Making the components

Make and check each component before the assembly step that needs it. Sizes are in millimetres. "Front" means toward the trunk; "back" means away from it, toward the load eye. Workshop tolerance is 0.5 mm unless a step says otherwise. TIG weld (AC) with ER5356 filler; fillets are 5 mm unless stated. Clean every joint with a stainless brush and solvent just before welding. Aluminium beside a weld is about half as strong as the plate, and the sizes allow for that: never add a weld the plan does not show, and never repair a cracked weld; make a new part. Grind every weld that a chain link, rope or carabiner could touch smooth and round. Mark every piece with paint marker.

### 3.1 Spine plate

Figure 2. Making sketch of the spine plate

*Figure 2. Spine plate making sketch (TKB-DWG-101).*

**What it is and what it is made from.** The backbone of the collar frame. One piece of 5 mm 6082-T6 aluminium plate.

**How to make it.**

1. Have the outline profile cut (waterjet, or plasma with the edges filed back 1 mm): 175 long along the bottom, 185 high at the front edge, 55 high at the back end, the top level for 60 back from the front edge and then sloping down to the back end.
2. Have these holes cut with it: the load eye, 22, centred 150 back from the front edge and 28 up from the bottom; the spare eye, 22, at 85 back and 28 up; a 36 lightening hole at 85 back and 90 up.
3. Have the two chain slots cut down from the top edge: each 7.5 wide and 35 deep, centred 15 and 43 back from the front edge. They must be square and clean; file off every burr.
4. Do not drill the pin hole yet; it is drilled through the cheeks and the plate together (section 3.4).

**How it fits the parts next to it.** The bearing bars are welded to both faces of its foot, the eye rings round its eyes and the cheeks on both faces of its top (Figure 8). The plate must stay 5 mm: a chain link has to reach right through a slot so that the next link bears on the far face.

**Check.** A 7 mm bar slides down each slot to the bottom; a 22 mm bar passes each eye.

### 3.2 Eye doubler rings

Figure 3. Making sketch of the eye doubler ring

*Figure 3. Eye doubler ring making sketch (TKB-DWG-102).*

**What it is and what it is made from.** Four rings that thicken both eyes so a carabiner bears on a wide, rounded edge. 4 mm 6082-T6 aluminium, 50 outside, 22 bore. Keep them 4 mm: the 8 mm quick link has to pass round the spare eye.

**How to make it.**

1. Cut four rings from 4 mm aluminium plate. Do not use steel washers.
2. Push a 22 mm pin through an eye, slide a ring on each side and clamp them flat to the plate.
3. TIG weld round the outside of each ring with a 3 mm fillet. Keep weld out of the bore.
4. After welding, round both bore edges of each eye to a 2 mm radius with a file or rotary burr.

**How it fits the parts next to it.** Ring, plate and ring make an eye 13 thick with one smooth bore. The load carabiner (Figure 4) and the brake carabiner and quick link (Figure 16) bear on the bottom of these bores.

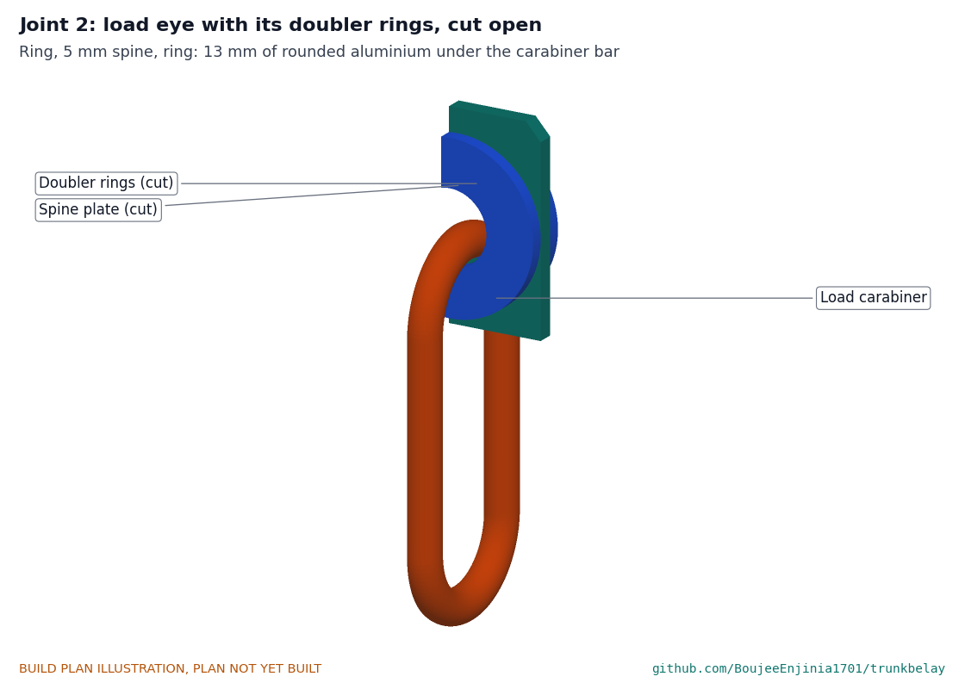
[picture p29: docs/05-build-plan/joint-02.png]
Figure 4. The load eye, cut open, with its carabiner


*Figure 4. The load eye cut open: ring, spine and ring under the carabiner bar.*

**Check.** The 22 mm pin turns freely in both eyes; no sharp edge can be felt in either bore.

### 3.3 Bearing bars

Figure 5. Making sketch of the bearing bar

*Figure 5. Bearing bar making sketch (TKB-DWG-103).*

**What it is and what it is made from.** The two short bars that press on the bark, one a mirror image of the other. Aluminium box section, 6082-T6, 50 x 40 x 3 mm.

**How to make it.**

1. Cut two lengths so that the 50 mm face that will carry the pad (the front face) is 175 long. Cut the inner end at 30 deg from square, so it lies flat against the spine when the bar points 60 deg away from it; make the second bar the mirror image.
2. Drill two 9.0 holes through the front face only, on its centre line, 53 and 138 from the inner end, and countersink them lightly for the rivet nuts' heads.
3. TIG weld a 3 mm aluminium cap plate on the outer end, all round. No vent hole is needed: the frame is not galvanised.
4. After the frame is welded (section 3.5), set an M6 countersunk-head stainless rivet nut in each hole, flush with the face, with barrier paste on its body.

**How it fits the parts next to it.** The bars stand with their 50 mm faces upright and their bottoms level with the bottom of the spine. Their inner ends lie flat on the two faces of the spine at its foot, front faces toward the trunk, so the two front faces make a 120 deg V; if extended, they would meet 8 in front of the spine's front edge. A 5 mm fillet runs all round each bar end on the spine face (Figure 6). The back of each bar ends about 12 short of the spare eye's rings, which leaves room for both welds.

Figure 6. The bearing bars on the spine foot, with the pads

*Figure 6. Joint 1: the two bearing bars welded to the spine foot, seen from above and behind.*

**Check.** The front faces are flat within 1 mm and make 120 deg within 1 deg (use a cut card template).

### 3.4 Cleat cheeks

Figure 7. Making sketch of the cleat cheek

*Figure 7. Cleat cheek making sketch (TKB-DWG-104).*

**What it is and what it is made from.** Two small plates that stiffen the slotted top of the spine. 8 mm 6082-T6 aluminium plate, 60 long and 55 high.

**How to make it.**

1. Cut two plates 60 x 55.
2. Cut two notches in each from the top edge, 22 wide and 37 deep, centred 15 and 43 from the front end.
3. Clamp one on each face of the spine top, top edges flush with the spine top and front ends flush with its front edge, notches round the slots.
4. Weld along the bottom edge and the back end of each cheek only. Keep the notches and the top edge clean.
5. Drill an 8.5 hole through cheek, spine and cheek together, 29 back from the front edge and 139 up from the bottom of the frame.

**How it fits the parts next to it.** Inside each notch, 7.25 of the 5 mm spine shows on each side of the slot. That is where the chain links bear (Figure 12). The keeper's legs slide over the cheeks between the notches and the lock pin goes through the hole.

**Check.** The 8 mm pin slides through all three plates; a chain link laid flat sits inside each notch against the spine.

### 3.5 Frame weldment

Figure 8. Making sketch of the frame weldment

*Figure 8. Collar frame weldment making sketch (TKB-DWG-105).*

**What it is and what it is made from.** The spine, bars, eye rings and cheeks TIG welded into one aluminium piece. It is left bare: 6082 does not rust.

**How to make it.**

1. TIG weld the bars to the spine foot in a jig that holds their front faces at 120 deg and their bottoms level with the spine's bottom edge (section 3.3).
2. Weld the eye rings (section 3.2), then the cheeks, and drill the pin hole (section 3.4).
3. Clean the bar faces, the slots and the eyes with a stainless wire brush; file any weld bead that a chain link, rope or carabiner could touch smooth and round.
4. Run a 7 mm bar down both slots and an 8 mm pin through the pin hole by hand.
5. Stamp "SWL 100 kg ONE PERSON", the frame number and the year on the spine.

**How it fits the parts next to it.** It carries everything else: the pads on its bars, the chain in its slots, the keeper and pin on its top, the quick link and brake carabiner in its spare eye and the load carabiner in its load eye.

**Check.** No crack, undercut, porosity or missing weld (a dye penetrant check on the bar welds is worth the small cost); slots and pin hole clear; the frame weighs about 1.0 kg.

### 3.6 Rubber bark pads

Figure 9. Making sketch of the rubber bark pad

*Figure 9. Rubber bark pad making sketch (TKB-DWG-106).*

**What it is and what it is made from.** The rubber that touches the bark, one on each bar. Natural rubber sheet with one fabric ply, 10 mm thick, 60 to 70 Shore A.

**How to make it.**

1. Cut two pads 155 x 50.
2. Drill two 6.5 holes on each pad's centre line, 35 from each end, and counterbore them 13 across and 4 deep from the face that will touch the bark.
3. Spread contact adhesive on the pad and on the bar's front face, let it go tacky and press the pad on, its inner end 15 from where the two front faces would meet, its holes over the bar's holes.
4. Fit an M6 x 30 countersunk stainless screw through each hole into the rivet nut in the bar face, with threadlocker on the thread.

**How it fits the parts next to it.** The screw heads sit 3 below the rubber face, so only rubber touches the bark (Figure 10).

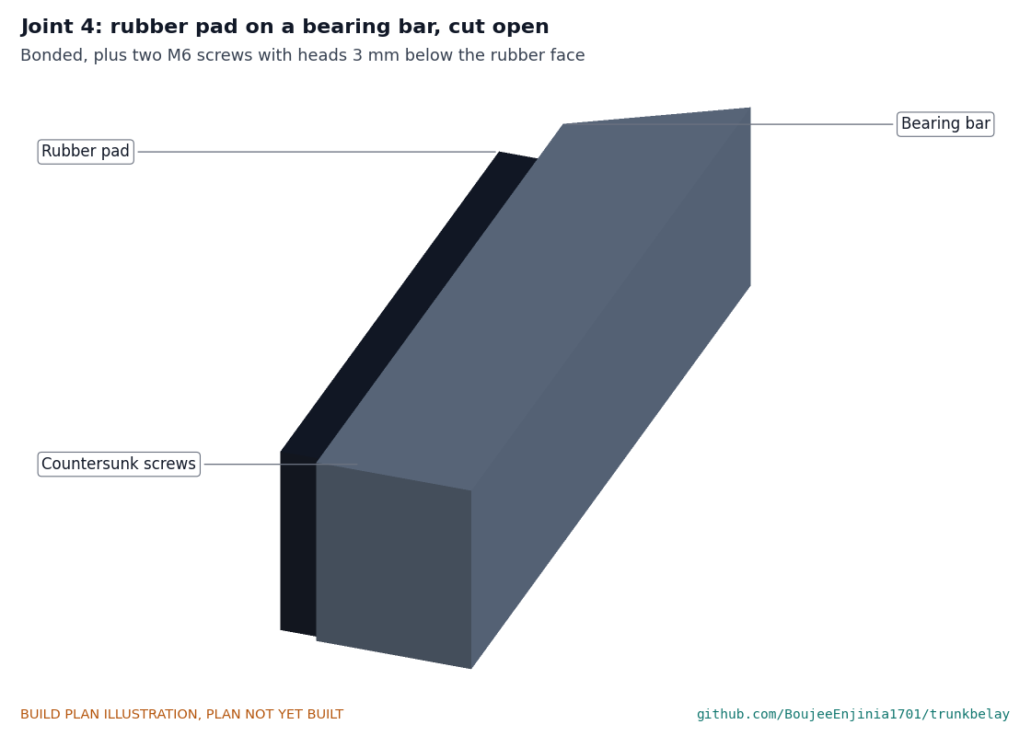
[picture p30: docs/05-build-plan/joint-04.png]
Figure 10. Rubber pad on a bearing bar, cut open


*Figure 10. Joint 4: pad bonded and screwed to the bar's front face, cut open through a screw.*

**Check.** The pad cannot be peeled at any corner; no screw head stands above the bottom of its counterbore.

### 3.7 Keeper

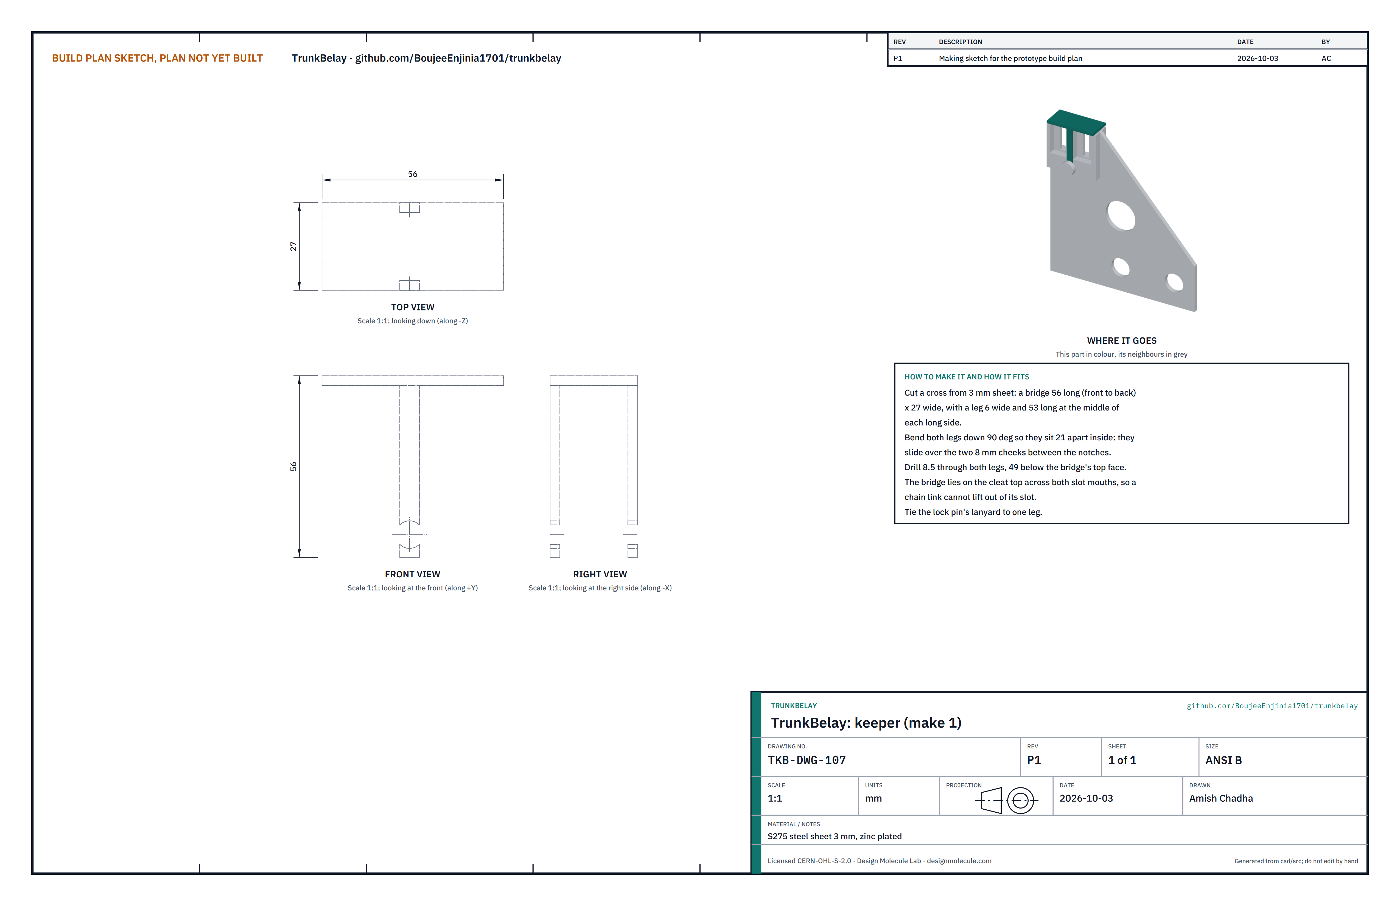
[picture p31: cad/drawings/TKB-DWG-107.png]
Figure 11. Making sketch of the keeper


*Figure 11. Keeper making sketch (TKB-DWG-107).*

**What it is and what it is made from.** The bent sheet cover that stops a chain link lifting out of its slot. 3 mm steel sheet, zinc plated.

**How to make it.**

1. Cut a cross from 3 mm steel sheet: a bridge 56 long and 27 wide, with a leg 6 wide and 53 long from the middle of each long side.
2. Bend both legs down 90 deg in a vice so they stand 21 apart inside.
3. Drill an 8.5 hole through both legs, 49 below the top face of the bridge.
4. Have it zinc plated. Tie the lock pin's lanyard to one leg.

**How it fits the parts next to it.** The legs slide down over the two cheeks between the notches; the bridge lies on the cleat top across both slot mouths; the lock pin passes through the legs, the cheeks and the spine (Figure 12).

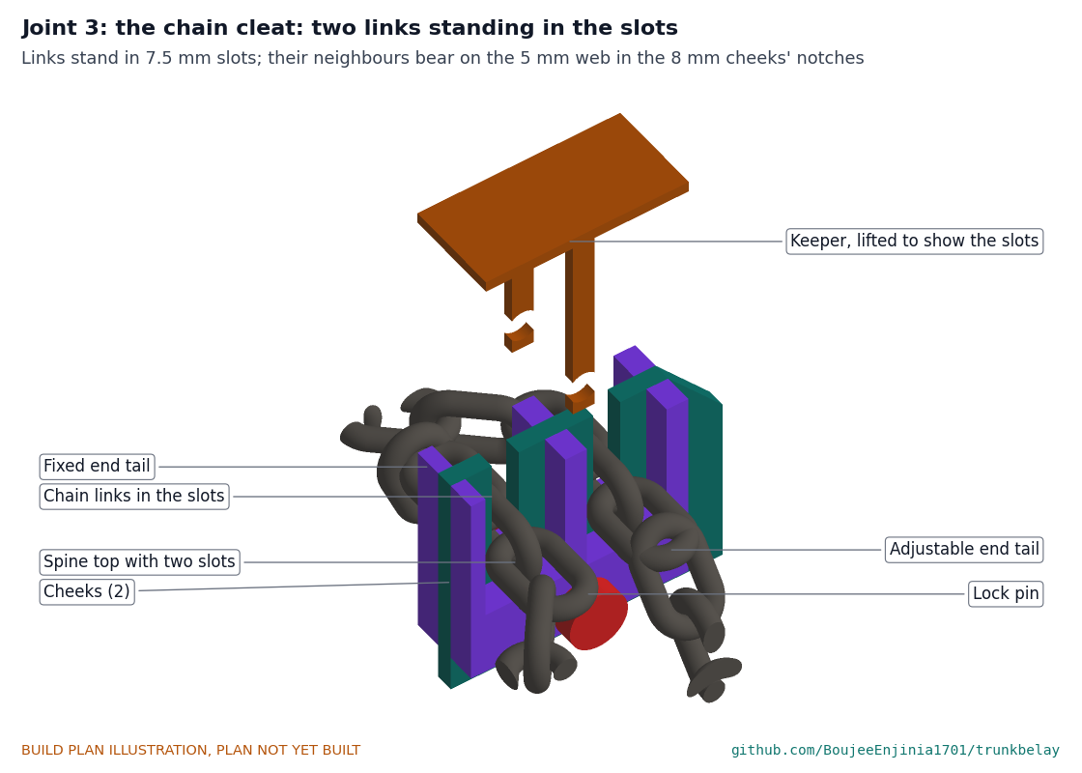
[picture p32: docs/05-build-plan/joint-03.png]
Figure 12. The chain cleat with both chain links, keeper and pin


*Figure 12. Joint 3: the chain cleat. Each standing link fills a 7.5 mm slot; the flat links on either side bear on the 5 mm spine inside the notches of the 8 mm cheeks; the keeper and pin hold both links down.*

**Check.** The keeper drops on and off by hand; with it on, the pin goes through and clicks.

### 3.8 Lock pin (bought)

Buy an 8 mm stainless ball-lock pin with a 27 mm grip, a button head and a 300 mm stainless lanyard. Check that it locks through the keeper, cheeks and spine and cannot be pulled out without pressing the button. Tie the lanyard to the keeper.

### 3.9 Chain set

Figure 13. Making sketch of the chain set

*Figure 13. Chain set making sketch (TKB-DWG-108). Eight of the 110 links are drawn.*

**What it is and what it is made from.** The chain that wraps the trunk. 6 mm grade 80 alloy chain, 110 links (about 1.98 m), with its certificate; a grade 80 master link and a 6 mm grade 80 connecting link.

**How to make it.**

1. Have the supplier cut 110 links. Count them. Never weld, heat, grind or bend grade 80 chain.
2. Feed the chain sleeve on (section 3.10) before you fit the master link.
3. Fit the master link to one end (the adjustable end) with the connecting link, and close the connecting link as its maker says.
4. Paint the 56th, 72nd and 100th links counted from the plain end (the fixed end): these are the links that drop into the rear slot on trunks of about 200, 300 and 450 mm.

**How it fits the parts next to it.** The fixed end goes into the front slot; its tail runs down to the spare eye and is tied there with the quick link (Figure 16). The chain wraps the trunk once and the adjustable end goes into the rear slot (Figure 12).

**Check.** 110 links, no damaged link, certificate kept with the kit.

### 3.10 Chain sleeve

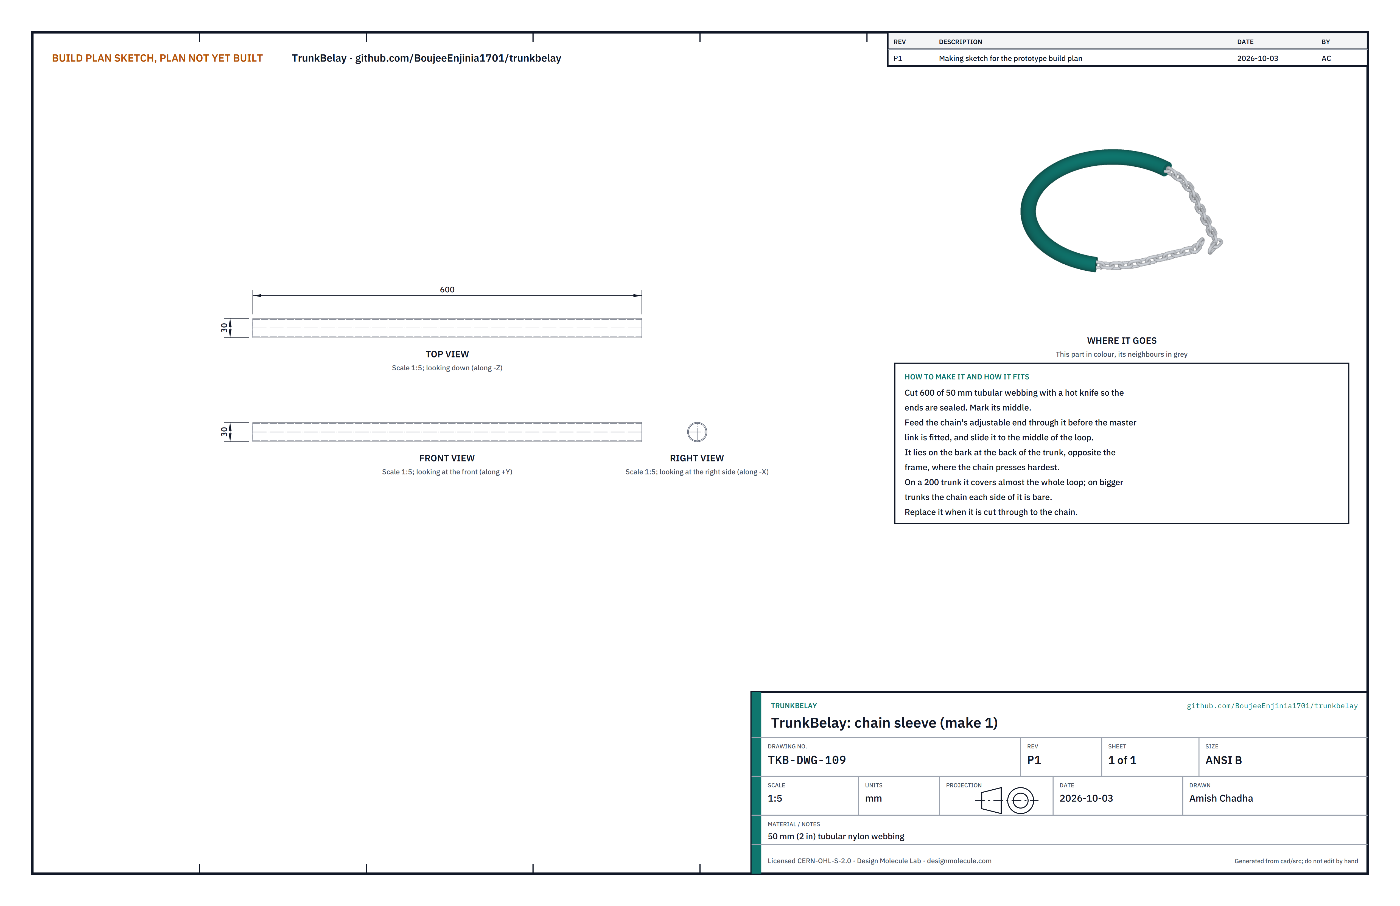
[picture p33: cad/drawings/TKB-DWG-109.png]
Figure 14. Making sketch of the chain sleeve


*Figure 14. Chain sleeve making sketch (TKB-DWG-109).*

**What it is and what it is made from.** A padded sleeve for the part of the chain that presses hardest on the bark. 600 of 50 mm tubular nylon webbing.

**How to make it.**

1. Cut 600 with a hot knife so both ends are sealed.
2. Mark its middle with a marker.
3. Thread the chain through it from the adjustable end before the master link goes on.

**How it fits the parts next to it.** It slides on the chain to the back of the trunk, opposite the frame (Figure 15).

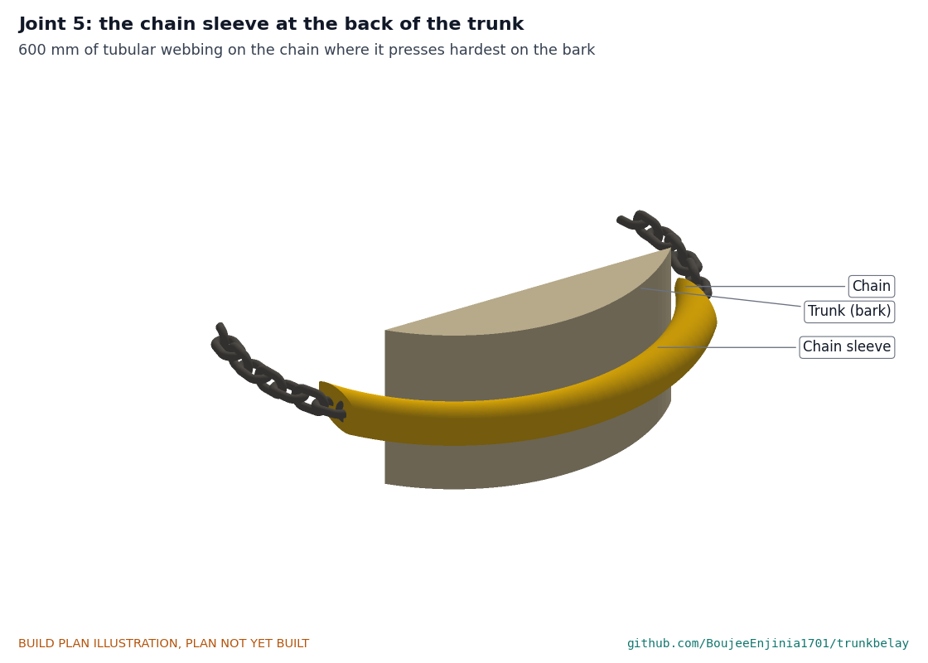
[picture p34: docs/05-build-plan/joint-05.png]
Figure 15. The chain sleeve at the back of the trunk


*Figure 15. Joint 5: the sleeve on the chain where it presses on the back of the trunk.*

**Check.** The sleeve slides freely along the chain.

### 3.11 Tether quick link (bought)

Buy an 8 mm zinc-plated steel screw-gate quick link. It goes through the spare eye and through the last link of the fixed end's tail, and its gate is screwed shut with a spanner, a quarter turn past finger tight (Figure 16).

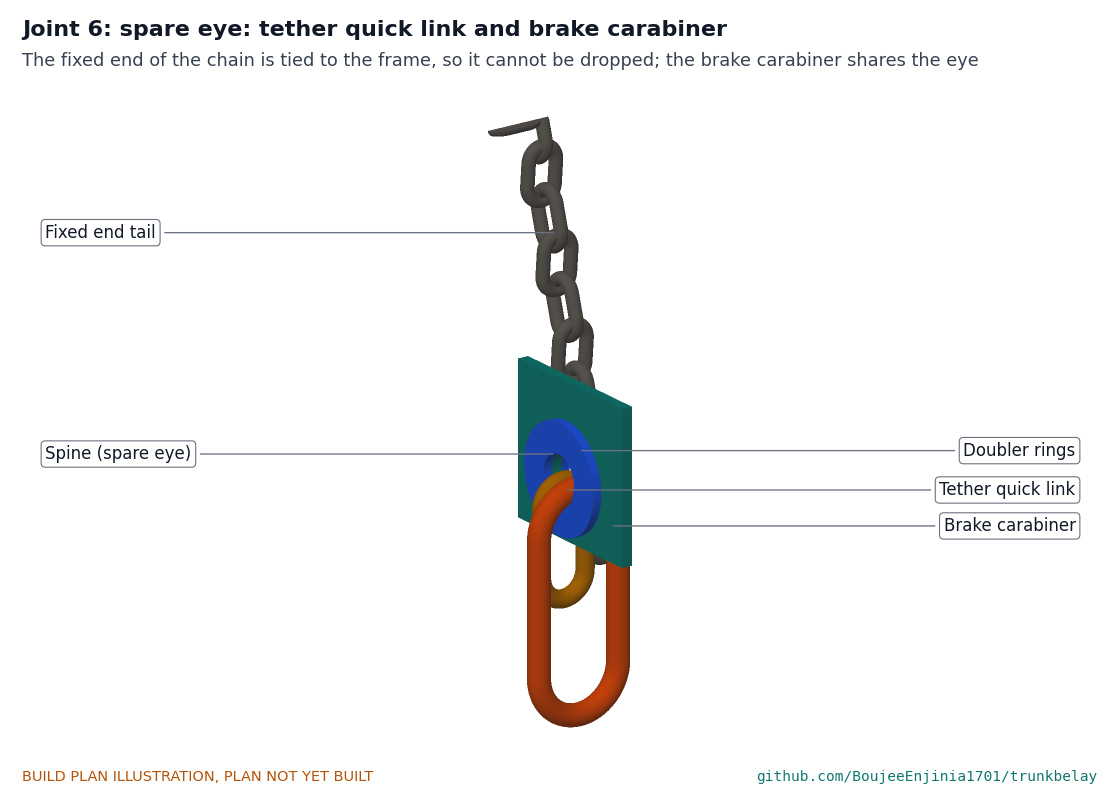
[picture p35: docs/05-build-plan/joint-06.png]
Figure 16. The spare eye with the tether quick link and the brake carabiner


*Figure 16. Joint 6: the spare eye holds the quick link that ties the chain's fixed end to the frame, and the brake carabiner.*

### 3.12 Carabiners, descender and rope (bought)

- Three aluminium screw-gate locking carabiners, EN 362 class B or equal, 25 kN along the long axis: one for the load eye, one for the brake turn in the spare eye and one as the victim connector.
- One auto-locking rope descender with an anti-panic function, made for 10.5 to 11.5 mm rope and rated for a one-person rescue load (EN 341 class A or EN 12841 type C, or equal). Read and follow its maker's instructions for reeving and use.
- 30 m of 11 mm semi-static kernmantle rope, EN 1891 type A or equal. Tie a figure-eight loop at one end (the victim end), dressed, with a 100 mm tail, and a stopper knot at the other end.

The load carabiner hangs in the load eye with the descender on it. The rope's victim end leaves the bottom of the descender; the brake strand leaves its side, turns 180 deg over the brake carabiner in the spare eye and runs down (Figure 17).

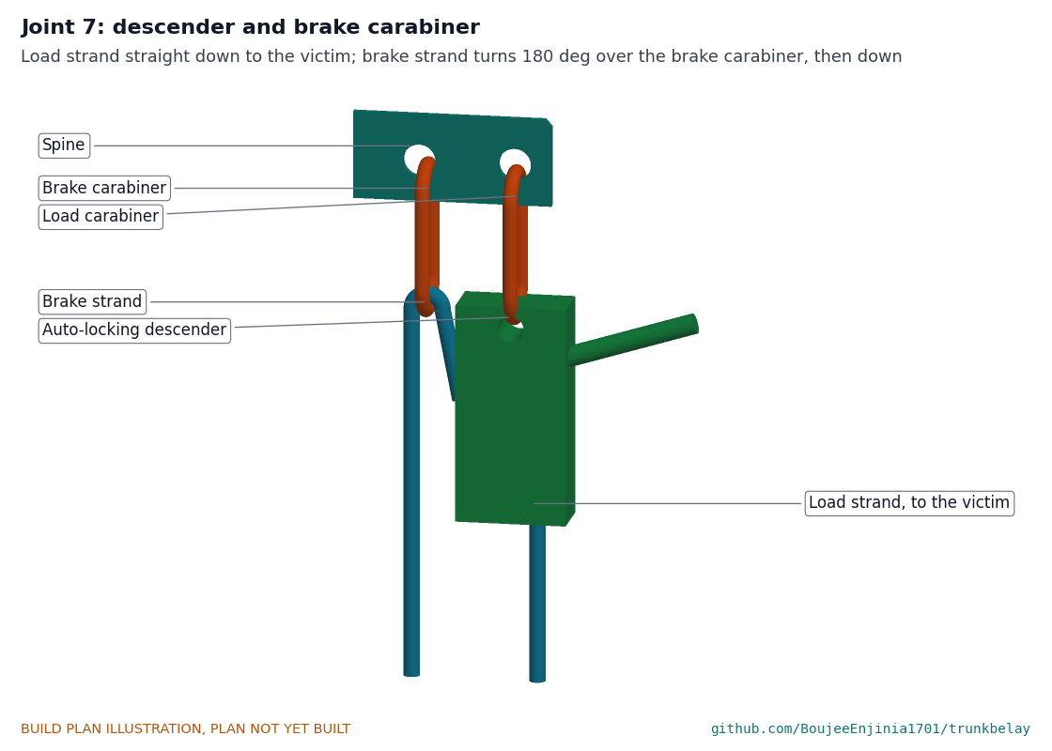
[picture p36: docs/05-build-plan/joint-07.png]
Figure 17. Descender, brake carabiner and rope


*Figure 17. Joint 7: the load strand runs straight down to the victim; the brake strand turns over the brake carabiner and runs down to the bag on the ground.*

### 3.13 Evacuation triangle, chest sling and bag (bought)

- One evacuation triangle, EN 1498 class B or equal.
- One 120 cm sewn sling, 22 kN, used as the chest sling.
- One 35 l rope bag with shoulder straps and a clip loop.

### 3.14 Tag line and micro pulley (bought)

- 55 m of 4 mm polyester accessory cord, both ends sealed with a hot knife. Tie a small figure-eight loop in one end (the bag end).
- One micro pulley for 4 to 8 mm cord, on a small screw-gate carabiner.

The pulley clips to the rescuer's harness. The cord runs through it, and both ends stay on the ground: one tied to the bag's clip loop, the other in the helpers' hands. As the rescuer climbs, the two legs of cord grow; at the top the helpers pull their end and the bag rises to the rescuer (Figure 28).

## 4. Putting it together

Assemble at the bench with the frame on a 300 mm wooden post standing upright in a vice or post holder. In each picture the parts already fitted are grey and the part being fitted is in colour, with an arrow showing the way it goes on.

### Step 1: weld the bearing bars to the spine

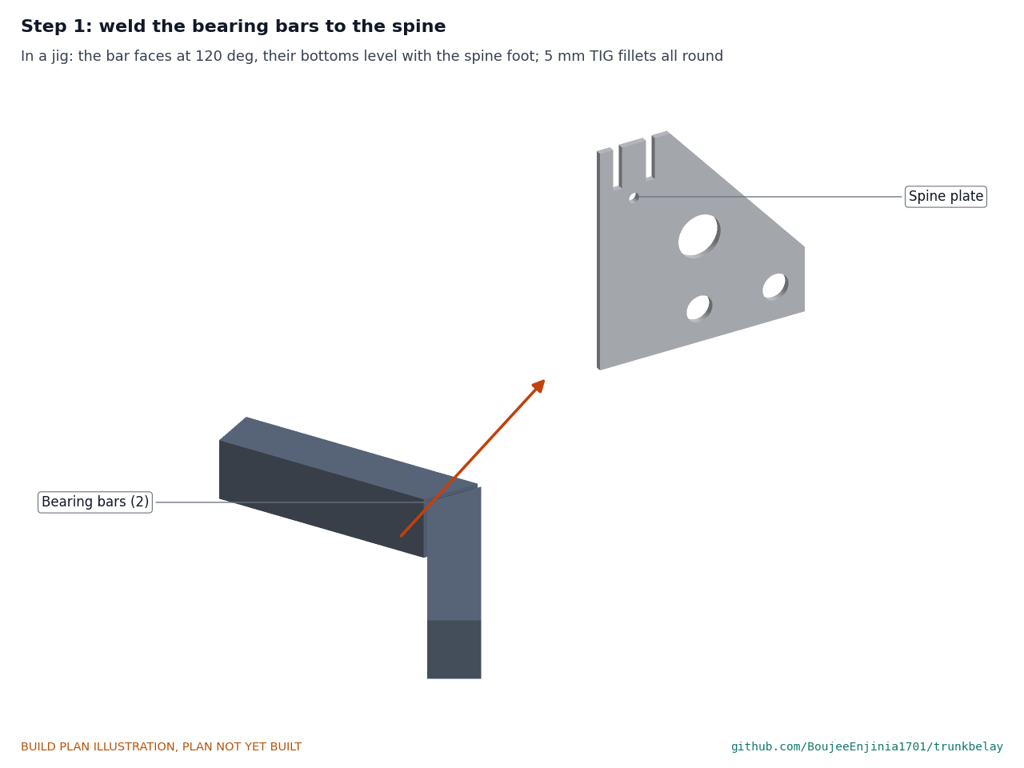
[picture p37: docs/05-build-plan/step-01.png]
Figure 18. Step 1


*Figure 18. Step 1: bearing bars to the spine foot.*

Clamp the spine upright in the jig and the two bars against its faces, front faces at 120 deg and bottoms level with the spine. Tack, check the angle, then TIG weld all round each bar end with 5 mm fillets.

### Step 2: weld the eye rings

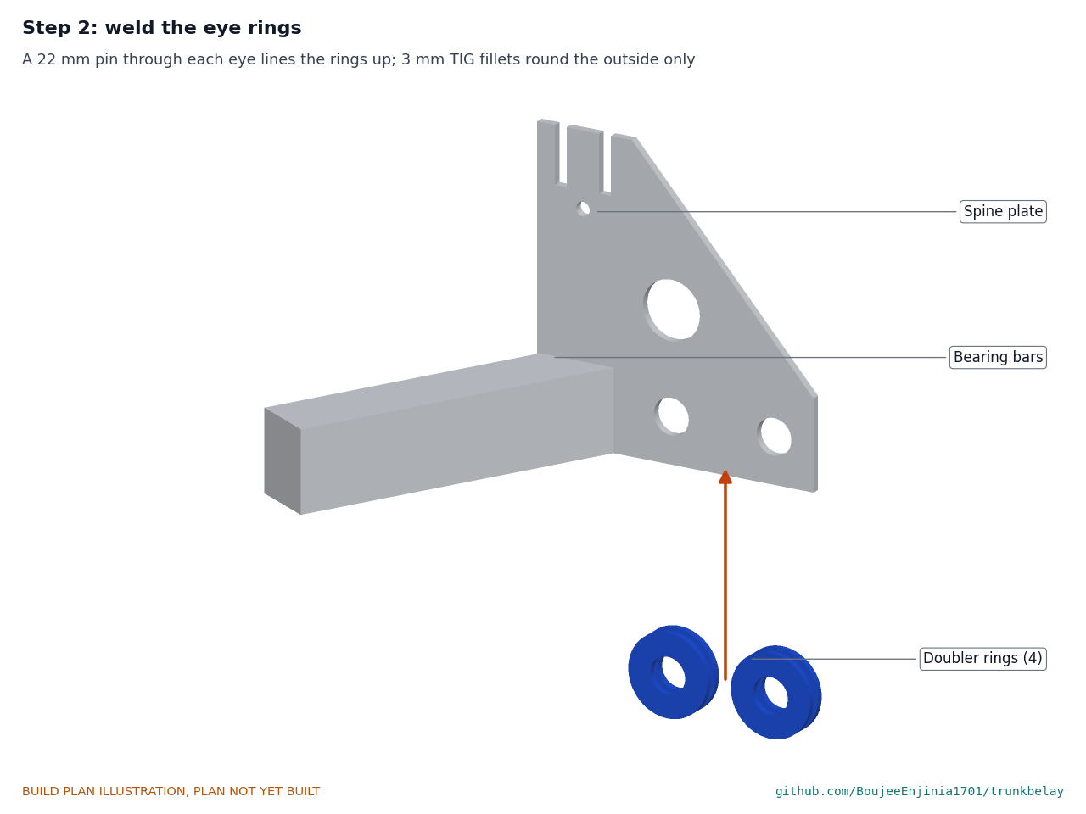
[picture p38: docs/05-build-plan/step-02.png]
Figure 19. Step 2


*Figure 19. Step 2: four doubler rings, two at each eye.*

Line the rings up on a 22 mm pin through each eye and TIG weld round the outside with 3 mm fillets.

### Step 3: weld the cheeks, drill the pin hole, set the rivet nuts

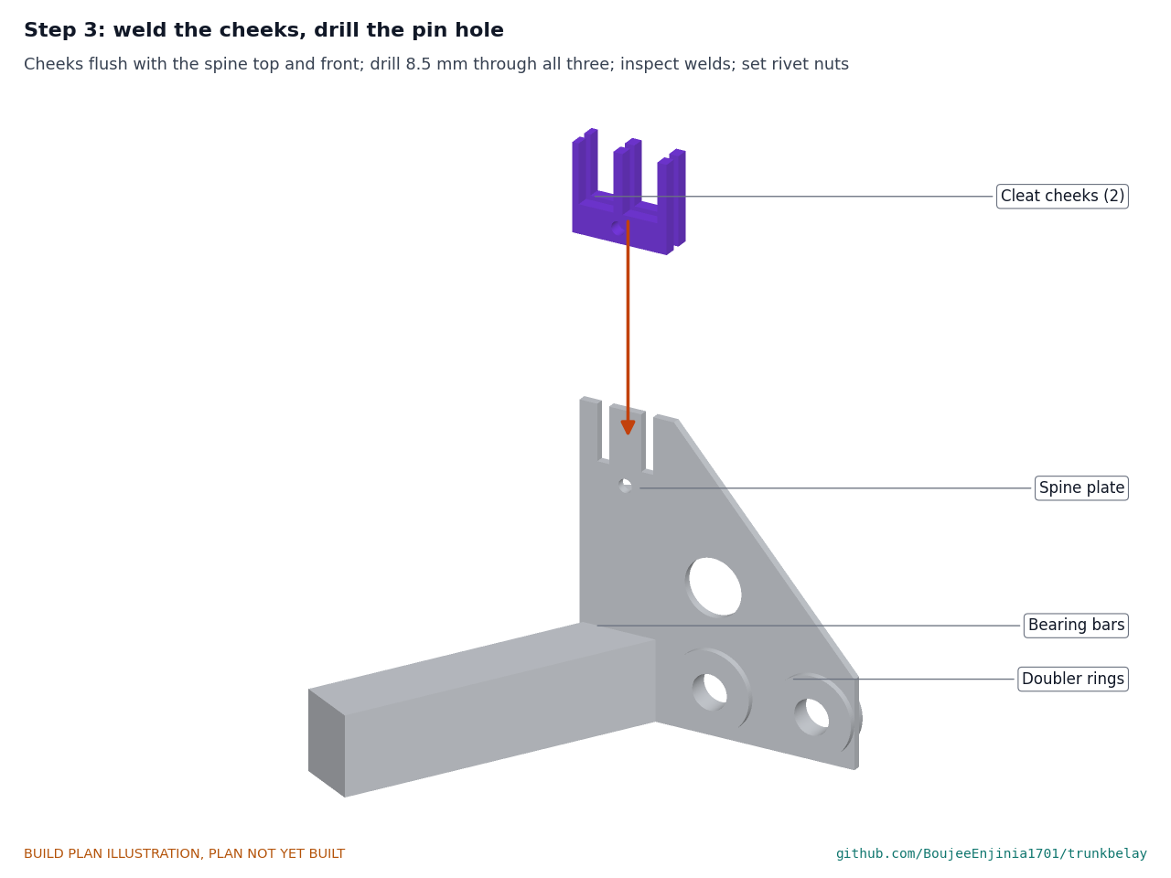
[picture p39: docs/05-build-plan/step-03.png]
Figure 20. Step 3


*Figure 20. Step 3: cheeks on both faces of the spine top.*

Weld the cheeks flush with the spine top and front edge, drill the 8.5 pin hole through all three plates, clean up (section 3.5) and set the four rivet nuts in the bar faces (section 3.3). **Hold point:** inspect the welds and clear the slots and pin hole before going on.

### Step 4: bond and screw the pads

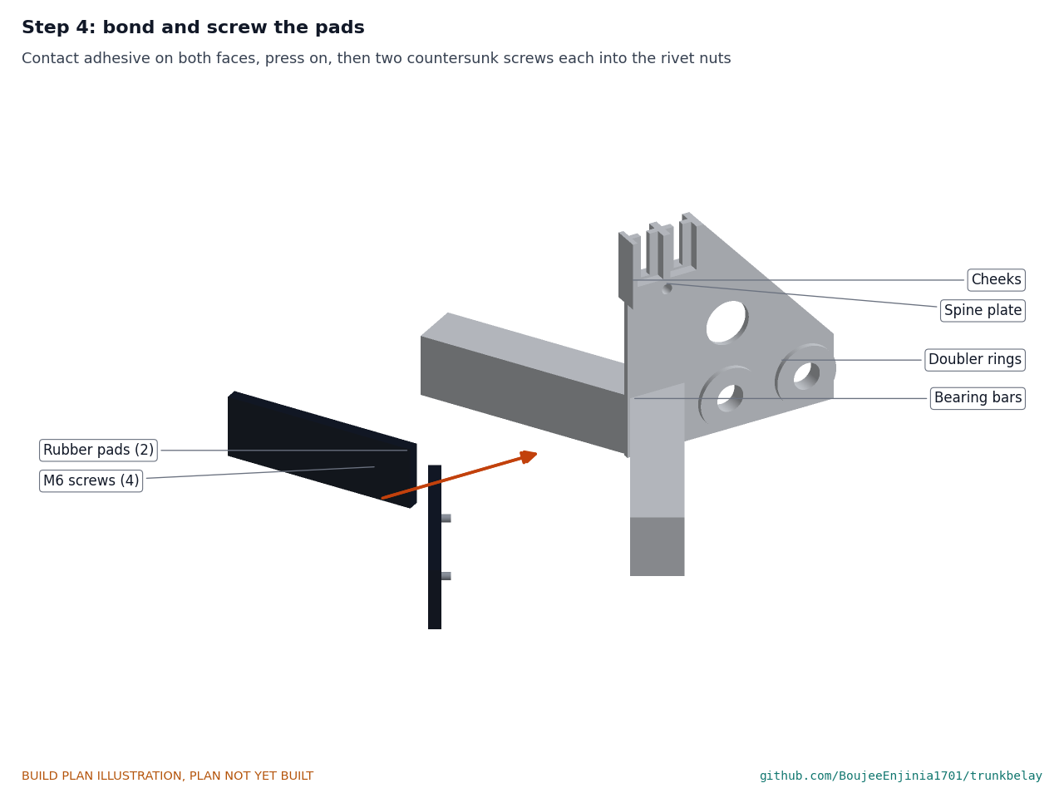
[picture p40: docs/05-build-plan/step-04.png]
Figure 21. Step 4


*Figure 21. Step 4: a rubber pad on each bar's front face.*

Bond each pad with contact adhesive, then fit its two countersunk screws into the rivet nuts. Leave the adhesive 24 hours before any load.

### Step 5: fit the fixed end and its tether

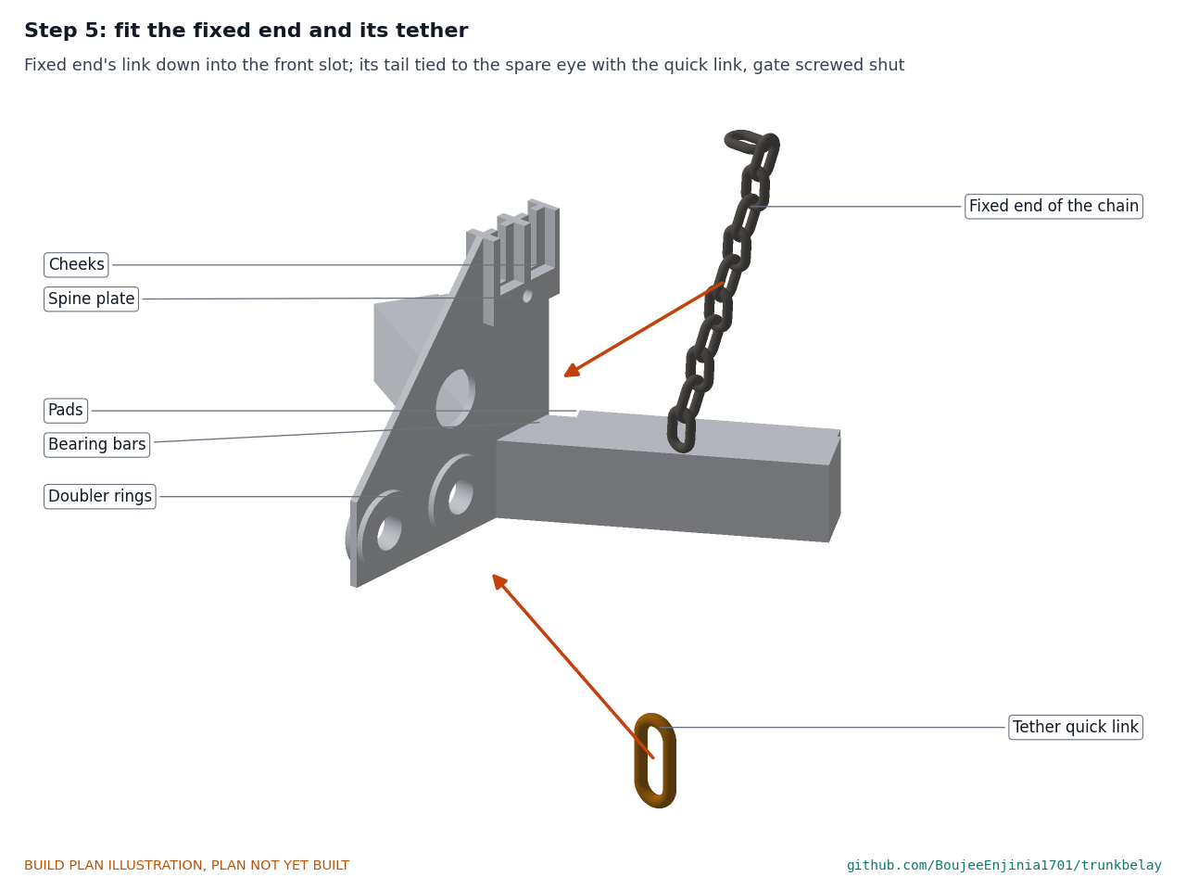
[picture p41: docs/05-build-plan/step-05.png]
Figure 22. Step 5


*Figure 22. Step 5: the chain's fixed end in the front slot, its tail tied to the spare eye.*

Drop the fixed end's plain link into the front slot from above so it stands upright. The tail's first link lies flat inside the notch on the spine's left-hand face (seen from the trunk); the long run of chain leaves from the right-hand face. Lead the tail down to the spare eye and close the quick link through the spare eye and the tail's last link.

### Step 6: wrap the chain round the trunk

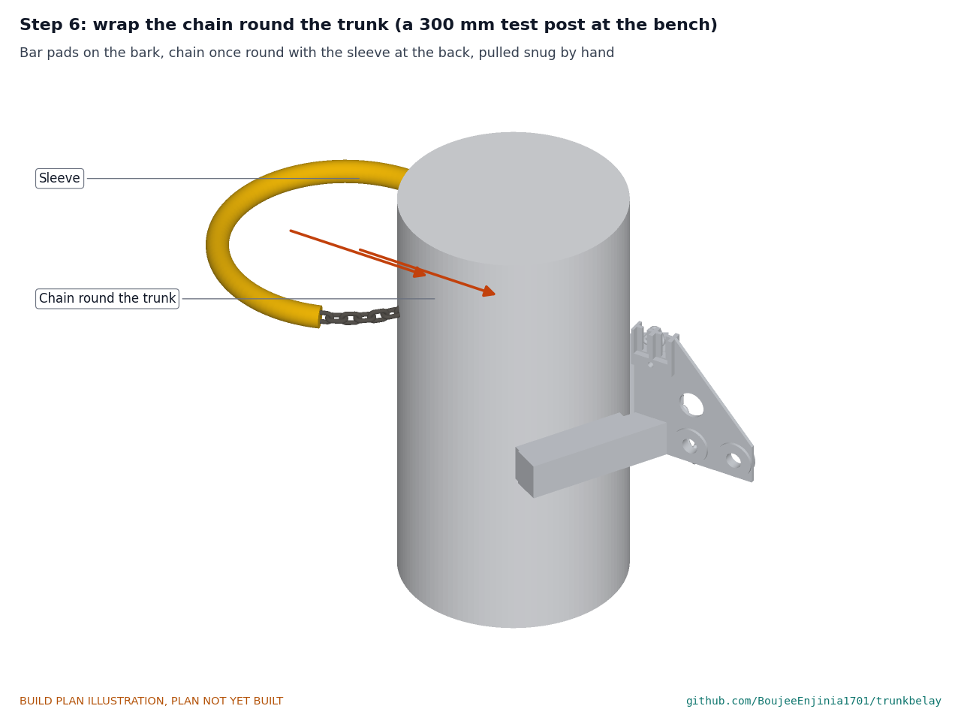
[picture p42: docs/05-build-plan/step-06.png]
Figure 23. Step 6


*Figure 23. Step 6: the chain wrapped once round the post, with the sleeve at the back.*

Hold the frame against the post with both pads on the wood. Pass the chain once round the post, slide the sleeve to the back and pull the chain snug by hand.

### Step 7: drop the adjustable end in, keeper on, pin in

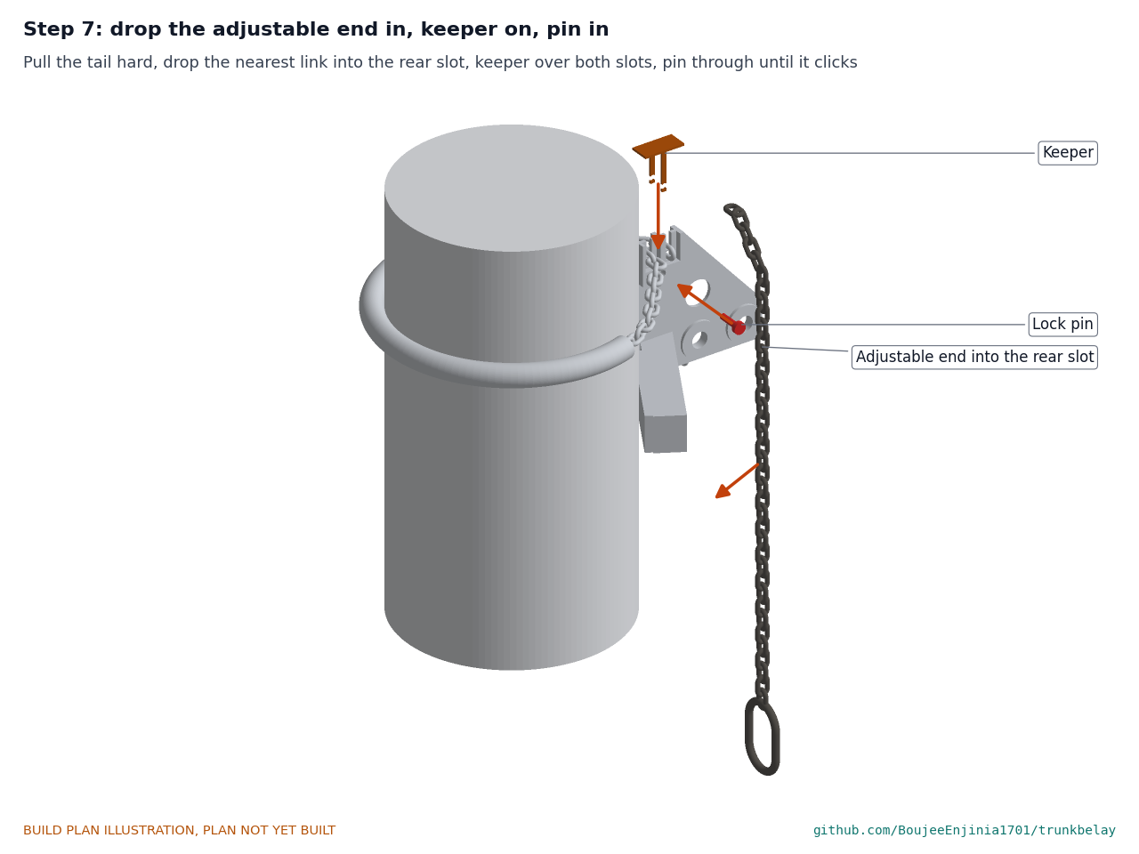
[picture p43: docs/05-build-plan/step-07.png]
Figure 24. Step 7


*Figure 24. Step 7: the nearest link of the adjustable end into the rear slot; keeper over both slots; lock pin in.*

Pull the adjustable end hard, drop the nearest link into the rear slot so it stands upright, slide the keeper on over both slots and push the lock pin through until it clicks. Let the tail hang on the side away from the rope. Figure 25 shows the result from above.

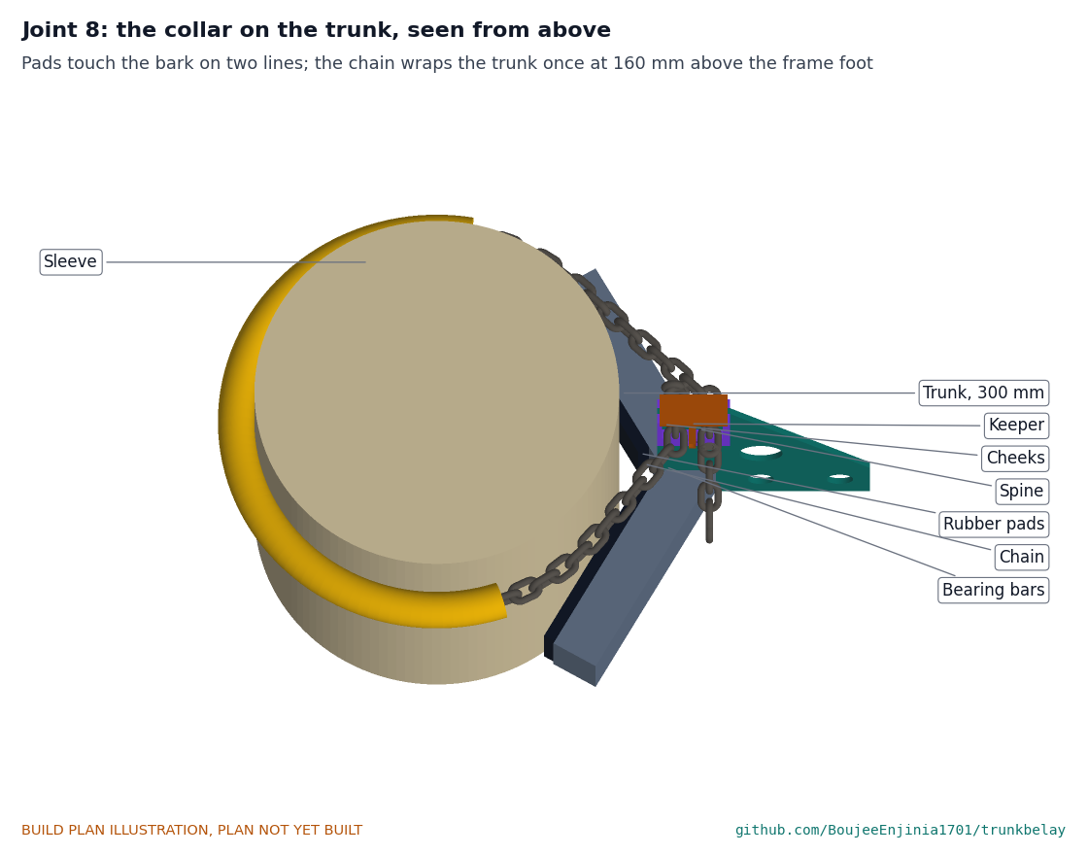
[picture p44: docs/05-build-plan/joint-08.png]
Figure 25. The collar on the trunk, from above


*Figure 25. Joint 8: the collar on the trunk, seen from above. The pads touch on two lines; the chain wraps once.*

### Step 8: clip on the descender

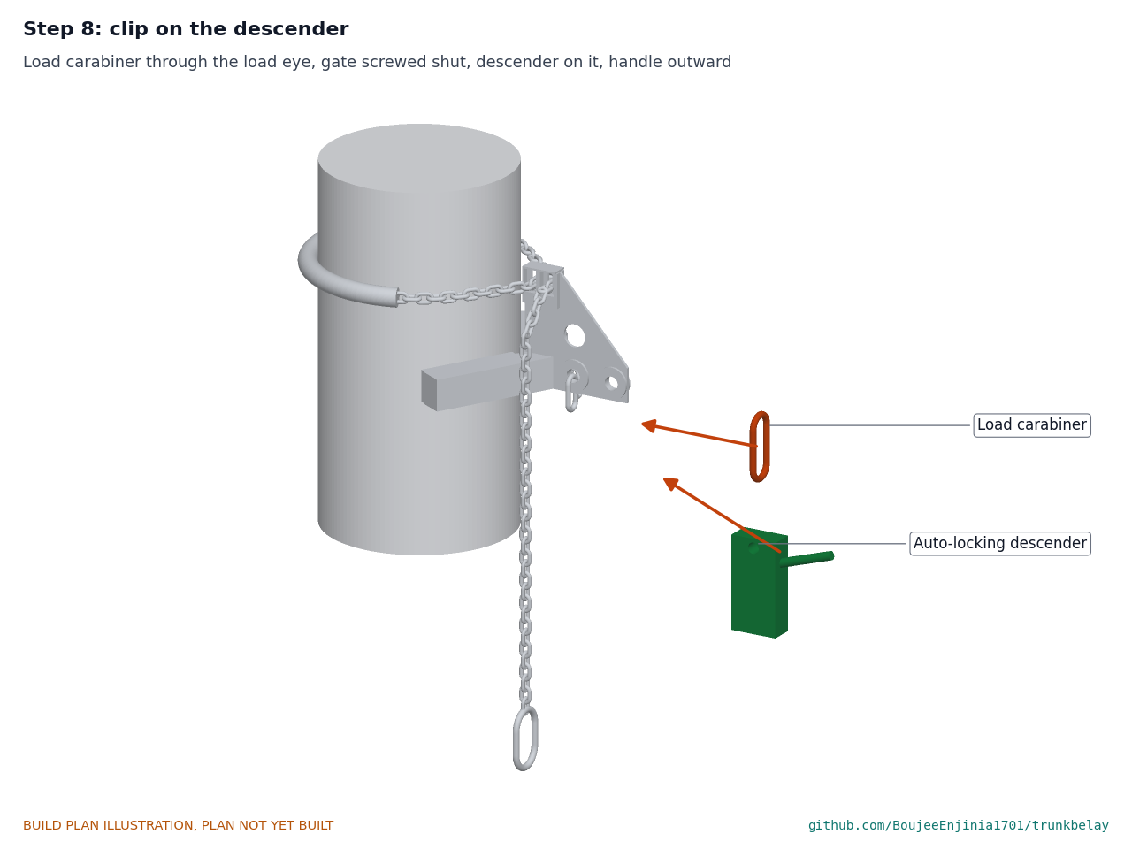
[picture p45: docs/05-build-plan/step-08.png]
Figure 26. Step 8


*Figure 26. Step 8: the load carabiner through the load eye, with the descender on it.*

Clip the load carabiner through the load eye, gate away from the trunk, and screw the gate shut. Hang the descender on it with its handle facing away from the trunk.

### Step 9: reeve the rope and fit the brake carabiner

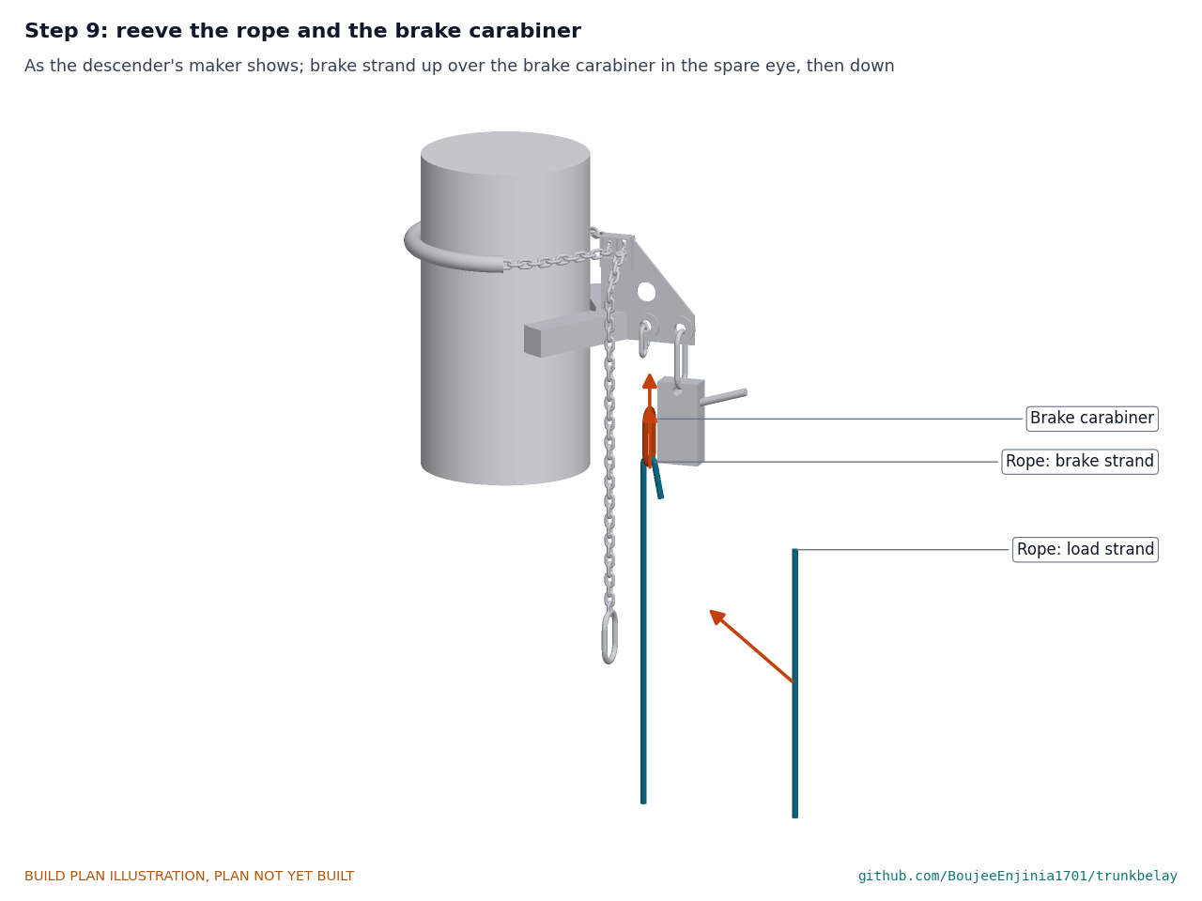
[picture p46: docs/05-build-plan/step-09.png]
Figure 27. Step 9


*Figure 27. Step 9: rope through the descender; brake strand over the brake carabiner in the spare eye.*

Reeve the rope through the descender as its maker shows, with the figure-eight loop on the load side. Clip the brake carabiner into the spare eye beside the quick link and lay the brake strand over it.

### Step 10: make up the pre-rigged victim set and pack

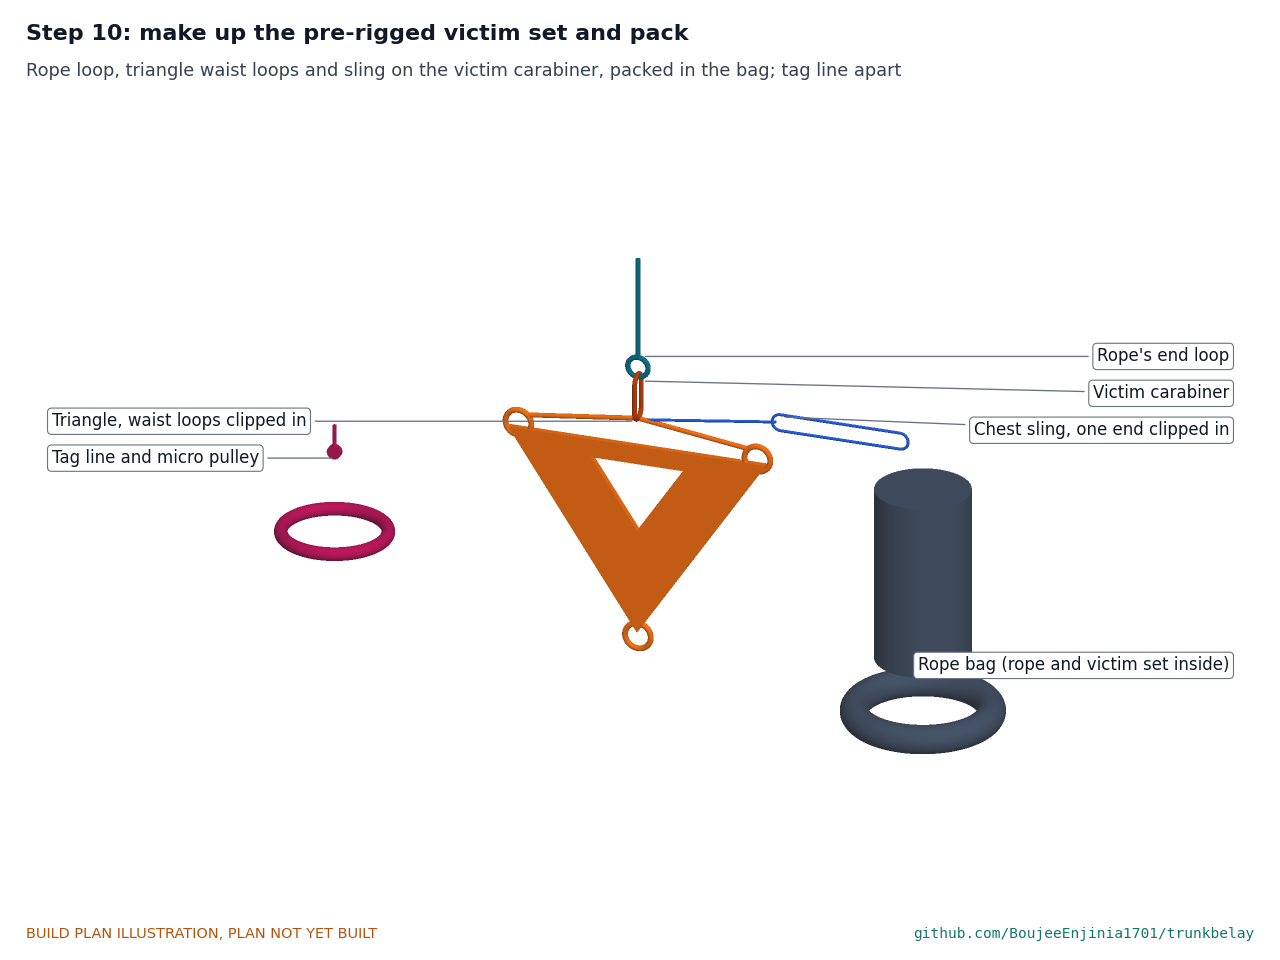
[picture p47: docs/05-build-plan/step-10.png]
Figure 28. Step 10


*Figure 28. Step 10: the pre-rigged victim set (the rope's loop, the triangle's two waist loops and one end of the chest sling on the victim carabiner), the bag they are packed in, and the tag line with its micro pulley.*

Clip the victim carabiner into the rope's figure-eight loop. Clip in the triangle's two waist loops and one end of the chest sling, and screw the gate shut. At height only two clips are left to make: the triangle's crotch loop and the sling's free end. Flake the rope into the bag, victim end on top, then lay the pre-rigged set on top of it, folded so it comes out ready to fit. Tie the tag line's loop to the bag's clip loop. The collar, chain, descender and the load and brake carabiners go on the rescuer's harness; the micro pulley goes on with the tag line through it.

In use, the order at height is: fix the collar; the helpers haul the bag up and the rescuer clips it to the spare eye; reeve the rope; lower the bag on its rope end; fit the triangle and sling; make the last two clips and take in all slack. The collar is always placed at least 300 mm above the point where the rope meets the victim.

## 5. First checks

These are the first checks for the TRL 4 build. The plan lists them; a TRL 4 test report records them.

*Table 2. First checks.*

| Check | Requirement | How | Pass when |
| --- | --- | --- | --- |
| Fit on the range | R3 | Fit the collar to 200, 300 and 450 mm posts or trunks, no tools | Both pads touch, the painted link drops in, keeper and pin go on each time |
| Static hold | R1 | On a cut, wet trunk section in a proof rig, hang 2.5 kN from the load eye for 3 minutes | Slip of 20 mm or less, no damage to frame or chain |
| Upward pull | R2 | Misuse test only: with the collar below a 100 kg test mass, lower the mass past the collar (rig only, no person); in the timed drill, check the rescuer can reach to set the collar at least 300 mm above the attachment | Recorded; if a rescuer cannot reach above the attachment, the double-acting collar (the recorded fallback) is built |
| Rigging time | R4 | Timed drill at 3 m with a dummy, trained climber, the bag hauled on the tag line and the victim set pre-rigged | Collar fixed and dummy clipped in within 5 minutes |
| Lowering | R5 | Lower a 100 kg test mass 10 m, measuring speed and brake hand force | Speed held under 0.5 m/s, hand force under 150 N |
| Rope | R6 | Measure the rope | 30 m, knots tied and dressed |
| Mass | R7 | Weigh what the rescuer carries up (collar, chain, descender, two carabiners, micro pulley and the tag line) and the hauled bag | Carried mass under 5 kg |
| Bark | R8 | Inspect the trunk section after the hold and lowering tests | No cut deeper than 5 mm |
| Drill | R10 | Supervised drill after a half-day session, with the training partner | Each trainee completes it |

## 6. Safety stops

Work stops at each of these points until what is listed is true.

- **S1, after welding:** every weld inspected; no crack, undercut, porosity or missing fillet; no repair weld on a crack; slots and eyes clean and smooth.
- **S2, before any load:** pads bonded for 24 hours; slots, pin hole and eyes clear; chain certificate checked; every carabiner and quick link gate screwed shut.
- **S3, before the proof test:** the proof rig holds the trunk section and the load independently of the collar, and nobody stands under or beside the load.
- **S4, before a person goes near the kit at height:** the collar has held 2.5 kN for 3 minutes on a wet cut trunk section with 20 mm of slip or less, and the frame shows no permanent bend.
- **S5, before any drill with a person:** the drill has been run with a 100 kg dummy at 3 m height, with a separate backup rope on the dummy, and the rescuers have been trained; emergency services are always called first in a real rescue.
- **S6, before every use:** keeper on and pin clicked; the painted link or the right link in the rear slot; all slack taken in before the victim's feet are freed, so the victim never drops onto the collar; the collar at least 300 mm above the point where the rope meets the victim (the collar holds only a downward pull); nobody stands under the bag while it is hauled up.

## 7. Tools, skills and workspace

- **Tools:** profile cutting (bought in), drill press with 6.5, 8, 8.5 and 22 mm bits and a 13 mm counterbore, files and a rotary burr, stainless wire brush, AC TIG welder with ER5356 filler, clamps and a simple angle jig, vice, hot knife, spanners, contact adhesive and spreader, barrier paste, paint marker, letter stamps.
- **Skills:** a welder able to make sound TIG fillets on thin aluminium box section; someone trained in rope rescue to reeve and check the descender, and to run the drills.
- **Workspace:** a fabrication bench with ventilation and screens for TIG welding, and a 300 mm wooden post held upright for assembly and fit checks.

## 8. Where the numbers come from

- Parametric model: `cad/src/model.py` (with its constructability checks) and `cad/step/trunkbelay-assembly.step`.
- General arrangement: `cad/drawings/TKB-DWG-001`; making sketches `cad/drawings/TKB-DWG-101` to `TKB-DWG-109`.
- Calculations: `docs/04-calcs/01-sizing.md` (TKB-CAL-001) and `docs/04-calcs/sizing.py`.
- Bill of materials: `bom/bom.csv`.
- Pictures: `cad/src/build_plan_media.py`.
- Decisions: `docs/decisions/0001-trl2-review-decisions.md`, `docs/decisions/0002-design-for-construction.md`, `docs/decisions/0003-amish-requirement-decisions.md` and `docs/06-design-decisions.md`.

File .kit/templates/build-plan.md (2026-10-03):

---
doc_id: PRJ-BLD-001
title: Project prototype build plan
project: Project name
doc_type: Build plan
version: "0.1"
status: Draft
date: YYYY-MM-DD
author: Amish Chadha
license: CERN-OHL-S-2.0
revisions:
  - version: "0.1"
    date: YYYY-MM-DD
    author: Amish Chadha
    change: First build plan; design made constructable
---

# Project prototype build plan

**Plan, not yet built.** How to build the first proof-of-concept prototype, component by component. Building and testing to it is TRL 4 work. Decisions still to be made are kept in the design decisions register (`docs/06-design-decisions.md`), not here.

## 1. What you are building

Every component, pulled apart and numbered in build order

One short paragraph: what the prototype is, how many components, which are made and which are bought, and the main ways they are made.

## 2. What changed to make it buildable

| Component | The concept had | The buildable design has | Why |
| --- | --- | --- | --- |

## 3. Making the components

### 3.1 Component name

Making sketch

**What it is and what it is made from.**

**How to make it.**

1. Mark out ...
2. Cut ...

**How it fits the parts next to it.**

Close-up of the joint

**Check before moving on.**

## 4. Putting it together

### Step 1: ...

Step 1

## 5. First checks

| Check | Requirement | How | Pass when |
| --- | --- | --- | --- |

## 6. Safety stops

## 7. Tools, skills and workspace

## 8. Where the numbers come from

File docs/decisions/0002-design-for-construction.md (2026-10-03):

---
doc_id: TKB-DDR-002
title: TrunkBelay design for construction
project: TrunkBelay
doc_type: Design decision record
version: "0.1"
status: Draft
date: '2026-10-03'
author: Amish Chadha
license: CERN-OHL-S-2.0
revisions:
- version: "0.1"
  date: '2026-10-03'
  author: Amish Chadha
  change: Concept made constructable; changes C1 to C11 and assumptions A1 to A6 decided under Amish's 2026-10-03 pre-approvals
---

# 0002: Design for construction

- **Date:** 2026-10-03
- **Status:** decided. Decided by Amish under his pre-approval of 2026-10-03: "start with the first 14 repos from the list of 29 projects. I pre-approve the batch runs along with any recommendations you come up with. I also accept any cost overruns or variations from the assumed scope cost." and his instruction of the same day: "Proceed with the remaining 15 scaffolds". Design-for-construction rule, Amish, 2026-09-30: "fix the design assumptions to match and be physically feasible."

## Context

The TRL 2 concept (TKB-DDR-001) named the parts but not how each is made or joined: a "chain collar", a "slotted cleat", a "padded bearing plate" and a friction device "on the collar". STANDARDS section 18 requires every part to be makeable by a stated process and to fit and fasten to its neighbours. The parametric model (`cad/src/model.py`) was built part by part, and its 210 constructability checks (contact, clearance, the trunk, the chain in its slots and the pad contact point, each on 200, 300 and 450 mm trunks) all pass. None of the changes alters what the kit does, its pitch or its safety case; each is the simplest physically sound way to make a concept part.

## Changes

*Table 1. Changes from the concept to the constructable design.*

| # | Component | The concept had | The constructable design has | Why |
| --- | --- | --- | --- | --- |
| C1 | Bark bearing | A padded curved plate | Two 50 x 25 x 2.5 mm steel box bars in a 120 deg V, each faced with a 10 mm rubber pad, bonded and held by two countersunk M6 screws | Fits 200 to 450 mm trunks; a box bar carries the pad force with a factor of 2.1 on yield at 2.5 kN (TKB-CAL-001, C1) |
| C2 | Frame | Not defined | One 5 mm steel spine plate carrying the bars at its foot, the chain slots at its top and two eyes at its outer end | One plate ties every load together; 5 mm because a 6 mm chain link must span the web |
| C3 | Cleat | A slotted cleat | Two 7.5 mm slots cut in the spine top, with a 6 mm cheek welded on each face, notched round each slot | The chain pulls across the plate; the cheeks stop the thin top twisting (C4 factor 3.1 and 3.8) and the notches let the links bear on the web |
| C4 | Lock | Not defined | A keeper bent from 3 mm sheet, its bridge over both slot mouths, held by an 8 mm ball-lock pin through its legs, the cheeks and the web | A link cannot lift out of its slot; one pin to check |
| C5 | Fixed chain end | Not defined | Also in a slot (the front one), its tail tied to the spare eye with an 8 mm quick link | The chain can be adjusted from either end and cannot be dropped when the keeper is off |
| C6 | Eyes | "On the collar" | Two 22 mm eyes with a 4 mm doubler ring welded each side, edges rounded: 13 mm of rounded steel under a carabiner | A carabiner must never bear on a thin plate edge |
| C7 | Lever | Not defined | The load eye 150 mm out from the spine's front edge; the chain line 160 mm above the frame foot | Gives a locking factor of 1.54 or more on every trunk (TKB-CAL-001, B4) |
| C8 | Chain | "Short length of alloy chain" | 6 mm grade 80, 110 links, master link and connecting link on the adjustable end; painted links mark the slot link for 200, 300 and 450 mm trunks | Fits the full trunk range with at least 10 links of tail; factor 8.1 on breaking force |
| C9 | Chain padding | The plate "stops the chain biting in" | 600 mm of 50 mm tubular webbing on the chain at the back of the trunk | Spreads the chain's pressure where it is highest (0.6 MPa at 2.5 kN) |
| C10 | Brake | A friction device | Auto-locking descender on the load eye, brake strand turned 180 deg over a carabiner in the spare eye | Brings the hand force from about 150 N to about 80 N (TKB-CAL-001, D1) |
| C11 | Finish | Not defined | Frame hot-dip galvanised after welding, vent holes in the bars, slots and pin hole cleared afterwards; load and one-person marking stamped on the spine | Rust-proof in the open in a monsoon climate |

## Assumptions decided

*Table 2. Assumptions behind the constructable design.*

| # | Assumption | Value | Relaxed or tightened by |
| --- | --- | --- | --- |
| A1 | Friction on wet coconut bark | Rubber pad 0.5, webbing-sleeved chain 0.4, together 0.9 | Slip tests on cut trunk sections at TRL 4; the design needs 0.58 on a 200 mm trunk |
| A2 | Pad rubber | 60 to 70 Shore A, effective compression modulus 6 MPa | The rubber bought |
| A3 | Descender | Rope friction 0.2 over 540 deg of contact, ratio 6.6 | The maker's data for the descender bought |
| A4 | Rope stretch | 4 % between 50 and 150 kg (EN 1891 type A class) | The rope bought |
| A5 | Bark | No cut at 2 MPa under rubber or 0.6 MPa under webbing; bare links may mark it | Inspection after the TRL 4 tests (R8) |
| A6 | Trunk range | 200 to 450 mm, round enough for a V to touch on two lines | A survey of palms with the first co-design candidate |

## Consequences

- Every part is cut, drilled, bent or welded from plate, box section and sheet, or bought; the frame is one welded, galvanised piece of about 2.3 kg of steel.
- The collar (frame and chain set) weighs 4.4 kg and the kit 8.9 kg; the kit mass is open in TKB-DEC-001, O3.
- The general arrangement TKB-DWG-001, the making sketches TKB-DWG-101 to 109 and the build plan TKB-BLD-001 show this design.

> **Safety:** These changes make the collar buildable; they do not make it safe to use on a person. The build plan's safety stops require a proof test of the collar at 2.5 kN on cut trunk sections and a dummy drill at low height before anyone is lowered with it.

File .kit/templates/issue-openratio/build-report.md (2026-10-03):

---
name: Build report
about: Tell us what happened when you built, printed or tested part of this design
title: "Build report: "
labels: build-report
---

This is a research and educational prototype, not a medical device. It is a TRL 3 concept and is not released for fabrication. If you build any part of it, you do so at your own risk. Reports help everyone.

**What you built** (part, sub-assembly or test)

**Materials, tools and settings**

**What worked**

**What did not work, with photos or measurements if you have them**

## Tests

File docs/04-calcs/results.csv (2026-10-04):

tag | result | value | unit
A1 | Working load on the collar with a 100 kg person held: 0.99 kN; R1 static load 2.5 kN (2.5 times the working load) | 0.9911 | kN
A2 | Peak load if the person drops onto the rope when the feet are freed (rigid body, 1 m of rope): 30 mm slack 2.6 kN, 50 mm slack 2.9 kN, 100 mm slack 3.4 kN; the drill takes all slack in first, so the drop stays under 30 mm and the peak (about 2.6 kN) close to the R1 load, inside the strength margins of section C | 2.562 | kN
B1 | 200 mm trunk: load line 273 mm from the trunk axis, lever height 160 mm, friction needed 0.58 against 0.9 assumed, locking factor 1.54; at 2.5 kN the bars press 4.3 kN (2.5 kN a pad) and the chain carries 3.3 kN | 1.539
B2 | 300 mm trunk: load line 331 mm from the trunk axis, lever height 160 mm, friction needed 0.48 against 0.9 assumed, locking factor 1.86; at 2.5 kN the bars press 5.2 kN (3.0 kN a pad) and the chain carries 4.2 kN | 1.864
B3 | 450 mm trunk: load line 418 mm from the trunk axis, lever height 160 mm, friction needed 0.38 against 0.9 assumed, locking factor 2.35; at 2.5 kN the bars press 6.5 kN (3.8 kN a pad) and the chain carries 5.5 kN | 2.351
B4 | Smallest locking factor 1.54 (200 mm trunk); the grip rises in step with the load, so the factor is the same at any load. Friction from the chain's full wrap round the trunk is extra and not counted | 1.539
B5 | Settling at 2.5 kN: pads squash 3.1 mm at 1.9 MPa, chain seats 2.9 mm; the frame drops about 10 mm as it cocks (R1 allows 20 mm of slip) | 10.27 | mm
C1 | Bearing bar (aluminium RHS 50 x 40 x 3): 0.48 kN m at the spine, 78 MPa, factor 1.60 on the welded (HAZ) proof strength at the R1 load (4.0 at the working load) and 2.4 on the HAZ ultimate strength | 1.599
C2 | Bar to spine fillet welds (5 mm, all round, ER5356): 40 MPa against 210 MPa weld metal strength, factor 5.3 | 5.269
C3 | Spine arm: 7 MPa in bending beside the lightening hole; load eye 13 mm thick with doublers, bearing 19 MPa under the carabiner bar, tear-out strength 39 kN (16 times the R1 load) | 15.54
C4 | Chain cleat at 5.5 kN chain tension: web ligament beside a slot, 35 mm deep, 81 MPa (factor 1.55 on HAZ proof); twist between the two slots 0.16 kN m, 35 MPa in the top with 8 mm cheeks (factor 2.0); the steel links bear on the aluminium web at about 92 MPa (wear to confirm) | 1.546
C5 | Chain: 5.5 kN at most at the R1 load against a working load limit of 11.2 kN and a minimum breaking force of 45 kN (factor 8.1); 2.2 kN at the working load | 8.109
C6 | Rope: EN 1891 type A, at least 22 kN, about 14 kN at the figure-eight loop: factor 5.7 at the R1 load and 14 at the working load; carabiners 25 kN, factor 10 and 25 | 14.43
D1 | Hand force on the brake strand holding 100 kg: descender ratio 6.6, brake carabiner 1.87, hand 80 N (R5 allows 150 N); without the brake carabiner 150 N | 80.22 | N
D2 | A 25 m lowering at a steady 0.3 m/s takes 83 s and turns 24.8 kJ into heat: 85 % in the descender, 7 % in the brake carabiner, 8 % at the hand; the descender would warm by at most 44 K if it kept it all | 24.76 | kJ
E1 | Rope: 25 m of lowering, 1 m from the descender to the person at the start, 1.5 m for the figure-eight loop and stopper knot, 0.5 m round the brake carabiner: 28.0 m of the 30 m | 28 | m
E2 | Fit: 200 mm trunk: loop 769 mm (43 links), bars touch the trunk 58 mm along the pad, spine 23 mm clear of the bark; 300 mm trunk: loop 1086 mm (61 links), bars touch the trunk 87 mm along the pad, spine 31 mm clear of the bark; 450 mm trunk: loop 1563 mm (87 links), bars touch the trunk 130 mm along the pad, spine 43 mm clear of the bark; the 110-link chain leaves at least 10 links of tail on a 450 mm trunk
E3 | Rigging time once the rescuer is in position (estimate): Clip the frame to the trunk with the chain round it, link into slot, keeper and pin on 60 s; Helpers haul the rope bag up on the tag line through the micro pulley on the rescuer's harness; the rescuer clips it to the spare eye 45 s; Clip the descender to the load eye and reeve the rope; brake strand over the brake carabiner 40 s; Lower the bag on its rope end to the ground (helpers take the brake strand slack) 20 s; Fit the pre-rigged evacuation triangle round the hips and the chest sling (waist loops, sling and rope loop already on the victim carabiner) 90 s; Clip the crotch loop and the chest sling's free end into the victim carabiner and take in all slack 15 s; total 4.5 min | 4.5 | min
F1 | Mass: collar frame 1.31 kg (aluminium weldment 0.97 kg), chain set 1.88 kg, descender 0.53 kg, carabiners 0.26 kg, rope 2.34 kg, triangle and sling 0.87 kg, bag 0.45 kg, tag line 0.60 kg (55 m of 4 mm cord) and micro pulley 0.05 kg | 8.295 | kg
F2 | Whole kit 8.3 kg; the helpers haul 3.7 kg up in the bag (rope, pre-rigged victim set with its carabiner, bag), so the rescuer carries 4.55 kg up the trunk: collar, chain set, descender, load and brake carabiners, micro pulley and the tag line hanging from it (R7 asks for under 5 kg) | 4.55 | kg
F3 | The aluminium weldment saves about 1.9 kg against the same parts in steel; the tag line counts its full 55 m because both legs hang from the rescuer at the top | 4.55 | kg
G1 | Bark pressure at the R1 load: pads 1.9 MPa (0.7 MPa working), sleeved chain 0.58 MPa, bare chain links 8 MPa on a 3 mm line; the outer coconut stem is far stronger in crushing, so no cut is expected under the pads or the sleeve. Bare links outside the sleeve may mark the bark (to confirm by test) | 1.885 | MPa
H1 | Kit cost from the BOM: USD 824. Value-engineering target: USD 900. Estimated cost of the constructable design: USD 824 (USD 76 under the target) | 823.9 | USD
H2 | R9 per-kit parts cost at single-kit prices: USD 824 against the restated R9 target of USD 850 (USD 26 under); the largest lines are auto-locking rope descender with anti-panic function USD 280, evacuation triangle USD 140, lowering rope USD 105, tig welding USD 45; group purchase by the training partner and one kit per climber group are not counted | 823.9 | USD
R | R1: Met on paper (friction to confirm). Locking factor 1.54 at the smallest trunk; settles about 10 mm
R | R2: At risk for an upward pull; drill rule kept (decision 16A). The single top chain cannot hold an upward pull; the drill keeps the collar at least 300 mm above the person's attachment; double-acting collar is the recorded fallback
R | R3: Met. Chain and V fit 200 to 450 mm trunks with no tools
R | R4: At risk (estimate). About 4.5 min once in position: the pre-rigged victim set saves 45 s and the tag-line haul adds 45 s
R | R5: Met on paper (estimate). Hand force about 80 N with the brake carabiner
R | R6: Met. 30 m rope, 28.0 m needed
R | R7: Met on paper. 4.55 kg carried up the trunk; the 3.7 kg bag is hauled up by the helpers
R | R8: Met on paper (to confirm). Pads 1.9 MPa, sleeve 0.58 MPa at the R1 load
R | R9: Met on paper (restated target). USD 824 a kit at single-kit prices against USD 850
R | R10: Cannot be shown on paper. Needs the training trial at TRL 4

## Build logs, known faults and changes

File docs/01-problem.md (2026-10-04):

---
doc_id: TKB-PRB-001
title: TrunkBelay problem statement
project: TrunkBelay
doc_type: Problem statement
version: "0.3"
status: Draft
date: '2026-10-03'
author: Amish Chadha
license: CERN-OHL-S-2.0
revisions:
- version: "0.1"
  date: '2026-09-30'
  author: Amish Chadha
  change: Initial scaffold
- version: "0.2"
  date: '2026-10-03'
  author: Amish Chadha
  change: TRL 2 and 3 update; constraints restated with the value-engineering target, open questions answered, first co-design candidates, safety section
- version: "0.3"
  date: '2026-10-03'
  author: Amish Chadha
  change: Cost and carry constraints updated for Amish's decisions 18C and 19A (TKB-DDR-003)
---

# TrunkBelay problem statement

When a climber is stranded on a palm, the first person able to help is usually another climber, not a fire crew. That person can reach the victim but has nothing to anchor them to and no way to lower them.

## The problem

The reported rescues follow a pattern. A climber blacks out or slips, the climbing device holds the feet, and the person hangs head down. A bystander or fellow climber goes up and improvises with cloth and rope to stop a fall ([Onmanorama, 2025](https://www.onmanorama.com/news/kerala/2025/10/02/coconut-plucker-hanging-upside-down-rescued-by-friend-firefighters.html); [Onmanorama, 2026](https://www.onmanorama.com/news/kerala/2026/01/31/coconut-tree-man-trapped-fire-rescue.html)). Fire crews then arrive, use ladders and rescue nets, and in some cases an officer climbs the trunk directly ([Onmanorama, 2026](https://www.onmanorama.com/news/kerala/2026/02/08/fire-officials-save-60-year-old-man-hanging-upside-down-coco.html)). Each rescue is improvised on the spot.

Utility workers have purpose-built answers. The Buckingham SuperSqueeze is a pole-top rescue strap with an adjustable web grab, rated to 350 lb and sold at about USD 1,576 ([Buckingham](https://buckinghammfg.com/products/supersqueeze-pole-top-rescue-488p/)). The 3M DBI-SALA Cynch-Lok grips a wooden pole with a cleated plate and carabiner and is rated to 310 lb for poles from 5.5 to 18.5 in diameter ([Saftgard](https://www.saftgard.com/products/3m-dbi-sala-1204075-cynch-lok-pole-climbing-device-1204075/)). These are sized for smooth utility poles, priced for utilities and not designed for the fibrous, tapering and often curved trunk of a coconut palm.

## Users and context

| User | Need | Context |
| --- | --- | --- |
| Coconut climbers (the rescuer) | Anchor and lower a stranded colleague quickly and safely | Plantations and home gardens, often working in pairs or small groups |
| The stranded climber | Be supported, freed from the climbing device and lowered without a fall | Head down or slumped, possibly unconscious, 6 to 25 m up |
| Fire and rescue services | A light anchor to secure a victim before ladders or nets are set | Rural stations called to palm rescues |
| Coconut Development Board and climber training schemes | A standard kit and drill to teach | Climber training and insurance programmes |

## Operating environment

- Coconut palm trunks roughly 200 to 450 mm (8 to 18 in) diameter (estimate, to be surveyed), fibrous, often wet, sometimes curved or leaning.
- Working heights from about 6 m to 25 m (20 to 82 ft).
- Hot humid climate, monsoon rain; kit stored in the open or in a shed.
- Rescuer is already on the trunk using a mechanical climbing device or traditional rope loop.
- No anchor points other than the trunk itself.

## Constraints

- Value-engineering target: USD 900 for the first prototype kit (a control target for value engineering, not a spending limit; STANDARDS section 18).
- Kit parts cost target under USD 850 per kit at single-kit prices (R9), restated by Amish on 2026-10-03 from USD 100 so that the auto-locking descender and the evacuation triangle are kept; group purchase by the training partner and one kit per climber group are to bring the cost per climber down.
- Carried up the trunk by one climber: under 5 kg (11 lb) (target); the rope bag may be hauled up by the helpers on a tag line (decision 18C).
- Collar must fit the full trunk range without special tools.
- Must not use the ratcheting cinch geometry of the 3M Cynch-Lok (IP screen design-around).
- Open hardware under CERN-OHL-S-2.0.

## Out of scope

- Replacing or redesigning climbing devices.
- Fall arrest for routine climbing (a separate problem).
- Rescue of a climber who has already fallen.
- Medical care beyond getting the person to the ground.

## Prior work

| Prior work | What it does | Gap for these users | Source |
| --- | --- | --- | --- |
| Buckingham SuperSqueeze pole-top rescue (488P) | Adjustable web-grab strap for lowering an injured lineman from a utility pole | Priced for utilities (about USD 1,576) and sized for smooth poles, not fibrous palm trunks | [link](https://buckinghammfg.com/products/supersqueeze-pole-top-rescue-488p/) |
| 3M DBI-SALA Cynch-Lok pole climbing device | Fall-restriction strap gripping the pole with a cleated plate and carabiner | Fall restriction for the climber, not a rescue anchor; proprietary cinch geometry | [link](https://www.saftgard.com/products/3m-dbi-sala-1204075-cynch-lok-pole-climbing-device-1204075/) |
| CA2681870C, Bashlin pole climbing and fall restraint device (lapsed 2015) | Belt and lanyard with a locking device for pole climbing | Personal restraint, not a rescue anchor | [link](https://patents.google.com/patent/CA2681870C/en) |
| WO2012131439A1, safety tree climbing device (ceased) | Engine-powered wheeled drum that climbs single-stem palms with a brake and safety cable | Climbing machine, not a rescue kit; never entered national phase | [link](https://patents.google.com/patent/WO2012131439A1/en) |
| Fire service improvised rescue with ladders, ropes and nets | Current practice in Kerala palm rescues | Arrives late; relies on ladders that do not reach tall palms | [link](https://www.onmanorama.com/news/kerala/2025/10/02/coconut-plucker-hanging-upside-down-rescued-by-friend-firefighters.html) |

## Co-design

A climber training programme or climbers' collective in Kerala, working with a local Fire and Rescue Services station that has done palm rescues, so the kit and drill fit both the climbers who will use it first and the crews who arrive later.

First candidates to approach (none approached yet; recorded in TKB-DDR-001, D8):

1. A coconut climber training programme run under the Coconut Development Board's "Friends of Coconut Tree" scheme in Kerala, for the drill and the training trial (R10).
2. A Kerala Fire and Rescue Services station in a district with recorded palm rescues (Kasaragod or Kannur), for the drill and for adoption by crews.
3. A climbers' collective or labour bank in the same district, for fit trials on real palms (R3) and the kit's carry and rigging (R4, R7).

## Questions answered at TRL 2 and 3

The open questions of version 0.1 were settled on paper under Amish's pre-approval of 2026-10-03 (TKB-DDR-001). Each answer is checked at TRL 4.

| Question (version 0.1) | Answer on paper | Record |
| --- | --- | --- |
| Can the collar hold the load turning from upward to downward as the victim passes it? | Not with the single top chain. The drill sets the collar at least 300 mm above the point where the rope meets the victim, so the pull is always downward. Whether that drill is workable is a decision for Amish (R2) | TKB-DDR-001, D3; TKB-DEC-001 |
| How much does grip vary with moisture, age and curvature? | The collar is self-locking: it needs a combined friction of 0.58 or less on a 200 mm trunk against about 0.9 assumed for rubber and sleeved chain on wet bark. Friction on real trunks is the first thing to confirm | TKB-CAL-001, section B |
| Which friction device is simplest to learn? | An auto-locking descender with an anti-panic function, plus a carabiner the brake strand turns over. It stops if the rescuer lets go | TKB-DDR-001, D4 |
| How is an unconscious, head-down person fitted with a sling? | An evacuation triangle round the hips and a chest sling, both clipped to the rope's victim carabiner, so the person turns head up when the feet are freed | TKB-DDR-001, D5 |
| Would fire services adopt the kit, and would that change the rating? | Unknown until the first co-design candidates are approached. The rating stays at one person (100 kg design mass, 2.5 kN static) | TKB-DDR-001, D8 |

## Safety

> **Safety:** TrunkBelay is a rope rescue and work-at-height kit. A mistake can drop a person from 6 to 25 m. It is published as an open engineering reference, not certified rescue or fall-protection equipment, and is not used on a person before a proof test of the collar on cut trunk sections and a supervised drill at low height (TRL 4). Emergency services are always called as well. A person who has hung head down for any length of time needs medical assessment after the rescue.

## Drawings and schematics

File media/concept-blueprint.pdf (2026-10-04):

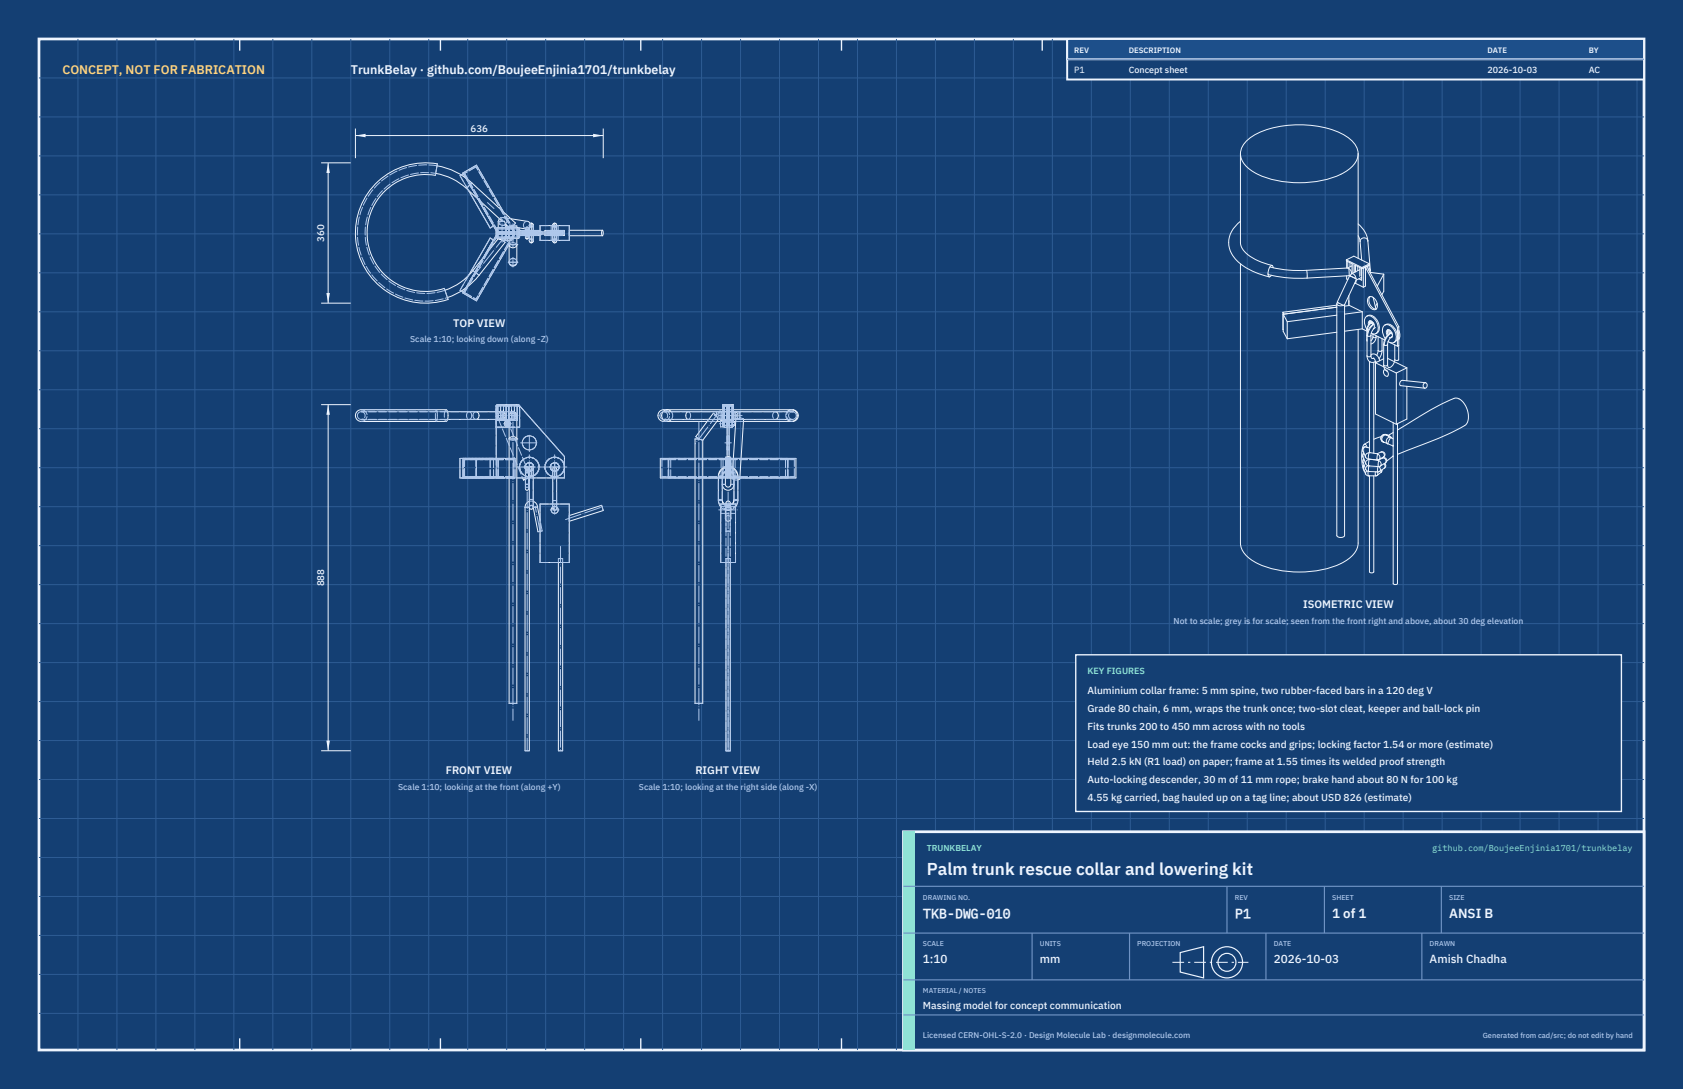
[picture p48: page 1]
CONCEPT, NOT FOR FABRICATION; TrunkBelay · github.com/BoujeeEnjinia1701/trunkbelay; FRONT VIEW; TOP VIEW; RIGHT VIEW; ISOMETRIC VIEW; REV; DESCRIPTION; DATE; Concept sheet; TRUNKBELAY; github.com/BoujeeEnjinia1701/trunkbelay; DRAWING NO. TKB-DWG-010; REV P1; SHEET 1 of 1; SIZE ANSI B; SCALE 1:10; UNITS mm; PROJECTION; DRAWN Amish Chadha; Licensed CERN-OHL-S-2.0 · Design Molecule Lab · designmolecule.com; Generated from cad/src; do not edit by hand

Scale 1:10; looking down (along -Z)

Not to scale; grey is for scale; seen from the front right and above, about 30 deg elevation

KEY FIGURES
Aluminium collar frame: 5 mm spine, two rubber-faced bars in a 120 deg V
Grade 80 chain, 6 mm, wraps the trunk once; two-slot cleat, keeper and ball-lock pin
Fits trunks 200 to 450 mm across with no tools
Load eye 150 mm out: the frame cocks and grips; locking factor 1.54 or more (estimate)
Held 2.5 kN (R1 load) on paper; frame at 1.55 times its welded proof strength
Auto-locking descender, 30 m of 11 mm rope; brake hand about 80 N for 100 kg
4.55 kg carried, bag hauled up on a tag line; about USD 826 (estimate)

Scale 1:10; looking at the front (along +Y)

Scale 1:10; looking at the right side (along -X)

Palm trunk rescue collar and lowering kit

MATERIAL / NOTES
Massing model for concept communication

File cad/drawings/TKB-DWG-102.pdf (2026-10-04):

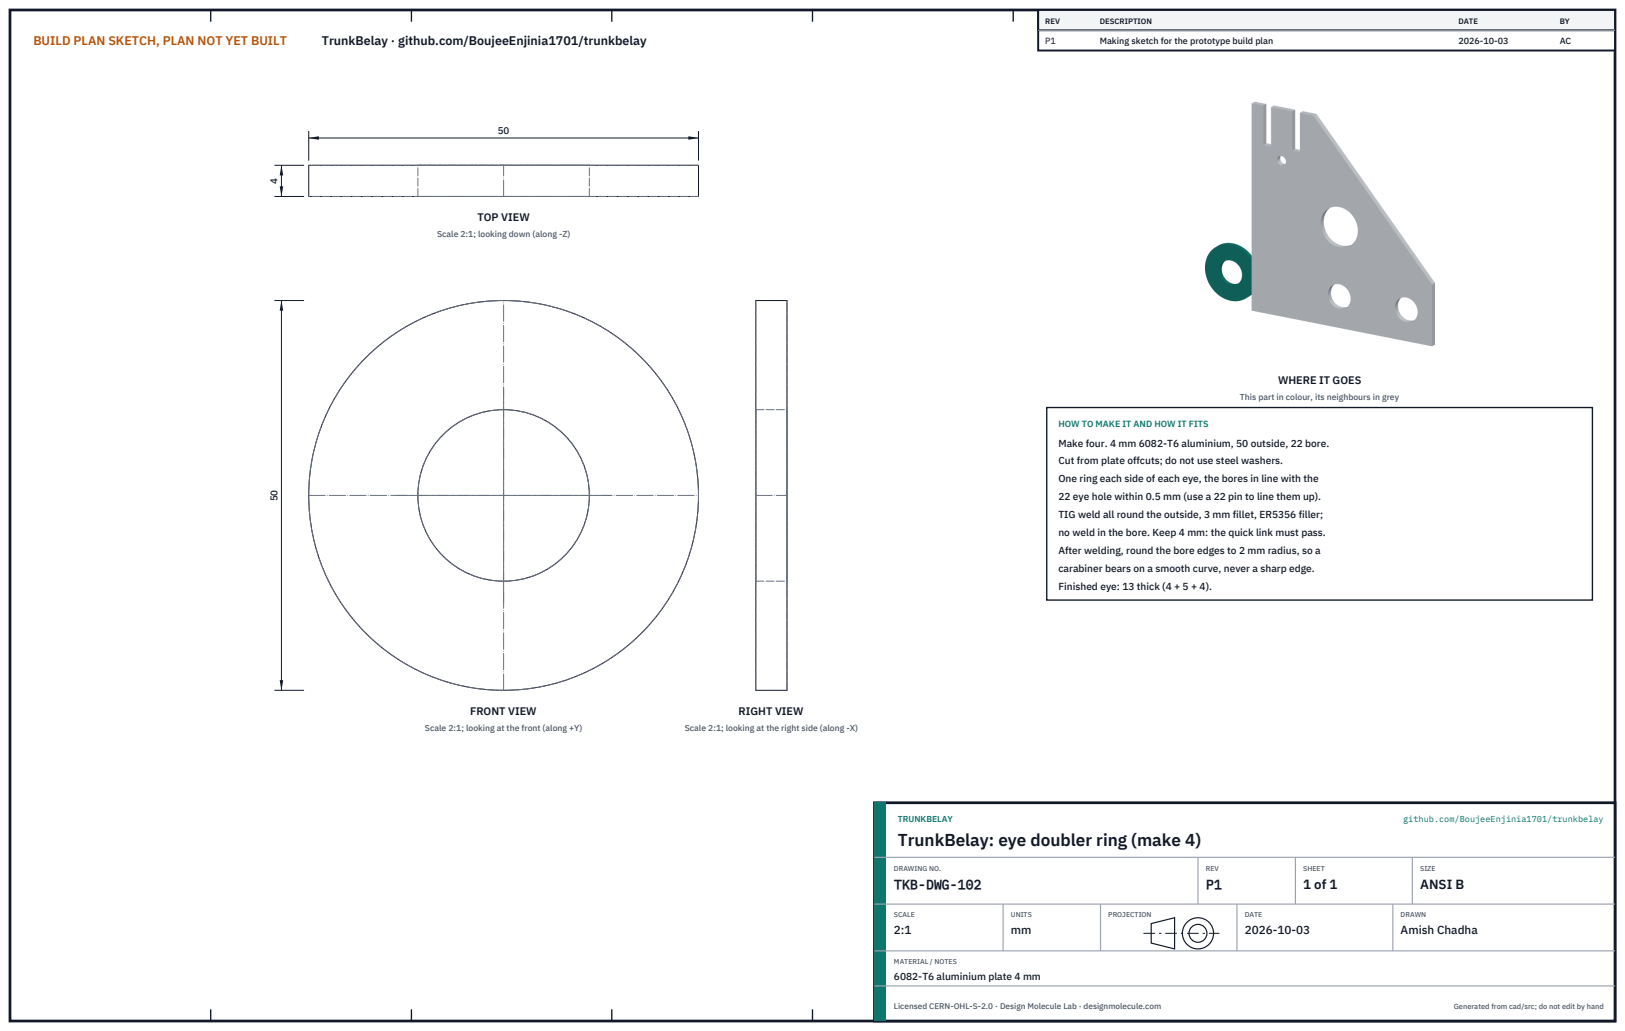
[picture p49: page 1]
BUILD PLAN SKETCH, PLAN NOT YET BUILT; TrunkBelay · github.com/BoujeeEnjinia1701/trunkbelay; FRONT VIEW; TOP VIEW; RIGHT VIEW; REV; DESCRIPTION; DATE; Making sketch for the prototype build plan; TRUNKBELAY; github.com/BoujeeEnjinia1701/trunkbelay; DRAWING NO. TKB-DWG-102; REV P1; SHEET 1 of 1; SIZE ANSI B; SCALE 2:1; UNITS mm; PROJECTION; DRAWN Amish Chadha; Licensed CERN-OHL-S-2.0 · Design Molecule Lab · designmolecule.com; Generated from cad/src; do not edit by hand

Scale 2:1; looking down (along -Z)

WHERE IT GOES

This part in colour, its neighbours in grey

HOW TO MAKE IT AND HOW IT FITS
Make four. 4 mm 6082-T6 aluminium, 50 outside, 22 bore.
Cut from plate offcuts; do not use steel washers.
One ring each side of each eye, the bores in line with the
22 eye hole within 0.5 mm (use a 22 pin to line them up).
TIG weld all round the outside, 3 mm fillet, ER5356 filler;
no weld in the bore. Keep 4 mm: the quick link must pass.
After welding, round the bore edges to 2 mm radius, so a
carabiner bears on a smooth curve, never a sharp edge.
Finished eye: 13 thick (4 + 5 + 4).

Scale 2:1; looking at the front (along +Y)

Scale 2:1; looking at the right side (along -X)

TrunkBelay: eye doubler ring (make 4)

MATERIAL / NOTES
6082-T6 aluminium plate 4 mm

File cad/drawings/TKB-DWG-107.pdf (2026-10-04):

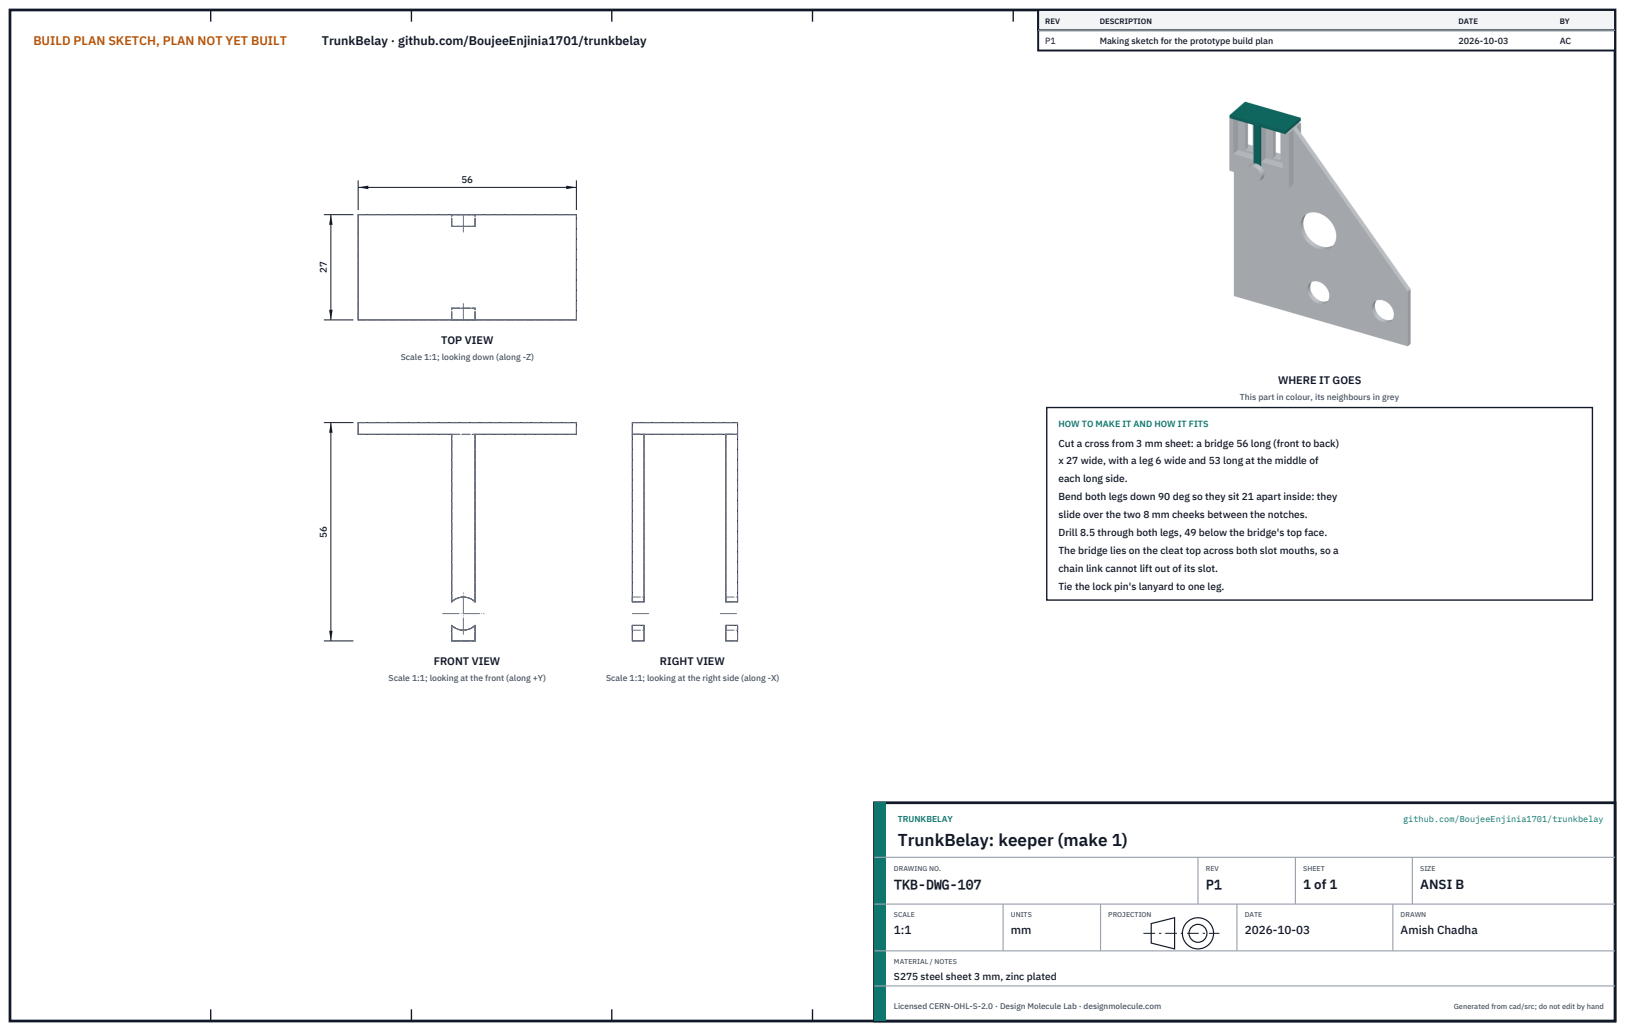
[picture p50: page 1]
BUILD PLAN SKETCH, PLAN NOT YET BUILT; TrunkBelay · github.com/BoujeeEnjinia1701/trunkbelay; FRONT VIEW; TOP VIEW; RIGHT VIEW; REV; DESCRIPTION; DATE; Making sketch for the prototype build plan; TRUNKBELAY; github.com/BoujeeEnjinia1701/trunkbelay; DRAWING NO. TKB-DWG-107; REV P1; SHEET 1 of 1; SIZE ANSI B; SCALE 1:1; UNITS mm; PROJECTION; DRAWN Amish Chadha; Licensed CERN-OHL-S-2.0 · Design Molecule Lab · designmolecule.com; Generated from cad/src; do not edit by hand

Scale 1:1; looking down (along -Z)

WHERE IT GOES

This part in colour, its neighbours in grey

HOW TO MAKE IT AND HOW IT FITS
Cut a cross from 3 mm sheet: a bridge 56 long (front to back)
x 27 wide, with a leg 6 wide and 53 long at the middle of
each long side.
Bend both legs down 90 deg so they sit 21 apart inside: they
slide over the two 8 mm cheeks between the notches.
Drill 8.5 through both legs, 49 below the bridge's top face.
The bridge lies on the cleat top across both slot mouths, so a
chain link cannot lift out of its slot.
Tie the lock pin's lanyard to one leg.

Scale 1:1; looking at the front (along +Y)

Scale 1:1; looking at the right side (along -X)

TrunkBelay: keeper (make 1)

MATERIAL / NOTES
S275 steel sheet 3 mm, zinc plated

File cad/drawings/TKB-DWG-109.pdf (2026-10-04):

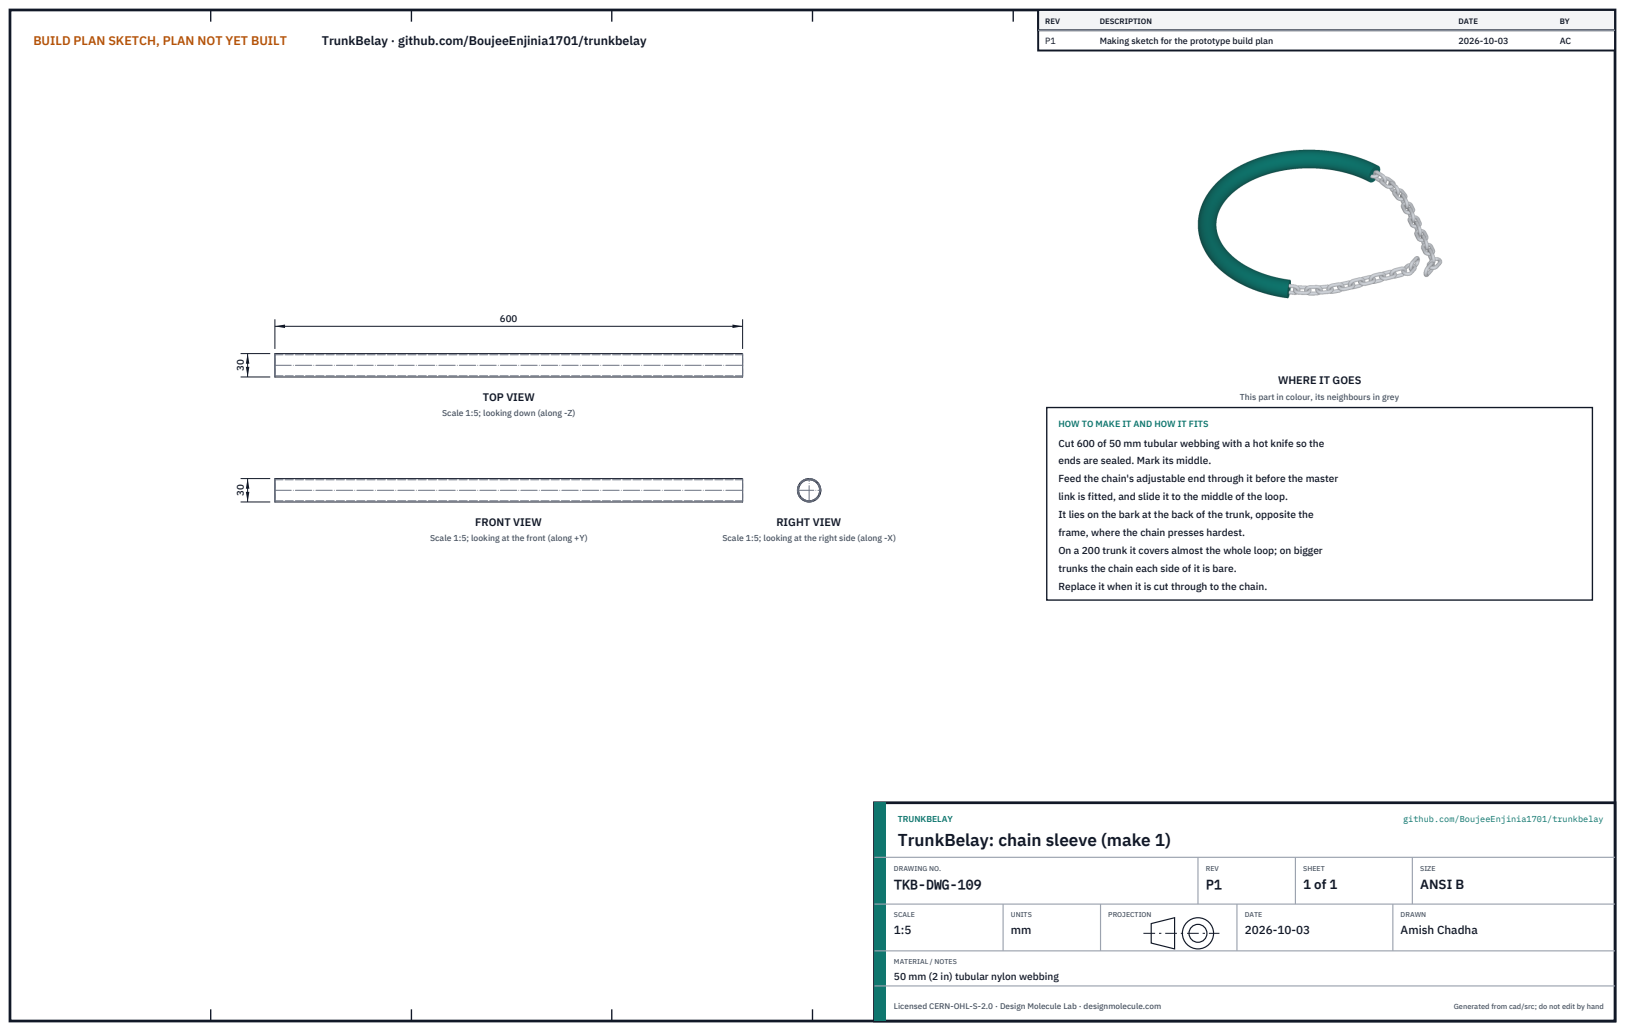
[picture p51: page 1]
BUILD PLAN SKETCH, PLAN NOT YET BUILT; TrunkBelay · github.com/BoujeeEnjinia1701/trunkbelay; FRONT VIEW; TOP VIEW; RIGHT VIEW; REV; DESCRIPTION; DATE; Making sketch for the prototype build plan; TRUNKBELAY; github.com/BoujeeEnjinia1701/trunkbelay; DRAWING NO. TKB-DWG-109; REV P1; SHEET 1 of 1; SIZE ANSI B; SCALE 1:5; UNITS mm; PROJECTION; DRAWN Amish Chadha; Licensed CERN-OHL-S-2.0 · Design Molecule Lab · designmolecule.com; Generated from cad/src; do not edit by hand

WHERE IT GOES

This part in colour, its neighbours in grey

Scale 1:5; looking down (along -Z)

HOW TO MAKE IT AND HOW IT FITS
Cut 600 of 50 mm tubular webbing with a hot knife so the
ends are sealed. Mark its middle.
Feed the chain's adjustable end through it before the master
link is fitted, and slide it to the middle of the loop.
It lies on the bark at the back of the trunk, opposite the
frame, where the chain presses hardest.
On a 200 trunk it covers almost the whole loop; on bigger
trunks the chain each side of it is bare.
Replace it when it is cut through to the chain.

Scale 1:5; looking at the front (along +Y)

Scale 1:5; looking at the right side (along -X)

TrunkBelay: chain sleeve (make 1)

MATERIAL / NOTES
50 mm (2 in) tubular nylon webbing

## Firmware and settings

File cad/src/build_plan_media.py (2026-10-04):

"""TrunkBelay prototype build plan pictures (TKB-BLD-001, STANDARDS section 18).

Run from the repo root:
    python cad/src/build_plan_media.py                       everything (heavy: better one group per process)
    python cad/src/build_plan_media.py overview
    python cad/src/build_plan_media.py sheets [101 102 ...]
    python cad/src/build_plan_media.py joints [1 2 ...]
    python cad/src/build_plan_media.py steps [1 2 ...]
Every picture is drawn from cad/src/model.py, so the pictures and the model never disagree:
    docs/05-build-plan/overview.png        every component pulled apart, numbered in build order
    cad/drawings/TKB-DWG-101 to 109        making sketches for the made components
    docs/05-build-plan/joint-NN.png        close-ups of the joints that need explaining
    docs/05-build-plan/step-NN.png         one picture per assembly step
Uses .kit/build_views.py. BUILD PLAN ILLUSTRATION, PLAN NOT YET BUILT.
"""
import sys
from pathlib import Path

ROOT = Path(__file__).resolve().parents[2]
sys.path[:0] = [str(ROOT / ".kit"), str(ROOT / "cad" / "src")]
import build_views as bv  # noqa: E402
from build_views import Part  # noqa: E402
import model as m  # noqa: E402
from model import PARAMS as P  # noqa: E402
from build123d import Box, Pos, Rot, Compound  # noqa: E402

OUT = ROOT / "docs" / "05-build-plan"
DWG = ROOT / "cad" / "drawings"
DATE = "2026-10-03"
_C = None

COL = {"spine": "#0F766E", "bars": "#64748B", "doublers": "#1D4ED8", "cheeks": "#7C3AED", "pads": "#111827",
       "pad_screws": "#9CA3AF", "keeper": "#B45309", "pin": "#DC2626", "chain": "#57534E", "sleeve": "#EAB308",
       "maillon": "#A16207", "carab": "#C2410C", "descender": "#15803D", "rope": "#0E7490", "triangle": "#F97316",
       "sling": "#2563EB", "bag": "#475569", "trunk": "#D6C7A1", "tag": "#BE185D"}


def comps():
    global _C
    if _C is None:
        _C = m.build_components(P)
    return _C


def D():
    return comps()["_D"]


def bx(x0, x1, y0, y1, z0, z1):
    return Pos((x0 + x1) / 2, (y0 + y1) / 2, (z0 + z1) / 2) * Box(x1 - x0, y1 - y0, z1 - z0)


def win(shape, x0, x1, y0, y1, z0, z1):
    """The part of a shape inside a box (for close-ups)."""
    w = bx(x0, x1, y0, y1, z0, z1)
    try:
        sols = list(shape.solids()) or [shape]
    except Exception:
        sols = [shape]
    kept = []
    for s_ in sols:
        bb = s_.bounding_box()
        if bb.max.X < x0 or bb.min.X > x1 or bb.max.Y < y0 or bb.min.Y > y1 or bb.max.Z < z0 or bb.min.Z > z1:
            continue
        try:
            r = s_ & w
            if r is not None and r.volume > 1e-3:
                kept.append(r)
        except Exception:
            pass
    return Compound(kept) if kept else None


def part(name, shape, color, explode=(0, 0, 0), alpha=1.0):
    return Part(name, shape, color, None, tuple(explode), alpha)


def K(key, name, explode=(0, 0, 0), col=None):
    return part(name, comps()[key], COL.get(col or key, "#64748B"), explode)


def W(key, name, box, explode=(0, 0, 0), col=None):
    s = win(comps()[key], *box)
    return None if s is None else part(name, s, COL.get(col or key, "#64748B"), explode)


def keep(ps):
    return [p for p in ps if p is not None]


def xs():
    return D()["x_s"]


def chain_all():
    c = comps()
    return c["chain_loop"] + c["chain_tail_a"] + c["chain_tail_b"]


def trunk(z0=-250, z1=320):
    return part("Palm trunk, 300 mm (or a test post)", m.trunk(P, None, z0, z1), COL["trunk"])


def kit(origin=(0.0, 0.0, 0.0)):
    return m.victim_kit(P, origin)


# ----------------------------------------------------------------- single components, laid square
def local():
    return m.frame_parts(P, m.derived(P))


def bar_flat():
    return Rot(0, 0, -120) * m._bar(P, m.derived(P), 1)


def pad_flat():
    return Rot(0, 0, -120) * m._pad(P, m.derived(P), 1)


def one_ring():
    return m._doublers(P, m.derived(P))[0]


def one_cheek():
    return m._cheeks(P, m.derived(P))[0]


def chain_sample(n=8):
    """A short straight piece of the chain with the master link and connecting link on its end."""
    lk = m.link_template(P)
    out = []
    for k in range(n):
        out.append(m.place(lk, (k * P["pitch"], 0, 0), (1, 0, 0), (0, 0, 1) if k % 2 else (0, 1, 0)))
    cl = m.place(m.stadium(14.0, 7.5, 4.0), (n * P["pitch"] + 2, 0, 0), (1, 0, 0), (0, 0, 1))
    st, ML, MW = P["master"]
    ml = m.place(m.master_template(P), (n * P["pitch"] + 18 + ML / 2, 0, 0), (1, 0, 0), (0, 1, 0))
    return m.fuse_all(out + [cl, ml])


def sleeve_flat():
    return m.rod((0, 0, 0), (P["sleeve"][0], 0, 0), P["sleeve"][1], P["sleeve"][1] - 1.5)


# ----------------------------------------------------------------- overview
def overview():
    c = comps()
    K_ = kit(origin=(xs() + 420, 380, 120))
    rope = (c["rope_brake"] + c["rope_load"]) & bx(-2000, 2000, -2000, 2000, -320, 200)
    parts = [
        part("Spine plate", c["spine"], COL["spine"], (0, 0, 0)),
        part("Eye doubler rings (4)", c["doublers"], COL["doublers"], (0, 0, -220)),
        part("Bearing bars (2)", c["bars"], COL["bars"], (-120, 0, -220)),
        part("Cleat cheeks (2)", c["cheeks"], COL["cheeks"], (0, 0, 220)),
        part("Rubber bark pads (2) and screws", c["pads"] + c["pad_screws"], COL["pads"], (-300, 0, -220)),
        part("Keeper", c["keeper"], COL["keeper"], (0, 0, 380)),
        part("Lock pin, ball-lock 8 mm", c["pin"], COL["pin"], (0, -250, 330)),
        part("Chain, grade 80, 110 links, with master link", chain_all(), COL["chain"], (-450, 0, 250)),
        part("Chain sleeve, tubular webbing", c["sleeve"], COL["sleeve"], (-650, 0, 250)),
        part("Tether quick link", c["maillon"], COL["maillon"], (0, 250, -250)),
        part("Carabiners (load and brake)", c["carab_main"] + c["carab_brake"], COL["carab"], (250, 0, -300)),
        part("Auto-locking descender", c["descender"], COL["descender"], (450, 0, -350)),
        part("Lowering rope, 30 m (top shown)", rope, COL["rope"], (450, 0, -450)),
        part("Victim carabiner", K_["carab_victim"], COL["carab"], (0, 0, 0)),
        part("Evacuation triangle", K_["triangle"], COL["triangle"], (0, 0, 0)),
        part("Chest sling", K_["chest_sling"], COL["sling"], (0, 0, 0)),
        part("Rope and carry bag", K_["bag"], COL["bag"], (0, 0, 0)),
        part("Tag line, 4 mm, and micro pulley", K_["tag_line"] + K_["micro_pulley"], COL["tag"], (0, 0, 0)),
    ]
    return bv.overview(parts, OUT / "overview.png", "TrunkBelay: the kit pulled apart, in build order",
                       "Numbered in build order; made aluminium frame parts first, then the bought chain, rigging, rescue gear and tag line",
                       elev=22, azim=-55, size=(11, 8), key=True)


# ----------------------------------------------------------------- making sketches
def sheet(n, shape, name, color, neighbours, title, material, notes, view_shape=None, inset=(24, -58)):
    p = part(name, shape, color)
    return bv.component_sheet(p, keep(neighbours), "TrunkBelay", f"TKB-DWG-{n}", f"TrunkBelay: {title}", material,
                              notes, DATE, out_dir=str(DWG), view_shape=view_shape, inset_view=inset)


def grey(name, shape):
    return part(name, shape, "#D1D5DB")


def sheets(which=None):
    c = comps()
    L = local()
    x0 = P["spine_set"]
    S = {}
    S[101] = lambda: sheet(101, c["spine"], "Spine plate", COL["spine"],
        [grey("bars", c["bars"]), grey("cheeks", c["cheeks"]), grey("doublers", c["doublers"])],
        "spine plate (make 1)", "6082-T6 aluminium plate 5 mm",
        ["One piece of 5 mm 6082-T6 aluminium plate, profile cut.",
         "  Outline from the front edge (the edge toward the trunk):",
         "  175 long at the bottom, 185 high at the front; 55 high at",
         "  the back end; the top runs 60 back, then slopes down.",
         "Holes: load eye 22 at 150 back, 28 up; spare eye 22 at 85",
         "  back, 28 up; lightening hole 36 at 85 back, 90 up.",
         "Chain slots: two, 7.5 wide, 35 deep from the top edge,"
         "  centred 15 and 43 back from the front edge. Cut them",
         "  square and file every edge smooth; no burr may touch chain.",
         "Lock pin hole 8.5 at 29 back, 139 up (drill after the cheeks",
         "  are welded on, through all three plates).",
         "Do not thicken the plate: a link must span it (6 mm at most).",
         "Round the eye edges to 2 mm radius after the rings go on."],
        inset=(20, -60))
    S[102] = lambda: sheet(102, one_ring(), "Eye doubler ring", COL["doublers"],
        [grey("spine", c["spine"])], "eye doubler ring (make 4)", "6082-T6 aluminium plate 4 mm",
        ["Make four. 4 mm 6082-T6 aluminium, 50 outside, 22 bore.",
         "Cut from plate offcuts; do not use steel washers.",
         "One ring each side of each eye, the bores in line with the",
         "  22 eye hole within 0.5 mm (use a 22 pin to line them up).",
         "TIG weld all round the outside, 3 mm fillet, ER5356 filler;",
         "  no weld in the bore. Keep 4 mm: the quick link must pass.",
         "After welding, round the bore edges to 2 mm radius, so a",
         "  carabiner bears on a smooth curve, never a sharp edge.",
         "Finished eye: 13 thick (4 + 5 + 4)."],
        inset=(20, -60))
    S[103] = lambda: sheet(103, c["bars"], "Bearing bar", COL["bars"],
        [grey("spine", c["spine"]), grey("pads", c["pads"])], "bearing bar (make 2, opposite hands)",
        "6082-T6 aluminium rectangular hollow section 50 x 40 x 3 mm",
        ["Make two, one a mirror image of the other. Aluminium RHS",
         "  50 x 40 x 3, the 50 face vertical; the 40 depth runs away",
         "  from the trunk. Length 175 along the trunk-side face; the",
         "  inner end is cut at 30 deg so it lies flat on the spine.",
         "TIG weld a 3 mm aluminium cap on the outer end (ER5356).",
         "  No vent hole: the frame is not galvanised.",
         "Drill two 9.0 holes through the trunk-side face only, 53 and",
         "  138 from the inner end on the centre line; after welding set",
         "  M6 countersunk-head stainless rivet nuts in them, flush.",
         "The two bars meet the spine at its foot and form a V with",
         "  120 deg between their trunk-side faces."],
        view_shape=bar_flat(), inset=(20, -60))
    S[104] = lambda: sheet(104, c["cheeks"], "Cleat cheek", COL["cheeks"],
        [grey("spine", c["spine"]), grey("keeper", c["keeper"])], "cleat cheek (make 2)", "6082-T6 aluminium plate 8 mm",
        ["Make two. 8 mm 6082-T6 aluminium plate, 60 long x 55 high.",
         "Two notches from the top edge, 22 wide and 37 deep, centred",
         "  15 and 43 from the front end, so they sit round the two",
         "  chain slots in the spine with 7.25 of web showing each side.",
         "Weld one on each face of the spine, top edges flush with the",
         "  spine top, front ends flush with its front edge: 5 mm TIG",
         "  fillets along the bottom and back end only (keep the notches",
         "  and the top clean).",
         "Then drill the 8.5 lock pin hole through cheek, spine and",
         "  cheek together, 29 from the front, 139 up from the frame foot."],
        view_shape=one_cheek(), inset=(20, -60))
    S[105] = lambda: sheet(105, m.frame_weldment(c), "Frame weldment", COL["spine"],
        [grey("pads", c["pads"]), grey("keeper", c["keeper"])], "collar frame weldment (make 1)",
        "6082-T6 aluminium parts above, TIG welded (ER5356), not galvanised",
        ["TIG weld the bars to the spine foot first (AC, ER5356), in a",
         "  jig that holds their trunk-side faces at 120 deg, bottoms",
         "  level. 5 mm fillets all round each bar end; the bar ends must not",
         "  stand proud of the spine's front edge.",
         "Then the four eye rings, then the two cheeks.",
         "Check: the V faces meet (if extended) 8 in front of the spine",
         "  front edge; both bar faces flat within 1 mm.",
         "Clean the bar faces, slots and eyes with a stainless brush;",
         "  run a 7 mm bar through both slots and the 8 pin through",
         "  its hole. Inspect every weld; no repair welding of a crack.",
         "Stamp SWL 100 kg ONE PERSON and the frame number on the spine."],
        inset=(20, -60))
    S[106] = lambda: sheet(106, c["pads"], "Rubber bark pad", COL["pads"],
        [grey("bars", c["bars"]), grey("spine", c["spine"])], "rubber bark pad (make 2)",
        "Natural rubber sheet with one fabric ply, 10 mm, 60 to 70 Shore A",
        ["Make two. Cut 155 x 50 from 10 mm fabric-ply rubber sheet.",
         "Drill two 6.5 holes on the centre line, 35 from each end, and",
         "  counterbore them 13 diameter, 4 deep from the trunk side, so",
         "  the screw heads sit 3 below the rubber face.",
         "Bond to the bar's trunk-side face with contact adhesive, the",
         "  inner end 15 from where the two pad faces would meet.",
         "Fit M6 x 30 countersunk stainless screws through the pad",
         "  into the rivet nuts in the bar face, with threadlocker.",
         "Replace a pad that is torn, glazed or soaked in oil."],
        view_shape=pad_flat(), inset=(20, -60))
    S[107] = lambda: sheet(107, c["keeper"], "Keeper", COL["keeper"],
        [grey("spine", c["spine"]), grey("cheeks", c["cheeks"]), grey("pin", c["pin"])], "keeper (make 1)",
        "S275 steel sheet 3 mm, zinc plated",
        ["Cut a cross from 3 mm sheet: a bridge 56 long (front to back)",
         "  x 27 wide, with a leg 6 wide and 53 long at the middle of",
         "  each long side.",
         "Bend both legs down 90 deg so they sit 21 apart inside: they",
         "  slide over the two 8 mm cheeks between the notches.",
         "Drill 8.5 through both legs, 49 below the bridge's top face.",
         "The bridge lies on the cleat top across both slot mouths, so a",
         "  chain link cannot lift out of its slot.",
         "Tie the lock pin's lanyard to one leg."],
        inset=(30, -60))
    S[108] = lambda: sheet(108, chain_sample(), "Chain set", COL["chain"],
        [grey("frame", m.frame_weldment(c))], "chain set (assemble 1)",
        "Bought: grade 80 alloy chain 6 mm, master link, connecting link",
        ["Buy 110 links of 6 mm grade 80 chain (about 1.98 m) with its",
         "  certificate, cut to length by the supplier. Count the links.",
         "Never weld, heat, grind or bend the chain.",
         "One end (the adjustable end): fit the master link with a",
         "  6 mm grade 80 connecting link and peen its pin.",
         "Other end (the fixed end): leave plain; it goes into the front",
         "  slot and a quick link ties its tail to the spare eye.",
         "Paint the 56th, 72nd and 100th links from the fixed end: the",
         "  link that drops into the rear slot on 200, 300 and 450 trunks.",
         "Drawn: eight links, the connecting link and the master link."],
        inset=(30, -60))
    S[109] = lambda: sheet(109, c["sleeve"], "Chain sleeve", COL["sleeve"],
        [grey("chain", c["chain_loop"])], "chain sleeve (make 1)", "50 mm (2 in) tubular nylon webbing",
        ["Cut 600 of 50 mm tubular webbing with a hot knife so the",
         "  ends are sealed. Mark its middle.",
         "Feed the chain's adjustable end through it before the master",
         "  link is fitted, and slide it to the middle of the loop.",
         "It lies on the bark at the back of the trunk, opposite the",
         "  frame, where the chain presses hardest.",
         "On a 200 trunk it covers almost the whole loop; on bigger",
         "  trunks the chain each side of it is bare.",
         "Replace it when it is cut through to the chain."],
        view_shape=sleeve_flat(), inset=(40, -60))
    for n in sorted(S):
        if which and n not in which:
            continue
        print(n, "->", S[n]())


# ----------------------------------------------------------------- joints
def joints(which=None):
    c = comps()
    x = xs()
    J = {}

    def jt(n, parts, title, sub, **kw):
        return bv.joint(keep(parts), OUT / f"joint-{n:02d}.png", f"Joint {n}: {title}", sub, **kw)

    foot = (x - 160, x + 60, -180, 180, -5, 60)
    J[1] = lambda: jt(1, [W("spine", "Spine plate", foot), K("bars", "Bearing bars (2)"), K("pads", "Rubber pads"),
                          K("pad_screws", "Pad screws", col="pad_screws")],
                      "bearing bars welded to the spine foot",
                      "The two aluminium bars form a 120 deg V; 5 mm TIG fillets all round each bar end on the spine faces",
                      elev=55, azim=-150)
    eye = (x + 120, x + 180, -20, 20, -5, 60)
    J[2] = lambda: jt(2, [W("spine", "Spine plate (cut)", eye), W("doublers", "Doubler rings (cut)", eye),
                          W("carab_main", "Load carabiner", (x + 120, x + 180, -40, 40, -100, 60), col="carab")],
                      "load eye with its doubler rings, cut open",
                      "Ring, 5 mm spine, ring: 13 mm of rounded aluminium under the carabiner bar", cut="+X", elev=20, azim=-60)
    top = (x - 10, x + 75, -45, 45, 120, 195)
    J[3] = lambda: jt(3, [W("spine", "Spine top with two slots", top), K("cheeks", "Cheeks (2)"), part("Keeper, lifted to show the slots", Pos(0, 0, 70) * c["keeper"], COL["keeper"]),
                          K("pin", "Lock pin"), W("chain_loop", "Chain links in the slots", top, col="chain"),
                          W("chain_tail_a", "Fixed end tail", top, col="chain"), W("chain_tail_b", "Adjustable end tail", top, col="chain")],
                      "the chain cleat: two links standing in the slots",
                      "Links stand in 7.5 mm slots; their neighbours bear on the 5 mm web in the 8 mm cheeks' notches",
                      elev=45, azim=-125)
    J[4] = lambda: jt(4, [K("bars", "Bearing bar"), K("pads", "Rubber pad"), K("pad_screws", "Countersunk screws", col="pad_screws")],
                      "rubber pad on a bearing bar, cut open",
                      "Bonded, plus two M6 screws with heads 3 mm below the rubber face", cut="-Y", elev=30, azim=-100)
    back = (-200, -60, -140, 140, 120, 200)
    J[5] = lambda: jt(5, [part("Trunk (bark)", win(m.trunk(P, None, 100, 220), -200, -100, -160, 160, 100, 220), COL["trunk"]),
                          W("sleeve", "Chain sleeve", back), W("chain_loop", "Chain", (-200, 40, -175, 175, 120, 200), col="chain")],
                      "the chain sleeve at the back of the trunk",
                      "600 mm of tubular webbing on the chain where it presses hardest on the bark", elev=30, azim=150)
    spare = (x + 50, x + 125, -40, 60, -60, 70)
    J[6] = lambda: jt(6, [W("spine", "Spine (spare eye)", spare), W("doublers", "Doubler rings", spare),
                          K("maillon", "Tether quick link"), W("carab_brake", "Brake carabiner", (x + 55, x + 125, -40, 40, -110, 60), col="carab"),
                          W("chain_tail_a", "Fixed end tail", (x + 20, x + 125, 0, 60, -60, 160), col="chain")],
                      "spare eye: tether quick link and brake carabiner",
                      "The fixed end of the chain is tied to the frame, so it cannot be dropped; the brake carabiner shares the eye",
                      elev=20, azim=-35)
    low = (x + 40, x + 290, -60, 60, -330, 60)
    J[7] = lambda: jt(7, [W("spine", "Spine", (x + 40, x + 200, -20, 20, -5, 60)), K("carab_main", "Load carabiner", col="carab"),
                          K("descender", "Auto-locking descender"), K("carab_brake", "Brake carabiner", col="carab"),
                          W("rope_brake", "Brake strand", low, col="rope"), W("rope_load", "Load strand, to the victim", low, col="rope")],
                      "descender and brake carabiner",
                      "Load strand straight down to the victim; brake strand turns 180 deg over the brake carabiner, then down",
                      elev=15, azim=-80)
    J[8] = lambda: jt(8, [part("Trunk, 300 mm", m.trunk(P, None, -60, 230), COL["trunk"]), K("bars", "Bearing bars"),
                          K("pads", "Rubber pads"), K("spine", "Spine"), K("cheeks", "Cheeks"), K("keeper", "Keeper"),
                          part("Chain", chain_all() & bx(-400, 600, -400, 400, 100, 210), COL["chain"]), K("sleeve", "Sleeve")],
                      "the collar on the trunk, seen from above",
                      "Pads touch the bark on two lines; the chain wraps the trunk once at 160 mm above the frame foot",
                      elev=70, azim=-90, size=(7, 5.5))
    for n in sorted(J):
        if which and n not in which:
            continue
        print(n, "->", J[n]())
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

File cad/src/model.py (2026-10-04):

"""TrunkBelay parametric model (build123d), constructable design (TRL 3, TKB-DDR-002; aluminium frame TKB-DDR-003).

Run from the repo root:
    python cad/src/model.py            export STEP and STL, run the constructability checks
    python cad/src/model.py --check    run the constructability checks only

TrunkBelay is a rescue kit that lets a fellow climber anchor and lower a climber stranded on a
coconut palm. A TIG-welded 6082-T6 aluminium collar frame (a 5 mm spine plate with two rubber-faced
bearing bars set in a 120 deg V at its foot; TKB-DDR-003) is held on the trunk by a 6 mm grade 80 chain that wraps the trunk
once and sits in two slots cut in the top of the spine (the chain cleat, stiffened by a cheek plate
on each face), held there by a sheet-steel keeper and a ball-lock pin. The fixed end is also tethered
to the spare eye with a quick link. The load
hangs from an eye at the outer end of the spine, 140 mm out from the frame, so the frame cocks on
the trunk: the bearing bars press the bark low on the near side and the chain presses it high on
the far side, and the grip rises with the load. An auto-locking rope descender on the eye lowers
the victim, who is fitted with an evacuation triangle and a chest sling, on 30 m of 11 mm
semi-static rope whose spare end runs down to the rope bag on the ground. A second (spare) eye takes a
carabiner for the chain tail or the bag while rigging.

Coordinates in mm. Z up; the trunk axis is the Z axis; the frame sits on the +X side of the trunk,
its foot (the bottom of the bearing bars) at Z = 0. The frame is built in a frame-local system with
the virtual vertex of the V (where the two pad faces would meet) at the origin and then moved out
by q0 = r / sin 60 deg, so the pad faces are tangent to a trunk of radius r.
PRELIMINARY, NOT FOR FABRICATION.
"""
from __future__ import annotations

import math
import sys
from pathlib import Path

from build123d import (Box, Cylinder, Location, Plane, Pos, Rot, Solid, Torus, Compound, Polyline,
                       make_face, extrude, export_step, export_stl)

ROOT = Path(__file__).resolve().parents[2]

PARAMS = {
    "trunk_d": 300.0,            # trunk used for the model and pictures (range 200 to 450, R3)
    "trunk_range": (200.0, 450.0),
    # bearing V
    "v_half": 60.0,              # angle of each pad face from the frame's centre plane, deg (120 deg V)
    "pad": (155.0, 10.0, 50.0),  # rubber pad: length along the face x thickness x height
    "pad_u0": 15.0,              # pad starts this far along the face from the virtual vertex
    "bar": (50.0, 40.0, 3.0),    # bearing bar RHS, 6082-T6: height x depth (away from the trunk) x wall (TKB-DDR-003)
    "bar_u1": 172.0,             # outer end of the bar along the face (end cap included)
    "cap_t": 3.0,
    # spine
    "spine_t": 5.0,              # also the web of the chain cleat: no thicker than 6 mm (link inner length less two wires)
    "frame_material": "aluminium",   # spine, bars, doublers and cheeks: 6082-T6, TIG welded (TKB-DDR-003)
    "spine_set": 8.0,            # spine front edge behind the virtual vertex
    "spine_pts": ((0, 0), (175, 0), (175, 55), (60, 185), (0, 185)),   # x' (from the front edge), z; top 185 for a deeper cleat web
    "eye_main": (150.0, 28.0), "eye_bag": (85.0, 28.0), "eye_d": 22.0,   # load eye and spare eye (spare clear of the deeper bars)
    "doubler": (50.0, 4.0),      # eye doubler ring OD x thickness, one each side of each eye
    "light_hole": (85.0, 90.0, 36.0),   # x', z, diameter
    # chain cleat: two slots in the top of the spine, stiffened by a cheek plate on each face
    "slots": (15.0, 43.0), "slot_w": 7.5, "slot_bottom": 150.0,
    "cheek": (60.0, 8.0, 130.0), # x' length x thickness x bottom z (top level with the spine top)
    "notch": (22.0, 148.0),      # notch in each cheek round each slot: width x bottom z
    "pin_xz": (29.0, 139.0), "pin_d": 8.0, "pin_hole": 8.5,
    "keeper": (56.0, 3.0, 6.0, 132.0),  # bridge length (X) x sheet thickness x leg width x leg bottom z
    "maillon": (8.0, 30.0, 11.0),  # tether quick link: wire x straight x bend radius (centre line)
    # chain, 6 mm grade 80
    "wire": 6.0, "pitch": 18.0, "link_w": 7.8,     # wire dia, inner length, inner width
    "chain_len_links": 110,      # links in the chain, both tails included
    "tail_b_out": -75.0,         # the adjustable tail hangs this far out on -Y, clear of the bar (TKB-DDR-003)
    "sleeve": (600.0, 15.0),     # tubular webbing sleeve length x radius on the chain
    "master": (10.0, 80.0, 45.0),   # master link stock x inner length x inner width
    # load side
    "carab": (10.0, 60.0, 20.0), # carabiner bar dia x straight length x bend radius (centreline)
    "desc": (75.0, 38.0, 150.0), # descender body X x Y x Z
    "rope_d": 11.0,
    "strand_dx": (-15.0, 15.0),  # brake and load strand offsets from the descender centre
    "bag": (200.0, 380.0),       # rope and carry bag diameter x height (kit pictures only)
    "load_end_z": -700.0,        # where the load strand is cut off in the pictures (to the victim)
    # tag line (TKB-DDR-003): 4 mm cord doubled through a micro pulley on the rescuer's harness, both ends on
    # the ground; the helpers tie the bag to one end and haul on the other
    "tag_line": (4.0, 55.0, 0.011),   # cord diameter mm, length m (2 x 25 m plus 5 m), mass kg/m
    "pulley": (30.0, 12.0),           # micro pulley sheave diameter x width (pictures only)
}

DENSITY = {"steel": 7.85e-6, "rubber": 1.5e-6, "aluminium": 2.70e-6}
SIN, COS = math.sin, math.cos


# ----------------------------------------------------------------- helpers
def _add(a, b):
    return tuple(x + y for x, y in zip(a, b))


def _sub(a, b):
    return tuple(x - y for x, y in zip(a, b))


def _mul(a, k):
    return tuple(x * k for x in a)


def _dot(a, b):
    return sum(x * y for x, y in zip(a, b))


def _norm(a):
    n = math.sqrt(_dot(a, a))
    return tuple(x / n for x in a)


def _cross(a, b):
    return (a[1] * b[2] - a[2] * b[1], a[2] * b[0] - a[0] * b[2], a[0] * b[1] - a[1] * b[0])


def rod(p0, p1, r, r_in=0.0):
    """Solid cylinder (or tube) between two points."""
    d = _sub(p1, p0)
    L = math.sqrt(_dot(d, d))
    pl = Plane(origin=p0, z_dir=_norm(d))
    s = Solid.make_cylinder(r, L, pl)
    if r_in > 0:
        s = s - Solid.make_cylinder(r_in, L, pl)
    return s


def obox(center, x_dir, z_dir, dx, dy, dz):
    """Box of size dx, dy, dz centred at center, its X along x_dir and Z along z_dir."""
    return Location(Plane(origin=center, x_dir=x_dir, z_dir=z_dir)) * Box(dx, dy, dz)


def fuse_all(shapes):
    out = None
    for s in shapes:
        out = s if out is None else out + s
    return out


def group(shapes):
    return Compound(list(shapes))
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

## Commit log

2026-10-03 TrunkBelay at TRL 3: constructable design (kit 1.7.0)
    Problem, concept and requirements; sizing calculations; CAD model, STEP and STL; general arrangement drawing; bill of materials; build plan with making sketches, joint close-ups and step pictures; design decisions register (design choices decided under Amish's 2026-10-03 pre-approval; requirement decisions open for Amish); TRL 2 and TRL 3 review; photoreal renders and storefront card. Private until Amish opens it.
    [bom.csv, results.csv, trunkbelay-assembly.step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]
2026-10-04 Carry Amish's round 2 requirement decisions into the design
    Amish approved all 47 recommendations on 2026-10-03 ("i approve all of the 47 recommendations provided by you. Execute them."). Each repo gains a decision record (DDR-003, or the next free number for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
    [bom.csv, results.csv, trunkbelay-assembly.step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]
2026-10-04 Carry Amish's round-2 and round-3 decisions into the design
    Amish approved all 46 round-2 recommendations ("i agree with all the 46 recommendations you provided. please proceed.") and all round-3 recommendations ("For round 3, I agree with all your proposed r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
    [bom.csv, results.csv, trunkbelay-assembly.step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]
2026-10-28 Kit 1.9.1 upgrade: pipeline documents and detailed CAD for every option
    Kit 1.9.1 installed (.kit, CLAUDE.md, .claude/commands). Kit 1.8 pipeline: STEM check with fixes under the 2026-10-23 standing instruction, concept options with the current design as option A, URS, PRS, generated RTM, REG, FEA, RSK with design FMEA, MKT, PLN and DDR; kit 1.9 D3 model of every option passing cad/fidelity.json; independent review recorded in the STEM check. Amish's 2026-10-25 decisions recorded where he approved a recommendation; all others proposed, awaiting Amish. Product renders and the options picture follow in a later commit where not yet included.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
2026-10-29 Add Cycles product renders and the concept options picture
    Blender Cycles renders of the kit 1.9.1 model, rendered on Amish's Mac and captioned; media/options.png from the D3 option models (this also clears the failing docs check, which needs the picture); cards and PDFs rebuilt. The options picture labels option A as the current design unless project.yaml records Amish's choice.
2026-10-29 Add the concept options picture rendered from the D3 option models
    media/options.png from Blender Cycles panels of every option, rendered on Amish's Mac; the label reads CURRENT DESIGN unless project.yaml records Amish's choice. Clears the docs check, which needs th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

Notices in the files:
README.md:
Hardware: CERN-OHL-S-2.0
